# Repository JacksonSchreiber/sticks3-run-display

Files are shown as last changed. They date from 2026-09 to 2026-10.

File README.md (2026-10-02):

# StickS3 run display

A wrist display that shows two numbers while running: **heart rate** from a Bluetooth chest strap, and **pace** from the phone's GPS. Built on an [M5Stack StickS3](https://docs.m5stack.com/en/core/StickS3) in a cast silicone band, with a clip mount as an alternative to the band.

The point is to keep Strava recording on the phone, untouched, and still see live numbers without buying a running watch.

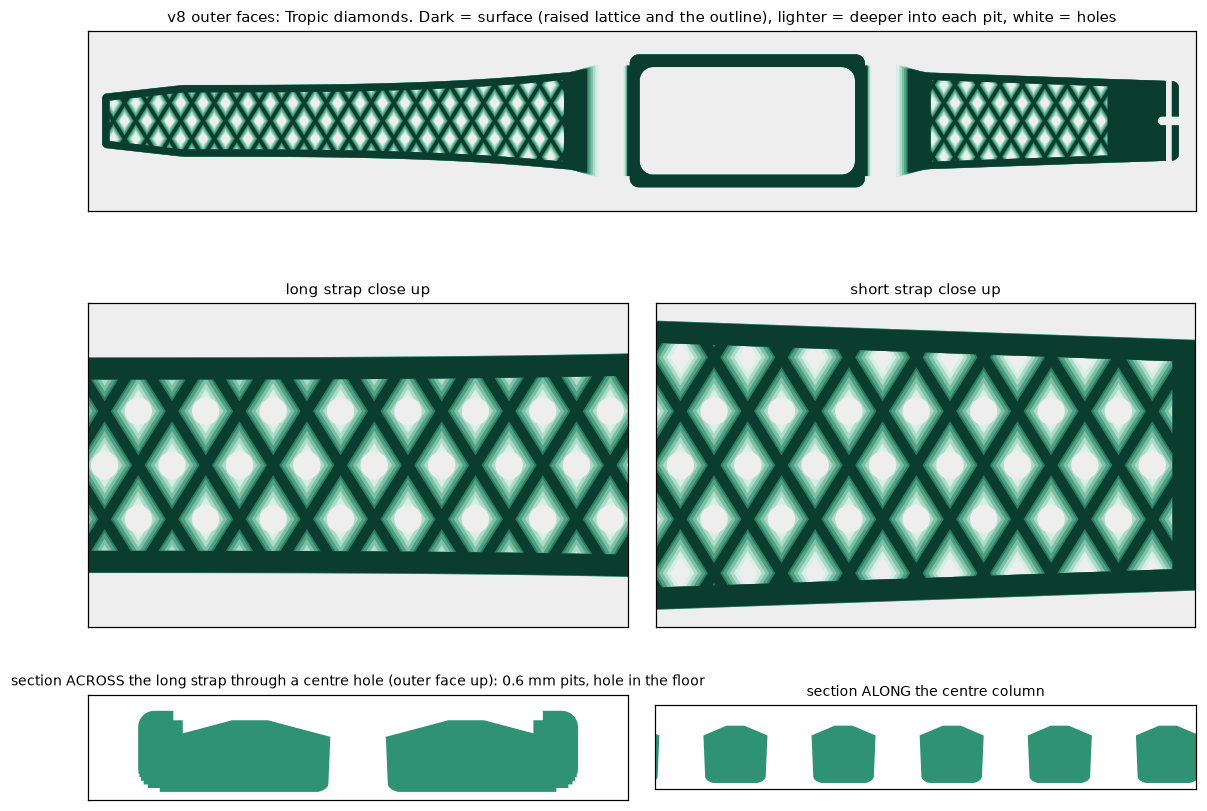
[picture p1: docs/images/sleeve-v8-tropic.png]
Band v8: outer faces tiled with Tropic diamond pits, the holes at their centres, with close ups and sections


*Band v8, the current design: a one-piece silicone band that flows out of a sealed jacket around the Stick, with Tropic-shaped straps: diamond pits tile the outer faces and the holes sit at their centres. The long strap tapers to a squared 12 mm tip; the short strap ends in a 4.5 mm thick tab with a cast hole for the spring bar of a real metal Tropic buckle and a slot for its tongue. Drawn from the mesh in `hardware/sleeve_v8/`.*

The earlier one-piece silicone band (a pocket in a cast band, no strap hardware) is still in `hardware/band/`:

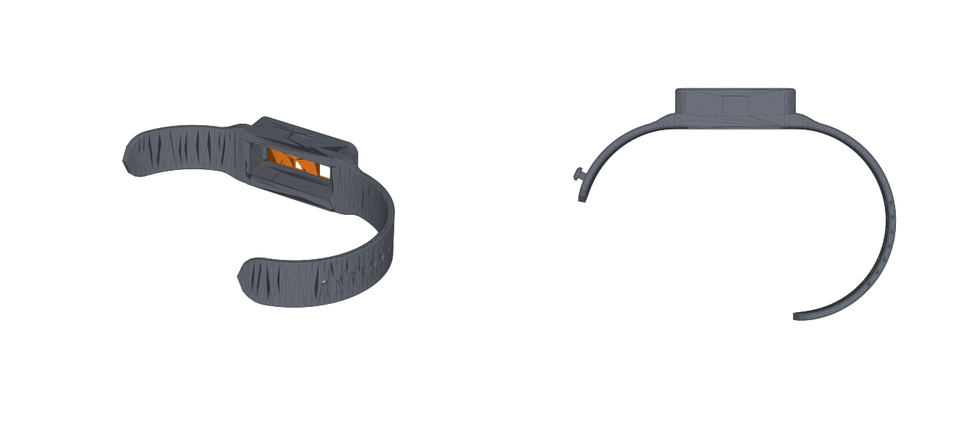
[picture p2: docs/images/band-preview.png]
The silicone band with the StickS3 in its pocket, and the band's side profile


## How it fits together

```
chest strap ──BLE──▶ phone ──BLE──▶ StickS3
                      │
              Strava (records the run, reads the strap itself)
              companion app (reads the strap, computes GPS pace,
                             sends both numbers ~1x/second)
```

The Stick never talks to the strap. It receives two numbers and displays them.

## Layout

| Path | What |
|---|---|
| `hardware/band/` | one-piece silicone band: 3-part mold (OpenSCAD source + STLs) |
| `hardware/clip/` | printed cradle that bolts to a steel spring clip (source + STLs) |
| `hardware/sleeve_v2/` | sealed silicone sleeve with cast-in lug staples for a standard 22 mm watch strap (source + STLs) |
| `hardware/sleeve_v3/` | sealed sleeve with the lugs under the ends (buried PETG frame with fins), 52 mm long (source + STLs) |
| `hardware/sleeve_v4/` | v3 with the frame flush in the back, 16 mm tall (source + STLs) |
| `hardware/sleeve_v5/` | one-piece silicone band + sealed jacket with a PETG peg buckle, Fitbit-style; cast twice (source + STLs) |
| `hardware/sleeve_v6/` | v5 band with a cast-in printed tang buckle, diamond-knurl straps, cast port slot; cast and run in (source + STLs) |
| `hardware/sleeve_v7/` | Tropic-shaped tapered straps for a real metal Tropic buckle (cast spring-bar hole and tongue slot), raised outline, knurl; cast twice, craters (source + STLs) |
| `hardware/sleeve_v8/` | current: v7 with Tropic perforation on both straps, smooth panels, breather holes and more vents (source + STLs) |
| `hardware/sleeve/` | earlier sleeve with a cast-in lug frame; superseded, kept for reference |
| `firmware/` | StickS3 firmware — not started |
| `app/` | Android companion app — not started |
| `docs/build-notes.md` | print settings, casting steps, assembly, tuning the fit |
| `docs/shopping-list.md` | everything to buy, with part numbers |

## Status

- **Band:** printed, cast and worn; fits well.
- **Sleeve:** v2 printed and cast, fits the Stick and the strap. v3 (lugs under the ends, 13 mm shorter) cast once: fit and strap work, but it sat 1 mm higher than the band and the first mold locked. v4 (frame flush with the back, 16 mm tall) is designed and verified. v5 drops the separate strap altogether: a one-piece band with the sealed jacket and a PETG peg buckle, cast twice and worn; the peg closure was awkward to use. v6 swapped in a printed tang buckle cast into the short strap: cast and run in, but the spring bar popped out of the printed lugs. v7 drops printed hardware altogether: Tropic-shaped straps that take a metal Tropic buckle on its own spring bar; cast twice, both with air craters. v8 adds Tropic perforation, breather holes and a brushed print-coat procedure, designed and verified, not yet cast.
- **Clip mount:** designed, not printed.
- **Firmware and app:** working. Real chest-strap heart rate reaches the Stick over BLE while Strava records the same strap; GPS pace is implemented but the outdoor walk test and the Stick battery run-down are still to do.

## Design decisions worth knowing

- **Dimensions** come from M5Stack's K150 drawing and official 3D model, not from measurements.
- **The Stick slips in and out of the band** — the silicone lip holds it, and the pocket covers USB-C, so charging means popping it out.
- **The clip keeps USB-C reachable,** so it charges in place.
- **All fasteners** come from one M2/M3 metric screw assortment.

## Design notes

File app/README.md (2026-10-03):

# Android companion app

Bridges the chest strap and the phone's GPS to the StickS3, while Strava records the run normally. It also records each run itself and can upload it to Strava with heart rate — for treadmill runs, where Strava's own recording missed it (see *Strava upload*).

Gradle project root is this folder; the single module is `app/`. Package / applicationId `dev.runstick.app`. Kotlin, plain Android Views, no Compose, no DI, no navigation library.

## What it does

While Strava records on the same phone, this app reads the strap over the standard Heart Rate service (0x180D), computes pace from GPS Doppler speed, and writes one 9-byte `DATA` packet per second to the RunStick, per `docs/ble-protocol.md`. A foreground service plus a partial wake lock keeps it going for 1-3 h with the screen off.

## Layout

| File | What |
|---|---|
| `app/src/main/java/dev/runstick/app/PacketEncoder.kt` | `RunData` -> 9 bytes LE, plus `StatusDecoder` for the 2-byte `STATUS` notification. Pure. |
| `HeartRateParser.kt` | 0x2A37 payload -> bpm (flags bit 0 picks u8 / u16 LE). Pure. |
| `PaceEstimator.kt` | time-aware EMA over `Location.getSpeed()` -> seconds per mile, or null. Pure. |
| `RunTracker.kt` | elapsed time + distance integrated from speed. Pure. |
| `HrZones.kt` | heart-rate zone 1-5 from % of max HR, with 2 bpm hysteresis. Pure. |
| `StrapClient.kt` | raw `BluetoothGatt` client for the strap. |
| `StickClient.kt` | Nordic `BleManager` client for the RunStick. |
| `RunService.kt` | foreground service: owns both clients + GPS, ticks at 1 Hz, holds the `UiState` flow. |
| `MainActivity.kt` | permissions, device pickers, start/stop, live readout, last workout + Strava setup, battery help. |
| `DevicePicker.kt` | the "which device?" dialog (connected devices + filtered scan). |
| `WorkoutLog.kt` | one recorded run (start time, 1 Hz HR + distance samples), its line-based file format and summaries. Pure. |
| `WorkoutStore.kt` | `filesDir/workouts/` (newest 50 kept; delete/prune report removals so Prefs entries go too) and the incremental `WorkoutRecorder`. java.io only. |
| `TcxWriter.kt` | `WorkoutLog` -> TCX v2 (no GPS positions), with the distance override. Pure. |
| `StravaApi.kt` | Strava URLs, form/multipart bodies, JSON parsing. Pure. |
| `UploadForm.kt` | upload dialog defaults, time/pace/miles parsing, the time-distance-pace calculator, stretch note. Pure. |
| `WorkoutUi.kt` | shared by both screens: the store factory, the summary line, the upload flow and dialog. |
| `WorkoutsActivity.kt` | workout history: upload / upload again, open on Strava, delete. |
| `StravaClient.kt` | token exchange/refresh, upload + poll over `HttpURLConnection`. |
| `StravaJobs.kt` | process-wide scope + state for connect/upload, so rotation doesn't cancel them. |
| `Prefs.kt` | strap MAC, stick MAC, simulate flag, Strava credentials and tokens, uploaded activity ids. |
| `app/src/test/…` | JUnit4 tests for the pure classes, including the protocol doc's golden vector and TCX golden output. |

## Rules that are easy to break

- **Never write CCCD `0x0000` to the strap, and never touch its CCCD on teardown.** Android gives each app its own GATT client over one shared link, but the strap's CCCD is one value on the device. Disabling it would silently stop Strava's heart-rate stream mid-run. Subscribing writes `0x0001` (idempotent); stopping is `disconnect()` + `close()` on our own client and nothing else. A failed CCCD write is not an error — arriving notifications are the only proof that matters.
- **Connect to the strap by saved MAC, not by scanning.** A strap that Strava already holds has stopped advertising, so a scan will never find it; `connectGatt()` on the address works either way. Scanning is only used for first-time picking, alongside `getConnectedDevices(GATT)`.
- **The service is started from the visible activity only.** That is what lets it use location without `ACCESS_BACKGROUND_LOCATION`, which is deliberately not requested. `START_NOT_STICKY` for the same reason.
- **Foreground service types are computed at runtime.** `connectedDevice` always; `location` only when not simulating and fine location is granted — claiming `location` without the permission throws on Android 14+.

## Heart-rate zones

Set **Max heart rate** on the main screen (120-230 bpm; unset by default) and the Stick shows the current zone as a coloured digit next to `BPM`: Z1 under 60% of max, Z2 60-70, Z3 70-80, Z4 80-90, Z5 90+. The zone moves up only once HR is 2 bpm past a boundary and down only once it is 2 bpm below, so it doesn't flicker at 1 Hz. It travels in DATA `flags` bits 5-7 (`docs/ble-protocol.md`) and only with a valid HR. The dialog shows the highest HR in saved runs as a hint, never filled in automatically (strap spikes). These are standard %-of-max zones; Strava's may differ unless set to match.

## Simulate mode

A persisted switch on the main screen. Ignores the strap and GPS and sends synthetic data (HR sweeping from 52% to 97% of max HR and back every two minutes so every zone colour shows, or of 190 when no max is set, in which case no zone is sent; pace 7:30-9:30, elapsed and distance ticking), so the Stick can be tested indoors. Location permission is not requested in this mode; Bluetooth still is, because it is still writing to a real Stick.

## Strava upload

Strava's own recording didn't capture heart rate on treadmill runs, so the app records every run itself and can upload it to Strava as a Run with heart rate and pace.

**Recording.** Every run (real or simulated) is written to `filesDir/workouts/workout_<startEpochMs>.csv`: one row per second with the same heart rate and distance the Stick is sent (HR blank when the strap has no fresh value). It is flushed every 5 s, so a crash loses a few seconds at most. Runs under 60 s are discarded; the newest 50 are kept. Recording needs no GPS fix — on a treadmill it just records HR with zero distance.

**Auto-stop.** If the strap has sent heart rate at least once in a run and then nothing arrives for 5 minutes (strap taken off, Stop forgotten), the run stops itself through the normal Stop path and a notification plus an on-screen note say so. Runs that never saw a heart rate (no strap) never auto-stop, and shorter dropouts are ignored.

**Trim.** An auto-stopped run is saved only up to its last heartbeat, so duration, distance and the uploaded TCX exclude the idle 5 minutes (the file is rewritten via a temp file + rename). A manual Stop saves the run untrimmed; the 60 s minimum applies after trimming.

**Upload.** *Last workout* on the main screen shows the newest run; **Upload to Strava** asks for a name, the time, the distance in miles or the pace, and whether it was a treadmill (`trainer=1`), builds a TCX file (time, distance and HR per second, no GPS positions) and posts it to Strava's upload API, then polls until the activity exists. The result links to the activity, and the workout is marked uploaded; uploading it again asks first and offers to open the old activity: while it still exists on Strava, Strava will most likely reject the new upload as a duplicate (its message is shown as-is), so delete it there first. Each attempt gets its own `external_id`; on success the new activity id replaces the old one. The app never deletes anything on Strava.

**All workouts.** Lists every kept workout, newest first (not the one being recorded). Tap one to upload it (or upload again), open it on Strava, or delete it from the phone; deleting leaves the Strava activity alone. Upload and Delete are disabled while an upload is running.

**Treadmill distance.** GPS gives no distance indoors, so type the treadmill's distance at upload time. If the recorded distance is under 100 m (none, or just GPS drift), the typed distance is spread evenly over the run, i.e. a constant pace. If there is a real recorded distance, the typed value rescales it, keeping the pace variations. Leaving the box at its prefilled value uploads the recorded distance unchanged.

**Typing what the treadmill shows.** Time is the anchor (mm:ss or h:mm:ss). Distance and pace are two views of one number: typing either fills in the other, and changing the time keeps whichever was typed last (on a GPS run nothing typed means the pace is kept, so the distance scales with the time). The upload uses the time and distance boxes. A typed time different from the recording *rescales* the whole timeline onto it, so Strava shows exactly the treadmill's time and the HR trace keeps its shape; nothing is trimmed, since the app can't know when the belt started. The dialog notes "Heart-rate trace is stretched to fit", in the warning colour beyond a 15% change. Squeezing to a shorter time drops samples that land on the same second, so the average HR can move slightly.

**One-time setup.**

1. On <https://www.strava.com/settings/api> create an API application (any name/website). Set **Authorization Callback Domain** to `localhost`.
2. In the app tap **Set up Strava**, paste the **Client ID** and **Client Secret**, tap **Connect**.
3. Strava (app or browser) asks for permission. Leave the **upload activities** permission ticked — without it the app cannot upload and tells you so.
4. You come back to RunStick showing *Strava: connected*. Tokens refresh themselves; if Strava ever refuses the refresh, the app asks you to connect again.

The redirect is `runstick://localhost/strava`, which is why the callback domain is `localhost`.

**Credentials live only on the phone.** Client ID, secret and tokens are kept in the app's private SharedPreferences (`allowBackup` is false) and are never logged. Nothing about your Strava app is in this repo; if you fork it, create your own API application.

## Versions

Set in `gradle/libs.versions.toml`, so one file changes them all.

| | |
|---|---|
| AGP | 9.4.1 (needs Gradle >= 9.6, JDK 17, build-tools 36) |
| Gradle wrapper | 9.7.1 |
| Kotlin | whatever AGP 9 bundles — see below |
| compileSdk / targetSdk / minSdk | 36 / 36 / 31 |
| Nordic BLE | `no.nordicsemi.android:ble:2.11.0` |

**AGP 9 compiles Kotlin itself.** The `org.jetbrains.kotlin.android` plugin is *rejected* by AGP 9 (`android.builtInKotlin` defaults to true), so it is not applied anywhere and no Kotlin version is declared. `kotlin.compilerOptions.jvmTarget` defaults to `android.compileOptions.targetCompatibility`, which is why JDK 17 is set only in the `compileOptions` block and there is no `kotlin { }` block. If that ever needs reverting: uncomment `android.builtInKotlin=false` in `gradle.properties`, the `kotlin` version + `kotlin-android` plugin lines in `gradle/libs.versions.toml`, and the plugin alias in `app/build.gradle.kts`.

androidx and coroutines versions are pinned conservatively — they are known to resolve and nothing here needs a newer API. Bump them in the catalog if you want.

## Building

There is no Gradle wrapper checked in yet. Generate it once on Windows (from an existing Gradle install or Android Studio), which creates `gradlew.bat` and `gradle/wrapper/gradle-wrapper.jar`; `gradle/wrapper/gradle-wrapper.properties` is already here and points at Gradle 9.7.1.

Gradle must run as a **Windows** process, never inside WSL — see `tools/env.sh`. It expects:

- `JAVA_HOME` = `C:\Program Files\Eclipse Adoptium\jdk-17*`
- `ANDROID_HOME` = `%LOCALAPPDATA%\Android\Sdk` — or create `app/local.properties` with `sdk.dir=C\:\\Users\\<you>\\AppData\\Local\\Android\\Sdk` (it is gitignored)
- `adb.exe` from the WinGet `Google.PlatformTools` package

From Windows, in this folder:

```
gradlew.bat test                 # JVM unit tests only, no device needed
gradlew.bat assembleDebug        # app/build/outputs/apk/debug/app-debug.apk
gradlew.bat installDebug         # build + install over adb
```

`tools/build-app.sh` and `tools/install-app.sh` are the WSL-side wrappers (not written yet — they belong outside this folder). They should source `tools/env.sh` and then:

```sh
# build-app.sh
cmd.exe /c "cd /d $REPO_WIN\\app && set JAVA_HOME=$JAVA_HOME_WIN&& gradlew.bat assembleDebug"

# install-app.sh
"$ADB" install -r "$REPO_WSL/app/app/build/outputs/apk/debug/app-debug.apk"
```

## First run on the phone

1. Grant permissions (Bluetooth, location, notifications).
2. **Pick RunStick** — scans for service `7a1c0001-…`; the Stick must be powered and advertising.
3. **Pick strap** — devices already connected (i.e. held by Strava) are listed first and labelled; otherwise it scans for 0x180D.
4. Open the **battery** card: tap *Ignore battery optimisation*, then on a Samsung set Settings → Apps → RunStick → Battery → **Unrestricted** and add the app to **Never auto sleeping apps**.
5. Start Strava, then Start here. Order does not matter, but step 3 is easiest with Strava already connected, since that proves both apps can read the strap at once.

## Still open

- **Milestone 1:** confirm Strava and this app read the strap at the same time on this phone. Everything above is written to make that possible, but it has not been tried.
- Pace will not match Strava's exactly — each app smooths GPS differently. This one uses a time-aware EMA with alpha 0.22 at 1 Hz (~8 s), rejects samples with speed accuracy worse than 1 m/s, and shows `--` below 0.5 m/s or after 10 s with no usable sample. Distance uses a tighter 4 s gap limit than pace's 10 s staleness window, so a dropout can't invent ground.

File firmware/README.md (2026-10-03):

# StickS3 firmware

Runs on the M5Stack StickS3 (ESP32-S3). Its whole job is to receive two numbers
over Bluetooth LE and display them large enough to read at a glance mid-stride.

The Stick is a dumb BLE peripheral: it never talks to the chest strap or the
GPS. The phone app writes one 9-byte packet about once a second and the Stick
draws it. The wire format is `docs/ble-protocol.md` — that file is the contract,
change it first.

## Files

| Path | What |
|---|---|
| `runstick/runstick.ino` | setup/loop, screen state machine, buttons, power management, serial log |
| `runstick/config.h` | UUIDs, timings, brightness steps, colours, portrait layout |
| `runstick/protocol.h` | `RunData` + `parsePacket()` + the format helpers — no Arduino/M5/NimBLE dependency |
| `runstick/ble_link.h` | NimBLE server, advertising, callbacks, thread-safe packet handoff, STATUS notify |
| `runstick/ui.h` | sprite drawing for the boot / main / extras / sleeping screens |

Header-only on purpose: the `.h` files are included from the `.ino` and compile
as one translation unit, so everything is `inline`/`static`.

## Building

```
tools/build-firmware.sh
```

That wrapper runs the Windows `arduino-cli.exe` through WSL interop (see
`tools/env.sh`) so the compile never uses WSL memory. What it does, in effect:

```
arduino-cli compile --fqbn m5stack:esp32:m5stack_sticks3 \
  --build-path 'C:\dev\.build\runstick' firmware/runstick
arduino-cli upload  --fqbn m5stack:esp32:m5stack_sticks3 -p COM7 firmware/runstick
```

Pinned versions this was written against:

| Thing | Version |
|---|---|
| core | `m5stack:esp32@3.3.9` (Arduino-ESP32 3.x) |
| `M5Unified` | 0.2.22 |
| `M5GFX` | 0.2.29 |
| `NimBLE-Arduino` | 2.5.1 |

The BLE code targets the **NimBLE 2.x** API, which is not the API in most
tutorials: advertising does not restart itself after a disconnect, the device
name is not added to the advertisement for you, and the callbacks carry a
`NimBLEConnInfo&`. See the comment block at the top of `ble_link.h`.

### Serial

115200 baud over native USB CDC. If the port enumerates but prints nothing, the
board menu option is not set to CDC — add it to the FQBN:

```
--fqbn m5stack:esp32:m5stack_sticks3:CDCOnBoot=cdc
```

### Self-test

`protocol.h` carries the golden vector from the protocol doc. Build with

```
--build-property "compiler.cpp.extra_flags=-DRUNSTICK_SELFTEST"
```

and the Stick parses it at boot and prints a PASS/FAIL line per check to Serial:
field decode, the second (zone 4) vector and the `hr_zone` bits, short/long/null/wrong-version rejection, and every display
format (`8:45`, `1:02:03`, `7.12 mi`). Leave the flag off for normal builds.

## Screen

Portrait, 135 wide x 240 tall — the Stick lies *across* the wrist.

```
 ┌─────────────────┐
 │ ● LINK      87% │  status strip: link dot + state, battery %
 ├─────────────────┤
 │                 │
 │      152        │  heart rate, white, as large as 135 px allows
 │       BPM       │  label red
 ├─────────────────┤
 │                 │
 │      8:45       │  pace, white
 │       /MI       │  label cyan
 └─────────────────┘
```

The link dot is green when a fresh packet arrived within 5 s, amber when the
data has gone stale, grey while waiting for a phone.

Digit size is **measured, not guessed**: `fitBigText()` in `ui.h` walks a short
list of fonts (the 75 px and 48 px 7-segment fonts first, then FreeSansBold as a
full-ASCII safety net), measures the actual string with `textWidth()`, and picks
whichever renders the tallest digits that still fit the box. So `99` gets more
height than `152`, and `12:34` more than `8:45` would need. At boot the
per-glyph width table for every candidate font is dumped to Serial, which is the
first place to look if a number ever comes out clipped or blank.

Everything is drawn into one 135x240 `M5Canvas` sprite and pushed in a single
blit, so nothing flickers. The screen is only repainted when something changed,
or once a second regardless.

### Stale rule

No valid DATA packet for 5 s → both numbers become a dark grey `--` and the
strip shows `STALE`. If the link drops, the last numbers stay on screen for the
remainder of those 5 s rather than blanking instantly. If a packet arrives with
a field's valid bit clear (or pace `0xFFFF`), just that field shows `--`.

### Extras screen

`BtnA` short press. Shows elapsed time, distance, the Stick's own battery
(`CHG` when charging) and the phone-side flags (`GPS ok` / `STRAP ok`). Returns
to the main screen after 5 s, or on another `BtnA` press.

## Buttons

`M5.BtnA` is the front button (GPIO11); `M5.BtnB` is the side KEY2 (GPIO12).
The other side button belongs to the PMIC and is not software-readable — hold it
for download mode, double-click it to power off.

| Button | Action | Effect |
|---|---|---|
| A | short press | toggle the extras screen (auto-returns after 5 s) |
| B | short press | cycle the backlight: 40 → 110 → 220 → 40 (saved in NVS, default 110) |
| B | hold ≥ 1 s | flip the screen 180° for the other wrist (saved in NVS) |

Both B actions are on raw press/release edges rather than M5Unified's
`wasClicked()`/`wasHold()`, so the 1 s threshold is exactly 1 s. The long press
fires the moment it is reached, and the release is then swallowed.

## Power

- CPU is dropped to 80 MHz once BLE is up (the floor with the radio on) and the
  loop idles at ~20 ms.
- Connection parameters are requested at 300–500 ms / latency 0 / 6 s timeout,
  since the phone only writes at 1 Hz.
- IMU, mic, speaker and the Grove 5 V output are disabled in `M5.config()`.
- **Idle power-off:** 10 minutes with no phone *and* not on USB → a 3 s
  "Sleeping" notice, then `M5.Power.powerOff()`. A button press, a phone
  connecting, or USB going in during those 3 s cancels it.

## Serial log

One line a second while connected, plus a line for every connect/disconnect
(with the NimBLE reason code):

```
[run] hr=152 pace=8:45  t=1:02:03 d=7.12 mi flags=0x1F HR PACE RUN GPS STRAP age=412ms batt=87% 4012mV -83mA pkt=123 bad=0
```

`mA` is signed (negative = discharging) and is there to tune the 2 h battery
target against. If it reads a constant `0`, this board has no current sense —
that is the hardware, not the logging.

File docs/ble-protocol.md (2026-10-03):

# BLE protocol: phone → RunStick

This file is the contract between `firmware/` and `app/`. Change it first, then both sides.

## Roles

- **Stick = BLE peripheral / GATT server.** It only displays what it is sent.
- **Phone app = BLE central / GATT client.** It reads the chest strap and GPS and writes one packet about once a second.

## Advertising

| Field | Value |
|---|---|
| Local name | `RunStick` (in the advertising data itself, not only the scan response) |
| Service UUID | `7a1c0001-5f3e-4b2a-9c6d-2f8e41d0b7a5` (advertised) |
| Connectable | yes; restarts advertising on every disconnect |

The app finds the Stick by service UUID, then remembers its MAC address.

## GATT

Service `7a1c0001-5f3e-4b2a-9c6d-2f8e41d0b7a5`

| Characteristic | UUID | Properties | Direction |
|---|---|---|---|
| `DATA` | `7a1c0002-5f3e-4b2a-9c6d-2f8e41d0b7a5` | write without response (also accepts write) | phone → Stick |
| `STATUS` | `7a1c0003-5f3e-4b2a-9c6d-2f8e41d0b7a5` | read, notify | Stick → phone |

No pairing or bonding. Default MTU is enough.

### DATA — 9 bytes, little-endian

| Offset | Type | Field | Notes |
|---|---|---|---|
| 0 | u8 | `version` | `1`. The Stick ignores packets with an unknown version or the wrong length. |
| 1 | u8 | `flags` | see below |
| 2 | u8 | `hr_bpm` | heart rate; `0` when not valid |
| 3 | u16 | `pace_s_per_mile` | seconds per mile; `0xFFFF` when not valid (stopped, no GPS) |
| 5 | u16 | `elapsed_s` | seconds since the run started (wraps after 18.2 h) |
| 7 | u16 | `distance_cmi` | distance in 0.01 mile units |

`flags` bits:

| Bit | Name | Meaning |
|---|---|---|
| 0 | `HR_VALID` | `hr_bpm` is a fresh reading from the strap |
| 1 | `PACE_VALID` | `pace_s_per_mile` is usable |
| 2 | `RUN_ACTIVE` | the run timer is running |
| 3 | `GPS_OK` | the phone has a usable GPS fix |
| 4 | `STRAP_OK` | the phone is connected to the chest strap |
| 5–7 | `hr_zone` | 3-bit heart-rate zone, `(flags >> 5) & 7`: `0` = none / unknown, `1`–`5` = zone. `6` and `7` are treated as `0` on receive. |

A field is shown only if its valid bit is set; otherwise the Stick shows `--`.

**`hr_zone`.** The phone computes the zone (percent of the runner's max heart rate, with hysteresis so it doesn't flicker on a boundary) and sends it only when `HR_VALID` is set; otherwise the bits are `0`. The Stick shows it as a coloured digit next to the `BPM` label, only while the heart rate itself is shown. Bits 5–7 used to be "reserved, send `0`, ignore on receive", and the length and `version` are unchanged: firmware from before this field never checked those bits (its `parsePacket` accepts any `flags` value and reads only bits 0–4), so a newer app works with an older Stick, which simply shows no zone. An older app sends `0`, which means "no zone".

**Golden test vectors** (both sides unit-test against them):

```
HR 152, pace 8:45 /mi (525 s), elapsed 1:02:03 (3723 s), distance 7.12 mi (712), all five flags set, zone 0

01 1F 98 0D 02 8B 0E C8 02
```

```
The same, with hr_zone 4: flags = 0x1F | (4 << 5) = 0x9F

01 9F 98 0D 02 8B 0E C8 02
```

### STATUS — 2 bytes

| Offset | Type | Field | Notes |
|---|---|---|---|
| 0 | u8 | `battery_pct` | 0–100 |
| 1 | u8 | `status_flags` | bit 0 = charging |

Notified when either byte changes, and at least every 60 s while connected.

## Timing

- The phone writes `DATA` at **1 Hz**, including when values are invalid, so the Stick can tell "connected but no data" from "link lost".
- **Stale rule:** if the Stick gets no valid `DATA` packet for **5 s**, it greys out the numbers to `--` and shows a no-link indicator. It keeps advertising / waiting and recovers on the next packet.
- Preferred connection parameters requested by the Stick: interval 300–500 ms, latency 0, supervision timeout 6 s. The phone may ignore these.

## Display formats (Stick)

| Value | Format | Example |
|---|---|---|
| heart rate | integer | `152` |
| heart-rate zone | one digit `1`–`5` right of the `BPM` label, coloured per zone; nothing for `0` | `4` |
| pace | `m:ss`, capped at `59:59` | `8:45` |
| elapsed | `h:mm:ss` (or `mm:ss` under an hour) | `1:02:03` |
| distance | two decimals + `mi` | `7.12 mi` |

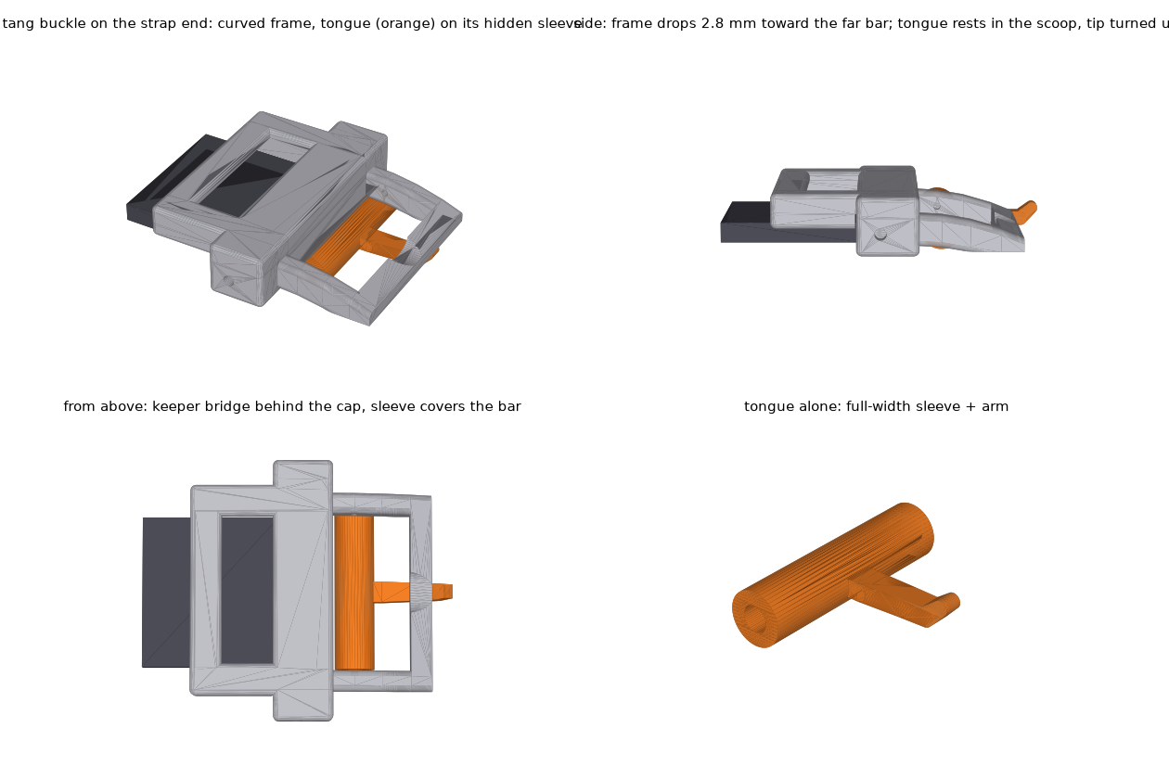
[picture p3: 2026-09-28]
docs/images/buckle-tang.png

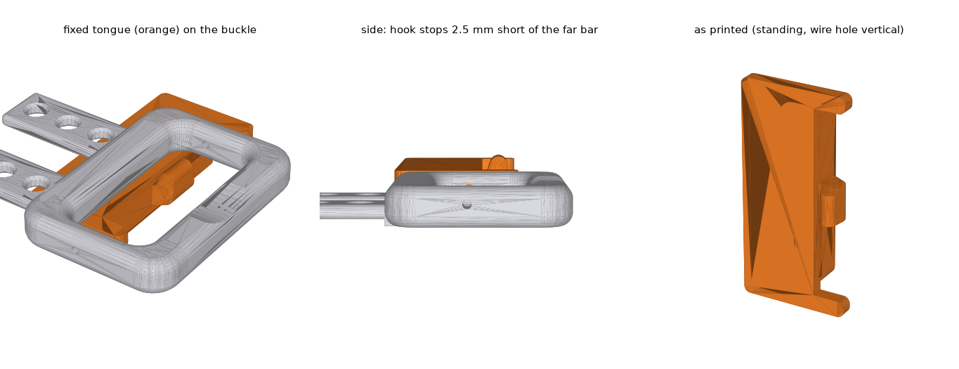
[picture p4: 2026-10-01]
docs/images/fixed-tongue.png

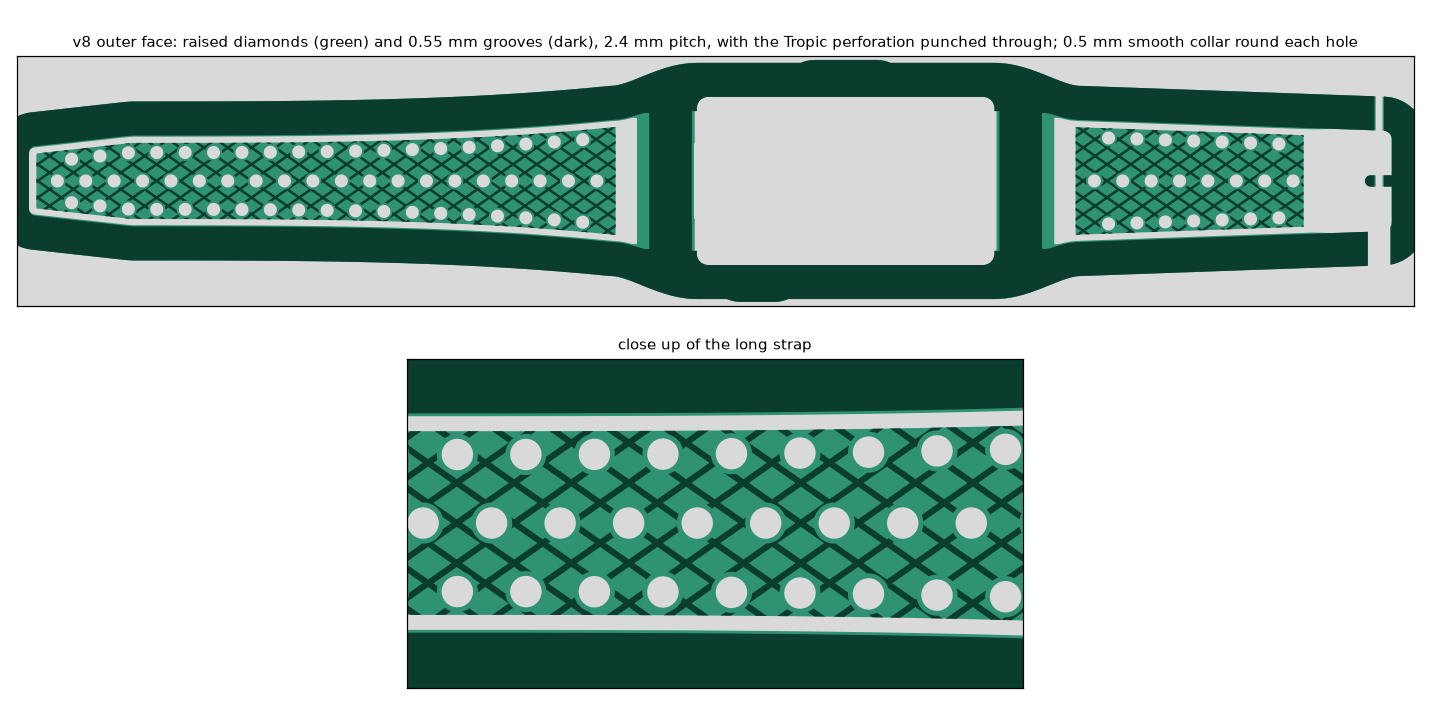
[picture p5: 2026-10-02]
docs/images/sleeve-v8-knurl.png

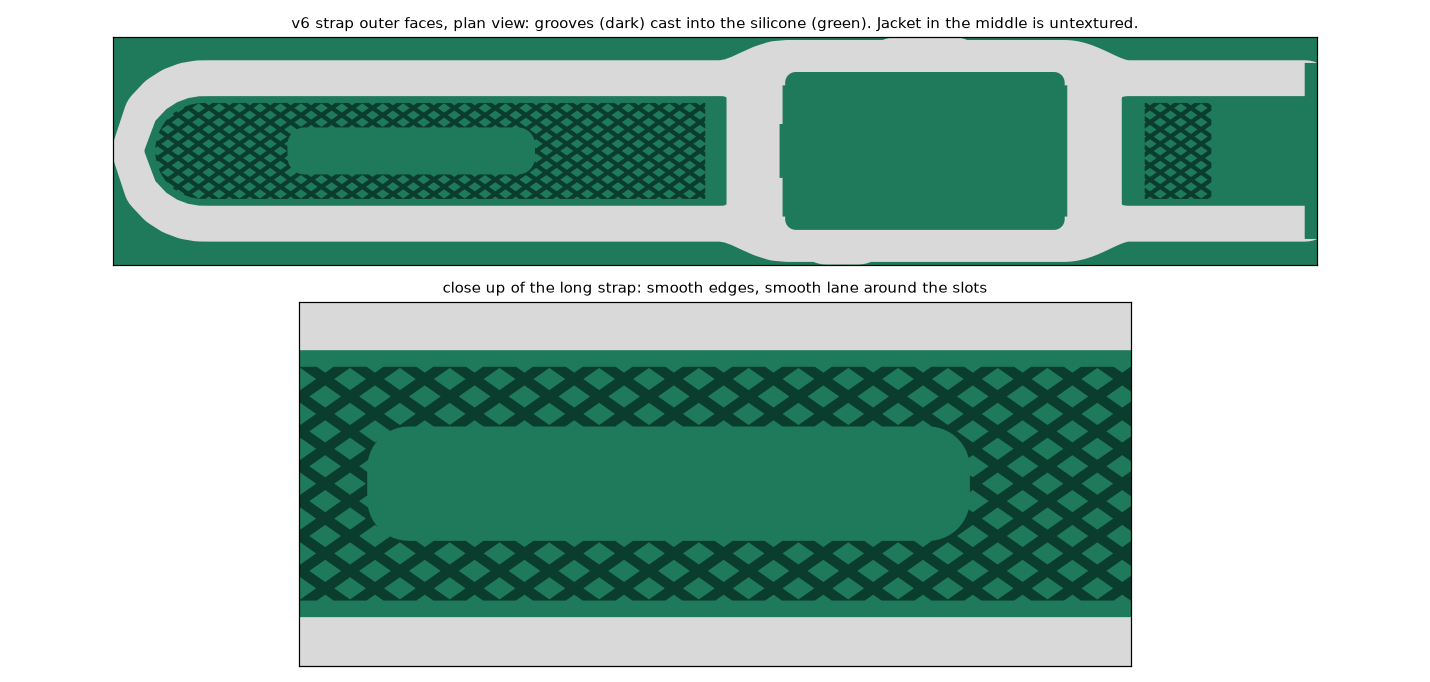
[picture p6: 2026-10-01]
docs/images/sleeve-v6-texture.png

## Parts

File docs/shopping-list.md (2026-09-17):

# Shopping list

Prices are what was listed when this was written; check before ordering.

## Electronics

- **M5Stack StickS3** (K150) — $21.50
- **Chest strap:** Coospo H9Z (USB rechargeable, ~50 h per charge) — $43.89 on sale, or Coospo H808S (CR2032 coin cell, ~300 h) — $35.09. Any strap using the standard Bluetooth heart rate service works.
- **USB-C data cable** — charge-only cables can't program the Stick

## 3D printing

The Adventurer 5M ships with a glue stick, diagonal pliers, hex keys and a 50 g PLA sample.

- **PLA filament, 1.75 mm, 1 kg** — mold and core
- **PETG filament, 1.75 mm, 1 kg** — clip mount
- **Digital calipers**
- **Isopropyl alcohol, 90%+** — cleaning the build plate
- **Sandpaper, 220-800 grit** — flattening the mold parting faces
- Optional: deburring tool, airtight bin + desiccant for filament

## Silicone casting

- **Smooth-On Smooth-Sil 945, 2 lb trial kit** (skin safe, Shore 45A, 1:1 by weight). Amazon alternative: SORTA-Clear 37, also skin safe, slightly softer, 4 h cure.
- **Mann Ease Release 200** — mold release spray
- **Silc Pig black pigment** (or any pigment made for platinum-cure silicone) — 1.5-2% by weight, never over 3%
- **Digital scale, 0.1 g**
- **Graduated mixing cups and wooden stir sticks**
- **Vinyl gloves** — latex stops platinum silicone from curing
- **60 ml catheter-tip syringes**, 2-3
- **3 mm leather hole punch** — strap holes
- **Hobby knife** — trimming the seam and vent nubs
- Safety glasses, mostly for the aerosol release spray

## Clip

- **theclip.com MCS-631SS** stainless spring clip — $4.25. Alternative: MCS-661, shorter but coated steel.

## Fasteners

One metric screw assortment covers every part: M2/M3, socket-cap or button head, with nuts and washers. Confirm the size chart lists **M2x6** and **M3x30**. Stainless holds up better than black alloy steel against sweat.

## Software (free)

- **Orca-Flashforge / Flash Studio** — slicer
- **OpenSCAD** — only to change a design
- **Arduino IDE 2** and **Android Studio** — later, for firmware and the app

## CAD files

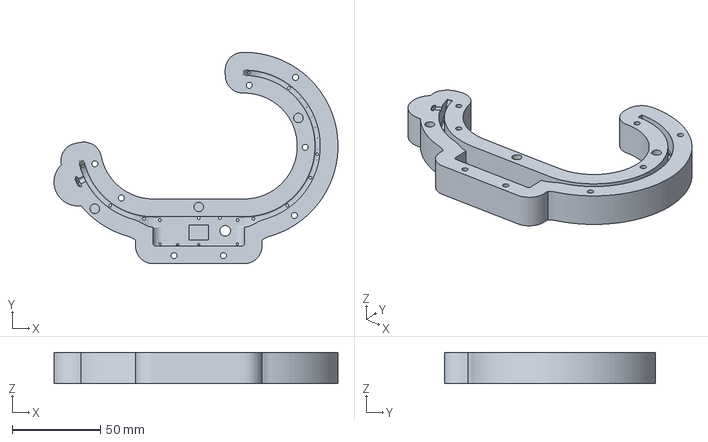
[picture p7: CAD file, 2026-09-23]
hardware/band/print/band_mold_top.3mf
160.8 x 119.6 x 17.8 mm

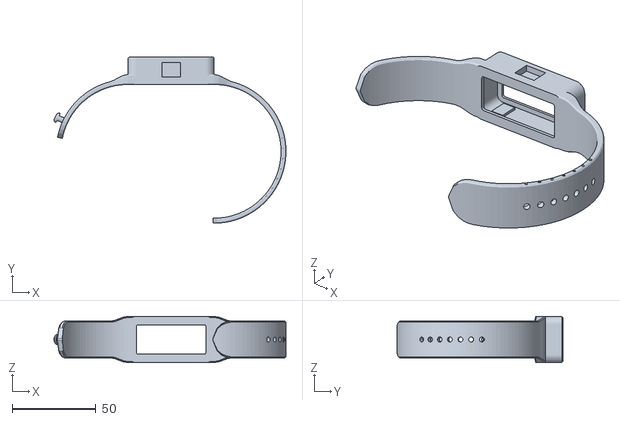
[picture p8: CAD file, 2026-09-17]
hardware/band/stl/band_preview_not_for_printing.stl
138.9 x 99.6 x 27.6

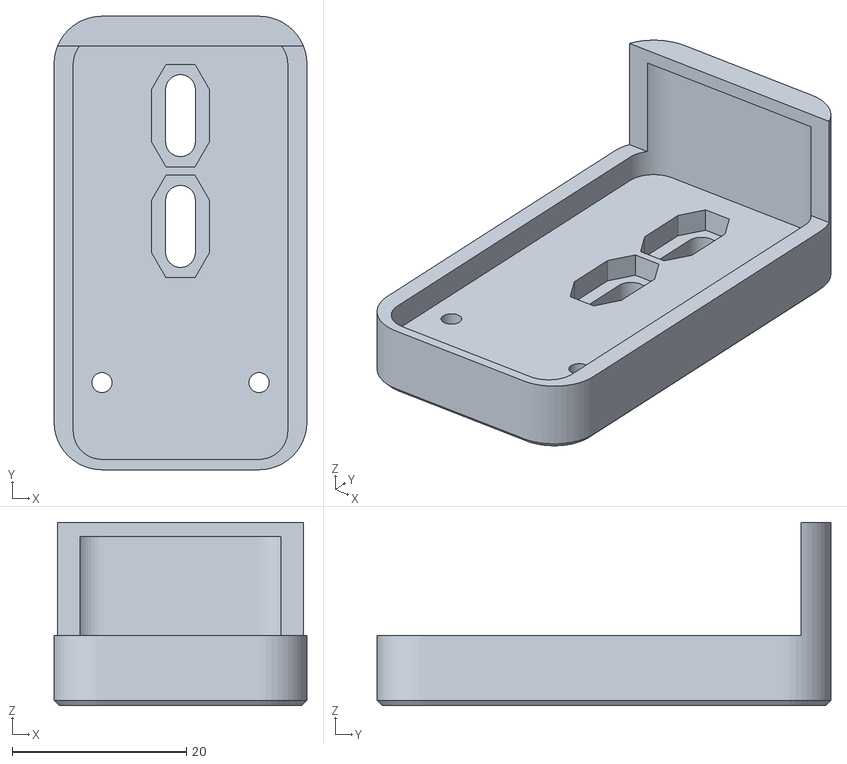
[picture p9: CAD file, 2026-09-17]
hardware/clip/stl/clip_mount_661.stl
29.0 x 52.0 x 21.0

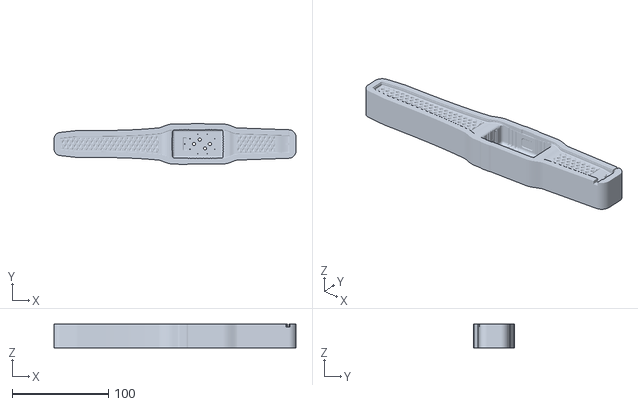
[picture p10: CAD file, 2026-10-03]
hardware/sleeve_v8/stl/band_cup.stl
252.0 x 42.6 x 24.9

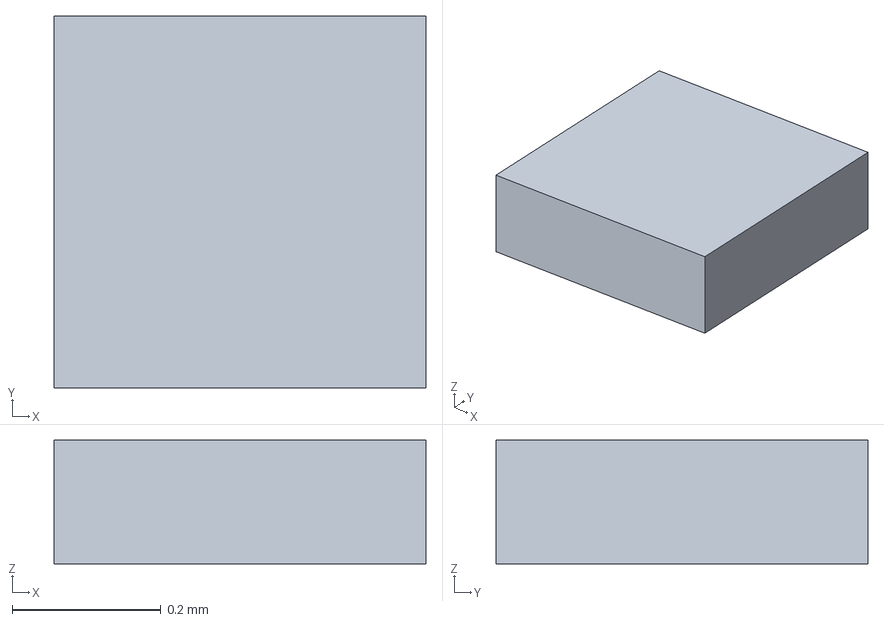
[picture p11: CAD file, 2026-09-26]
tools/heat_45C_6hrs.3mf
0.5 x 0.5 x 0.167 mm

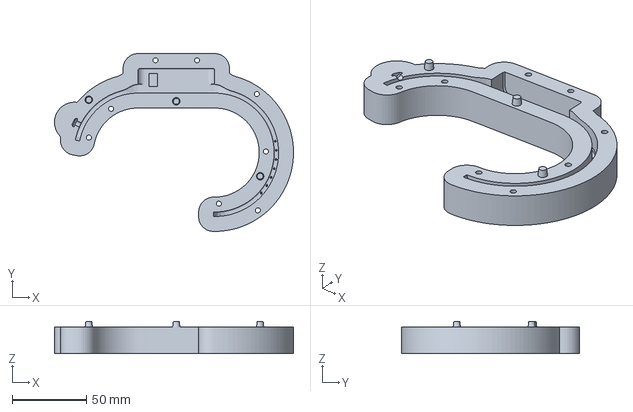
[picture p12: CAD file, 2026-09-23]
hardware/band/print/band_mold_bottom.3mf
160.8 x 119.6 x 21.8 mm

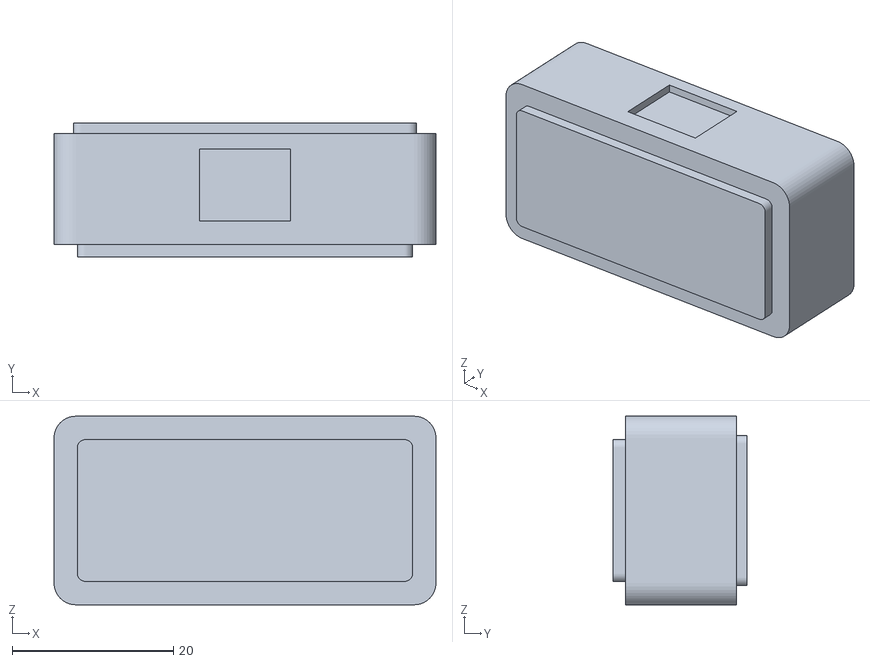
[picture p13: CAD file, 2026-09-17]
hardware/band/stl/band_core_tighter.stl
47.4 x 16.6 x 23.4

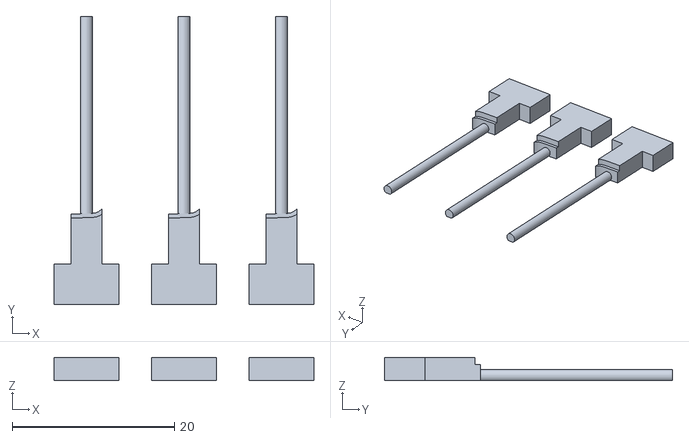
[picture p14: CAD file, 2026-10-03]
hardware/sleeve_v8/stl/band_pin_x3.stl
32.0 x 35.5 x 2.85

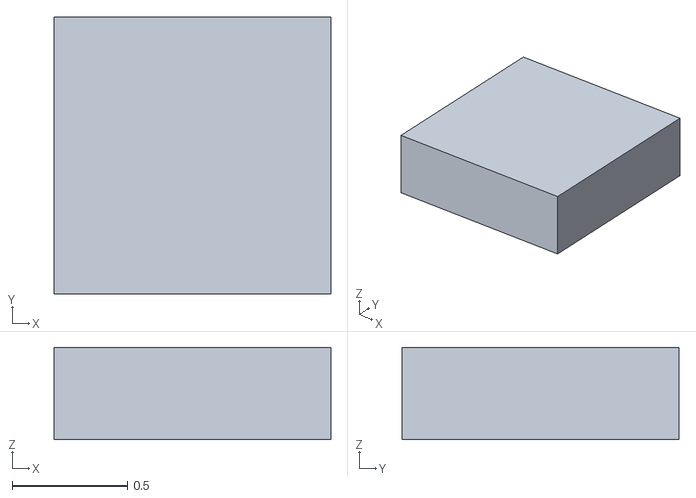
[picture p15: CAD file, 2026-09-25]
tools/dot_1mm.stl
1.20 x 1.20 x 0.4

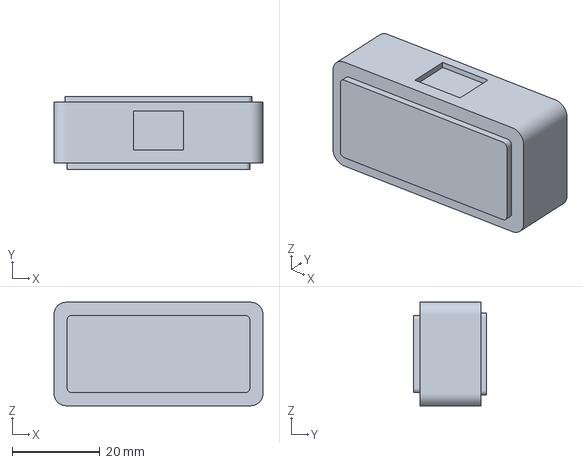
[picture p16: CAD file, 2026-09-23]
hardware/band/print/band_core_default.3mf
47.6 x 16.6 x 23.6 mm

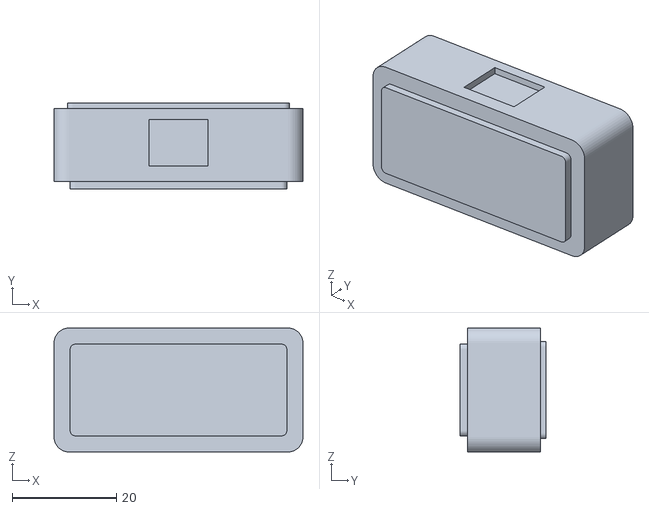
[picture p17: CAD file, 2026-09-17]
hardware/band/stl/band_core_looser.stl
47.8 x 16.6 x 23.8

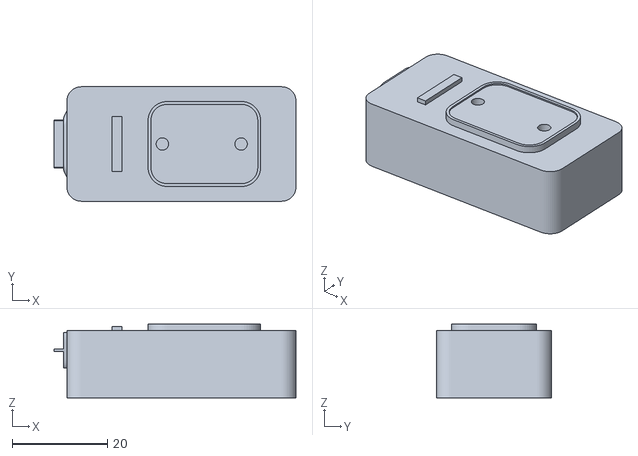
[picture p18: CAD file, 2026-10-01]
hardware/sleeve_v8/stl/band_core.stl
50.7 x 24.0 x 15.5

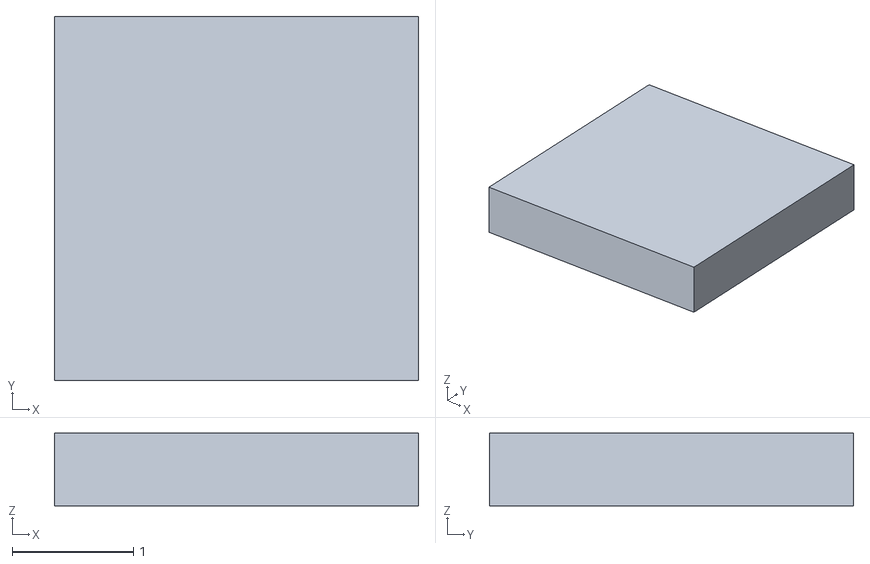
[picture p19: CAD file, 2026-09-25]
tools/dot_3mm.stl
3.00 x 3.00 x 0.6

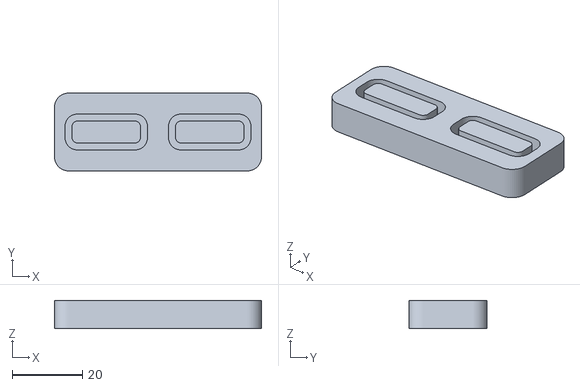
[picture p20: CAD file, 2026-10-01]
hardware/sleeve_v8/stl/keeper_mold.stl
59.0 x 22.2 x 8.00

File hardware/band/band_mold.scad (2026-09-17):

// One-piece silicone watch band with a slip-in pocket for the M5Stack StickS3
// Cast in Smooth-On Smooth-Sil 945 (Shore 45A, skin safe) in a 3D-printed mold.
//
// Parts (set `part`, or use the Customizer):
//   "mold_bottom"  PLA, print as exported (parting face up), no supports
//   "mold_top"     PLA, print as exported (parting face up), no supports; has the pour hole + vents
//   "core"         PLA, print as exported (standing on its side); forms the Stick pocket + windows
//   "band"         preview of the finished band (don't print); console shows silicone volume
//
// The band is molded pre-curved so it fits a 220 mm bed and wraps the wrist.
// The Stick lies across the wrist; screen and front button stay exposed and the
// side buttons have openings. Closure: silicone stud through a punched hole, then
// tuck the tail under the band (like an Apple Sport Band). No hardware.
//
// Casting:
//   1. Sand the parting faces flat. Spray the halves and core with Ease Release 200.
//   2. Lay the core in the bottom half (window pads against the cavity walls,
//      side-button post in its side opening), close the top half, bolt with 8x M3x30
//      + nuts (heads and nuts drop into the pockets on the outer faces). Snug.
//   3. Mix ~27 ml Smooth-Sil 945 (1A:1B by weight), inject slowly through the pour
//      hole with a 60 ml syringe until silicone shows at every vent. Tap to free bubbles.
//   4. Wait 6 h. Unbolt, lift the band + core out, stretch the front lip over the
//      core to pop it out. Trim vent nubs and the seam.
//   5. Punch the 7 strap holes with a 3 mm leather punch, centred between the
//      little notches on the strap edges.

/* [Part] */
part = "band"; // [mold_bottom, mold_top, core, band]

/* [Sizing] */
// Snug wrist circumference, mm
wrist = 165;
// Middle hole = wrist + this. Holes step hole_pitch either side.
fit_ease = 5;
hole_count = 7;
hole_pitch = 6;

/* [Band] */
strap_w = 22;
strap_t = 3.0;
// Stick is this much bigger than the pocket, per side (grip). Only the core changes:
// 0.1 looser, 0.2 default, 0.3 tighter.
squeeze = 0.2;
// Molded curvature of the straps (inner surface)
R_mold = 40;

/* [Hidden] */
$fn = 40;
eps = 0.01;

// ---- StickS3 (K150), from M5Stack's drawing + official 3D model ------------
STICK_W = 24; STICK_L = 48; STICK_T = 14.08; STICK_R = 3;
// Side buttons measured on M5Stack's model: [y0, y1] from the USB-C end; BTN_Z from the back
BTN_XMINUS = [6.0, 11.0];     // power / reset side
BTN_XPLUS  = [19.0, 29.0];    // KEY2 side
BTN_Z = [3.6, 11.2];

// ---- Pocket ----------------------------------------------------------------
wall = 2.0;
front_lip = 2.5;   // how far the front lip covers the Stick's face
front_t = 1.2;
back_lip = 3.0;
back_t = 1.5;
btn_margin = 0.5;

// The mold halves are sized from a fixed nominal pocket so changing `squeeze`
// only changes the core: reprint the small core to tune grip, not the halves.
NOM_SQUEEZE = 0.2;
CORE_W_NOM = STICK_W - 2 * NOM_SQUEEZE;
POCKET_L = STICK_L - 2 * NOM_SQUEEZE + 2 * wall;
POCKET_W = CORE_W_NOM + 2 * wall;
POCKET_T = back_t + STICK_T - NOM_SQUEEZE + front_t;
POCKET_R = STICK_R - NOM_SQUEEZE + wall;
PL = POCKET_L / 2;
CORE_L = STICK_L - 2 * squeeze;
CORE_W = STICK_W - 2 * squeeze;
CORE_T = STICK_T - squeeze;
CORE_R = STICK_R - squeeze;
CORE_N0 = back_t;
CORE_N1 = back_t + CORE_T;

// ---- Straps & closure ------------------------------------------------------
// Worn size at hole i  ~=  POCKET_L + L_stud + L_hole(i)
L_stud = 45;                 // pocket end -> stud centre (short strap)
short_len = L_stud + 10;
mid_size = wrist + fit_ease;
function L_hole(i) = (mid_size - POCKET_L - L_stud) + (i - (hole_count - 1) / 2) * hole_pitch;
function band_size(i) = POCKET_L + L_stud + L_hole(i);
long_len = L_hole(hole_count - 1) + 35;   // tail to tuck
root_len = 10;               // strap thickens / widens into the pocket
root_t = 6;
stud_shaft_d = 3.2;
stud_shaft_h = strap_t + 0.3;
stud_head_d = 6.0;
hole_d = 3.0;

// ---- Mold ------------------------------------------------------------------
mold_margin = 10;
mold_floor = 4;
HZ = POCKET_W / 2 + mold_floor;       // each half's thickness
bolt_d = 3.4;
bolt_pocket_d = 7.0;     // recess for the bolt head / nut on each outer face
bolt_pocket_h = 4.0;     // 2x4 mm recessed, so M3x30 spans the closed mold
vent_d = 1.6;
sprue_d = 6;
post_key = 1.0;                       // side-button posts sink this far into the core to locate it
post_clear = 0.15;

echo(str("Band size at each hole (mm): ", [for (i = [0 : hole_count - 1]) band_size(i)]));
echo(str("Short strap ", short_len, " mm, long strap ", long_len, " mm, total ", POCKET_L + short_len + long_len, " mm"));

// ---- Path: flat under the pocket, then arcs of R_mold ----------------------
// s < 0: short strap (USB-C end), s > 0: long strap (top end); n = outward from the skin side
function phi(s) = (abs(s) - PL) / R_mold * 180 / PI;
function frame(s) = abs(s) <= PL ? [s, 0, 0] :
    let(p = phi(s), g = sign(s))
    [g * (PL + R_mold * sin(p)), -R_mold + R_mold * cos(p), -g * p];
function pt(s, n) = let(f = frame(s)) [f[0] - n * sin(f[2]), f[1] + n * cos(f[2])];

module at(s, n = 0) {
    f = frame(s);
    translate([f[0] - n * sin(f[2]), f[1] + n * cos(f[2]), 0]) rotate([0, 0, f[2]]) children();
}

function smooth(x) = let(c = max(0, min(1, x))) c * c * (3 - 2 * c);
function w_at(s) =
    let(d = abs(s) - PL, L = s < 0 ? short_len : long_len, r = strap_w / 2,
        base = POCKET_W + (strap_w - POCKET_W) * smooth(d / root_len))
    d > L - r ? 2 * sqrt(max(0.25, r * r - pow(d - (L - r), 2))) : base;
function t_at(s) = let(d = abs(s) - PL) root_t + (strap_t - root_t) * smooth(d / root_len);

// thin cross-section (octagon, 0.6 mm edge chamfer) in the local n-w plane
module xsec(t, w, c = 0.6) {
    cc = min(c, w / 4, t / 4);
    rotate([0, 90, 0]) linear_extrude(eps, center = true)
        polygon([[-(w / 2 - cc), 0], [w / 2 - cc, 0], [w / 2, cc], [w / 2, t - cc],
                 [w / 2 - cc, t], [-(w / 2 - cc), t], [-w / 2, t - cc], [-w / 2, cc]]);
}

function stations(L, sg) = let(n = ceil(L / 2.5)) concat([sg * (PL - POCKET_R)], [for (i = [0 : n]) sg * (PL + L * i / n)]);

module strap(sg) {
    st = stations(sg < 0 ? short_len : long_len, sg);
    for (i = [0 : len(st) - 2]) hull() {
        at(st[i]) xsec(t_at(st[i]), w_at(st[i]));
        at(st[i + 1]) xsec(t_at(st[i + 1]), w_at(st[i + 1]));
    }
}

// rounded rectangle in the s-w plane, extruded along n from n0 to n1
module sw_block(hl, hw, r, n0, n1) {
    translate([0, n0, 0]) rotate([-90, 0, 0]) linear_extrude(n1 - n0)
        offset(r = r) square([2 * (hl - r), 2 * (hw - r)], center = true);
}

module pocket_body() {
    hull() {
        sw_block(PL, POCKET_W / 2, POCKET_R, 0, POCKET_T - 0.8);
        sw_block(PL - 0.8, POCKET_W / 2 - 0.8, POCKET_R - 0.8, 0, POCKET_T);
    }
}

module stud() {
    at(-(PL + L_stud), strap_t - 0.5) {
        rotate([-90, 0, 0]) cylinder(d = stud_shaft_d, h = stud_shaft_h + 0.5);
        translate([0, stud_shaft_h + 0.5, 0]) rotate([-90, 0, 0]) {
            cylinder(d = stud_head_d, h = 1.0);
            translate([0, 0, 1.0]) cylinder(d1 = stud_head_d, d2 = 4.0, h = 0.8);
        }
    }
}

// the band's outer shape with the pocket filled in
module envelope() {
    pocket_body();
    strap(-1);
    strap(1);
    stud();
}

WIN_L = STICK_L / 2 - NOM_SQUEEZE;
module front_window(n0, n1) { sw_block(WIN_L - front_lip, CORE_W_NOM / 2 - front_lip, 1.0, n0, n1); }
module back_window(n0, n1)  { sw_block(WIN_L - back_lip,  CORE_W_NOM / 2 - back_lip,  1.0, n0, n1); }

// side-button openings: [s0, s1, side]
BTN_OPENINGS = [
    [BTN_XMINUS[0] - STICK_L / 2 - btn_margin, BTN_XMINUS[1] - STICK_L / 2 + btn_margin, -1],
    [BTN_XPLUS[0]  - STICK_L / 2 - btn_margin, BTN_XPLUS[1]  - STICK_L / 2 + btn_margin,  1]];
module side_opening(o, z_in, z_out, grow = 0) {
    n0 = CORE_N0 + BTN_Z[0] - btn_margin - grow;
    n1 = CORE_N0 + BTN_Z[1] + btn_margin + grow;
    translate([o[0] - grow, n0, o[2] > 0 ? z_in : -z_out]) cube([o[1] - o[0] + 2 * grow, n1 - n0, z_out - z_in]);
}

// core = Stick-shaped block + pads that fill the front/back windows.
// The side-button posts from each mold half drop into shallow pockets on its
// sides, which locates it; everything releases with a straight pull.
module core_part() {
    difference() {
        union() {
            sw_block(CORE_L / 2, CORE_W / 2, CORE_R, CORE_N0, CORE_N1);
            front_window(CORE_N1 - eps, POCKET_T);
            back_window(0, CORE_N0 + eps);
        }
        for (o = BTN_OPENINGS) side_opening(o, CORE_W_NOM / 2 - post_key - post_clear, CORE_W / 2 + 1, post_clear);
    }
}
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

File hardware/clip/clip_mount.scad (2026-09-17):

// M5Stack StickS3 (K150) clip mount: a printed cradle bolted to a tempered
// spring-steel belt clip. Clips to a shirt, pocket, waistband or watch band.
//
// Clips (theclip.com, both US-made tempered spring steel):
//   "631"  MCS-631SS, 2.72" x 1" stainless: sweat-proof, overhangs the top end by ~14 mm
//   "661"  MCS-661, 2.15" x 1" powder-coated/nickel spring steel: same length as the Stick
//
// Assembly:
//   1. Drop 2 M3 nuts into the hex pockets inside the cradle.
//   2. Tilt the Stick's USB-C end up, slide its top end under the lip, lower it, and
//      screw it down from underneath with 2x M2x6 socket-cap or button-head screws
//      (they sit in counterbores, flush with the bottom). No longer than 6 mm: the
//      Stick's threaded bosses are only ~3 mm deep with electronics right behind them.
//   3. Bolt the clip on with 2x M3x4 or M3x5 socket-cap / button-head screws through
//      the clip's own holes. With M3x6, add a washer under each head; nothing may
//      stick out past the nut or it will press on the Stick.
// USB-C stays open, so it charges on the clip.
//
// Print: PETG, flat side down, no supports. 0.2 mm layers, 5 walls, 100% infill.

/* [Clip] */
clip_model = "631"; // [631, 661]

/* [Fit tuning] */
// Gap around the Stick, per side. 0.2 if it rattles, 0.4 if it won't go in.
clearance = 0.3;

/* [Hidden] */
$fn = 48;
eps = 0.01;

// ---- StickS3 (from M5Stack's K150 drawing + official STL) -----------------
STICK_W = 24;
STICK_L = 48;
STICK_T = 14.08;
STICK_R = 3;
SCREW_POS = [[3, 8.5], [21, 8.5]];    // M2 threaded holes, from the Stick's left edge / USB-C end
SIDE_BUTTON_Z = 3.6;                  // side buttons start this far above the Stick's back

// ---- Cradle ---------------------------------------------------------------
wall = 2.2;
floor_t = 5.0;          // holds M3 nuts, and M2x6 cap screws engage 2.4 mm
rail_h = 3.0;
usb_curb = 1.2;
lip_overhang = 1.2;
lip_t = 1.6;
bottom_chamfer = 0.6;

W = STICK_W + 2 * (wall + clearance);
X0 = wall + clearance;
Y0 = -clearance - usb_curb;
Y_WALL = STICK_L + clearance;
Y1 = Y_WALL + wall;
LIP_Z = floor_t + STICK_T + clearance;
TOP_Z = LIP_Z + lip_t;
R_OUT = STICK_R + clearance + wall;

// ---- Clip hardware ----------------------------------------------------------
// Hole positions along the cradle (y). Hole spacing is dimensioned on theclip.com's
// drawings (1.000" and 0.50"); where the pair sits along the clip is scaled off the
// drawing, so the slots let the clip slide +/-3 mm to wherever its holes really are.
CLIP_631 = [Y0 + 3 + 5.2, Y0 + 3 + 5.2 + 25.4];   // open end ~3 mm past the USB-C end, bend at the top
CLIP_661 = [Y1 - 11.4, Y1 - 11.4 - 12.7];         // bend end at the top end
CLIP_HOLES_Y = clip_model == "661" ? CLIP_661 : CLIP_631;
slot = 6;
m3_clear = 3.4;
m3_nut_af = 5.5;
nut_h = 2.4;
nut_pocket = nut_h + 0.2;

assert(rail_h < SIDE_BUTTON_Z - 0.5, "rails would cover the side buttons");
assert(floor_t - nut_pocket >= 1.2, "floor too thin under the nuts");
assert(6 - (floor_t - m2_head_pocket) <= 2.6, "M2x6 would bottom out in the Stick's boss");
for (y = CLIP_HOLES_Y) assert(y - slot / 2 - m3_nut_af / cos(30) / 2 > Y0 + 1.2 && y + slot / 2 < Y1 - 3,
                              "clip slot falls outside the cradle");

module rrect(x0, y0, x1, y1, r) {
    translate([x0 + r, y0 + r]) offset(r = r) square([x1 - x0 - 2 * r, y1 - y0 - 2 * r]);
}

module chamfered_slab(x0, y0, x1, y1, r, z0, z1, c) {
    hull() {
        translate([0, 0, z0]) linear_extrude(eps) rrect(x0 + c, y0 + c, x1 - c, y1 - c, max(r - c, 0.5));
        translate([0, 0, z0 + c]) linear_extrude(z1 - z0 - c) rrect(x0, y0, x1, y1, r);
    }
}

module stick_pocket_2d() {
    offset(r = clearance) rrect(X0, 0, X0 + STICK_W, STICK_L, STICK_R);
}

// counterbore for an M2 socket-cap or button head (head sits flush with the bottom)
m2_head_d = 4.4;
m2_head_pocket = 1.4;
module counterbored_m2() {
    translate([0, 0, -1]) cylinder(d = 2.3, h = floor_t + 2);
    translate([0, 0, -1]) cylinder(d = m2_head_d, h = 1 + m2_head_pocket);
}

module stadium(d, len, h) {
    hull() for (dy = [-len / 2, len / 2]) translate([0, dy, 0]) cylinder(d = d, h = h);
}

// the nut pocket opens into the Stick pocket so nuts drop in from above; a seated
// nut's top is 0.2 mm below the floor, under the Stick
module m3_nut_slot() {
    translate([0, 0, -1]) stadium(m3_clear, slot, floor_t + 2);
    translate([0, 0, floor_t - nut_pocket]) hull() for (dy = [-slot / 2, slot / 2])
        translate([0, dy, 0]) cylinder(d = m3_nut_af / cos(30) + 0.3, h = nut_pocket + 1, $fn = 6);
}

module clip_mount() {
    difference() {
        union() {
            chamfered_slab(0, Y0, W, Y1, R_OUT, 0, floor_t + rail_h, bottom_chamfer);
            intersection() {
                chamfered_slab(0, Y0, W, Y1, R_OUT, 0, TOP_Z, bottom_chamfer);
                translate([-1, Y_WALL - lip_overhang, -1]) cube([W + 2, Y1 - Y_WALL + lip_overhang + 1, TOP_Z + 2]);
            }
        }
        translate([0, 0, floor_t]) linear_extrude(LIP_Z - floor_t) stick_pocket_2d();
        for (p = SCREW_POS) translate([X0 + p[0], p[1], 0]) counterbored_m2();
        for (y = CLIP_HOLES_Y) translate([W / 2, y, 0]) m3_nut_slot();
    }
}

clip_mount();

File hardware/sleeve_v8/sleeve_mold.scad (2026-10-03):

// Sleeve v8: one-piece silicone band + sealed jacket for the M5Stack StickS3, shaped like a Tropic
// strap so it takes a real metal Tropic buckle (18 mm between its lugs) on that buckle's own thin
// spring bar (21 mm tip to tip, ~1.4 mm body). Nothing printed stays in the band: no cast-in plate,
// no printed buckle or tongue.
//
// Short strap (70 mm): flares off the jacket, tapers to 17.6 mm, and thickens to 4.5 mm at its end,
// where a hole for the spring bar is cast across it and a 2 mm slot through the middle lets the
// buckle's tongue sit on the bar and swing. Long strap: flares off the jacket to 21.5 mm, one slow
// eased taper to 16 mm, then a quicker taper over the last 18 mm to a squared-off 12 mm tip; nine
// Tropic-style perforation on BOTH straps: a centre column of 2 mm holes at 5 mm pitch plus two side
// columns staggered half a step, 3 mm in from the edges, the whole length; every hole sits in a shallow
// diamond on the wrist face; the tongue uses the centre column. Both straps keep the thin 2 mm hinge at
// the jacket. The outer faces carry a smooth recessed panel inside a clean 0.7 mm raised outline (the
// v7 knurl was an air trap and is off). v8 also adds breather holes through the cup floor at the
// button recess and round the window lips, and twice the lid vents, after two casts with craters.
//
// Parts (set `part`, or use the Customizer), all PLA:
//   "core"        0.16 mm, as exported (back face down), supports on build plate only (port blade).
//   "cup"         one long open-top mold, 0.2 mm layers. Print DIAGONALLY on the 220 mm bed, brim.
//   "lid"         required: forms the wrist face, the fillet ridge, the hole pins, vents. Diagonally.
//   "keeper_mold" two ring cavities for the strap keepers.
//   "band"        preview of the finished silicone part (don't print).
//   "pin"         three printed pins (two spares), 0.16 mm, as exported. One lies across the cup at the
//                 short strap's end and casts the spring-bar hole; its handle fills a notch in the wall.
//
// Coordinates: x along the band (short strap toward +x, long strap toward -x), y across,
// z from the wrist face (0) toward the front. The cup's rim is z = 0.
//
// Casting (open pour, window face down), Smooth-Sil 950, 100A : 10B by weight:
//   1. Release on everything. Core on the cup floor, pad down, port blade down its relief in the end wall, two
//      M3x8 up through the cup. Lay the pin across the short strap's end: handle into the wide
//      notch, rod into the rib's seat and the narrow notch in the far wall.
//   2. Mix 54.5 g A + 5.5 g B (pigment into A first; the lid's boss pushes about 6 g back out). Degas if you can. BRUSH a thin coat over the
//      whole cup floor, the button recess, the strap troughs and round the core's pad (this is what
//      stops the craters), then pour in a thin stream at ONE end so the front advances along the cup.
//   3. Tap the cup and leave it 10-15 min so bubbles rise and pop. Then the lid, lowered LEVEL and slowly: its
//      boss is deepest at the sleeve's centre, touches there first and pushes the air out to the vents. Press
//      until the plate sits flat on the cup. Excess bleeds from the vents; a bead weeps from the breather holes
//      under the cup, so stand it on parchment, and pour the leftover over the lid to cover the vents.
//   4. Cure 18 h at room temperature, or about 6 h at 45 C. Fill the keeper mold from the same mix.
//   5. Lid off, then pull the pin out sideways by its handle. M3 screws out, card down the jacket's long sides,
//      M4 screws into the jack holes until the core and band rise. Peel the straps out, lift the
//      top end of the core out of the window and slide it toward the top end (the port blade draws
//      out of its slot). Trim the vent nubs; wipe any film off the port slot's mouth.
//   6. Keepers over the short strap's end. Buckle: tongue into the 2 mm slot, spring bar through
//      the strap and the tongue's loop, tips into the buckle's lugs.

/* [Part] */
part = "band"; // [core, cup, lid, pin, keeper_mold, band]

/* [Fit] */
squeeze = 0.0;          // pocket = Stick size; the silicone on every face grips it
size_min = 175;         // wrist circumference on the hole nearest the jacket; each hole adds hole_pitch
hole_pitch = 5;         // centre column pitch along the strap (tongue holes)
side_y = 4.0;           // side columns this far off centre (fixed, like the Tropic), staggered half a pitch; they stop where the strap gets too narrow
side_min_edge = 2.5;    // ... i.e. where less than this is left between a side hole and the strap's edge
hole_d = 2.0;           // on the outer face (the Tropic tongue is 1.8 mm at its tip)
pyr_w = 3.0; pyr_d = 0.3;   // on the wrist face each hole sits in a shallow diamond pyramid, Tropic style: diagonal, depth (hole_pitch - pyr_w = 1.8 mm of full-thickness strap between tips)
pyr_r = 0.6;            // the diamond's corners are rounded this much, so the pyramid's inside creases are smooth curves, not sharp valleys
hole_d_root = 2.2;      // the pin is this wide where it leaves the pyramid and tapers to hole_d (a straight 2 mm pin snaps)

/* [Jacket] */
wall = 2.8; end_t = 2.2; lip_t = 1.4; back_t = 1.7; side_bump = 0.5; front_min = 1.4;
body_r = 2.0;           // plan corner radius
front_r = 2.5;          // round on the front perimeter
back_r = 0.8;           // round on the wrist-side edge (lid ridge)
pad_rim_w = 0.6; pad_rim_h = 0.3;   // pinch-off rim round the window pad's face: seals on the cup floor, flash parts at the window edge

/* [Straps] */
strap_t = 3.0;
edge_r = 0.6;           // outer-face edge radius (small, so the outline reads crisp)
hinge_t = 2.0;          // thickness at the jacket: a thin, wide hinge so the band bends right at the sleeve
hinge_len = 6; root_len = 12;   // hinge for this far, blended up to strap_t by root_len
root_t = hinge_t;
fillet_r = 2.0;         // fillet between the hinge top and the end wall
flare_len = 15;         // jacket width -> base_w over this length
base_w = 21.5;
short_len = 70;
short_end_w = 17.6;     // fits the 18 mm buckle
bk_end_t = 4.5;         // thickness at the spring bar
end_ramp = 12;          // strap_t -> bk_end_t over this length before the bar
short_corner_r = 1.5;
buckle_w = 18;          // the long strap is this wide or narrower wherever it sits in the buckle
buckle_reach = 14;      // ... which starts this far toward the jacket from the hole in use
mid_w = 16;             // long strap: end of the slow taper
tip_w = 12; tip_len = 18;   // long strap: quicker taper over the last tip_len to a squared-off tip
tip_corner_r = 1.0;
tail = 25;              // long strap beyond the last hole
strap_angle = 15;       // [0:1:25] the straps leave the sleeve angled this far toward the wrist, then level out lower (0 = flat straps, as v7)
bend_x0 = 0.6;          // the bend starts this far beyond the end wall (clear of the port border)
bend_len = 12.4;        // ... and the strap is level again this much further on, before the textured panel starts
bend_round = 3.0;       // a round at each end of the straight angled part
bend_steps = 5;         // facets per round
saddle_d = 2.25;        // extra silicone under the sleeve's ends so its back follows the wrist instead of bridging it: about 3/4 of
                        // the measured gap (3 mm). Flat under the middle; curves over the outer part only, reaching strap_angle at the
                        // end wall, so it can never lift the middle and the strap leaves on the same slope. 0 = flat back
bend_out = 4.0;         // with the saddle: the strap leaves at the saddle's end slope and rounds back to level over this length

/* [Buckle end] */
bar_pin_w = 1.5;        // diameter of the printed pin that casts the spring-bar hole (the bar is ~1.4 mm)
rod_flat = 0.6;         // the rod is round with one small flat this far from its axis, so it prints lying on the bed
pin_clr = 0.1;          // clearance of the pin and its handle in their notches
handle_w = 4.0;         // the pin's handle fills a notch in one cup wall, flush with the rim
handle_grip = 5.0;      // ... and sticks out this far to pull on
grip_shoulder = 2.0;    // the grip is this much wider than the notch on each side
tongue_slot_w = 2.0;    // slot through the strap end for the buckle's tongue
tongue_slot_past = 2.5; // how far the slot runs past the bar
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

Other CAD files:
hardware/clip/stl/clip_mount_631.stl
hardware/sleeve/print/sleeve_core_upper_lower.3mf
hardware/sleeve/stl/sleeve_preview_not_for_printing.stl
hardware/sleeve_v2/print/sleeve_staple_x2.3mf
hardware/sleeve/sleeve_mold.scad
hardware/band/stl/band_core_default.stl
hardware/band/stl/band_mold_bottom.stl
hardware/band/stl/band_mold_top.stl
hardware/sleeve/print/sleeve_frame.3mf
hardware/sleeve/stl/sleeve_core.stl
hardware/sleeve/stl/sleeve_frame.stl
hardware/sleeve/stl/sleeve_mold_bottom.stl
hardware/sleeve/stl/sleeve_mold_top.stl
hardware/sleeve_v2/print/sleeve_core_and_mold.3mf
hardware/sleeve_v2/sleeve_mold.scad
hardware/sleeve_v2/stl/sleeve_core.stl
hardware/sleeve_v2/stl/sleeve_cup.stl
hardware/sleeve_v2/stl/sleeve_cup_fused.stl
hardware/sleeve_v2/stl/sleeve_lid.stl
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

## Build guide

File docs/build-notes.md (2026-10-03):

# Build notes

Everything dimensional comes from M5Stack's StickS3 (K150) drawing and official 3D model. Band sized for a 165 mm wrist.

## Files

| File | What | Print |
|---|---|---|
| `hardware/band/stl/band_mold_bottom.stl` | band mold, bottom half | PLA, as exported (parting face up), no supports, 0.12 mm layers |
| `hardware/band/stl/band_mold_top.stl` | top half (pour hole + vents) | same |
| `hardware/band/stl/band_core_default.stl` | forms the Stick pocket | PLA, as exported (on its side), 0.12 mm layers |
| `hardware/band/stl/band_core_tighter.stl`, `band_core_looser.stl` | pocket 0.1 mm tighter / looser per side | same; the mold halves never change |
| `hardware/band/stl/band_preview_not_for_printing.stl` | what the finished band looks like | don't print |
| `hardware/clip/stl/clip_mount_631.stl` | cradle for theclip.com MCS-631SS (stainless, recommended) | PETG, flat side down, no supports, 5 walls, 100% infill |
| `hardware/clip/stl/clip_mount_661.stl` | cradle for MCS-661 (coated steel, same length as the Stick) | same |
| `hardware/band/band_mold.scad`, `hardware/clip/clip_mount.scad` | editable sources (OpenSCAD) | |

## Hardware

All of it comes from one metric screw assortment (M2/M3, socket-cap or button head, with nuts and washers):

- 2 x M2x6 — hold the Stick in the clip cradle
- 2 x M3x4 or M3x5 — bolt the steel clip on (with M3x6, add a washer under each head)
- 8 x M3x30 + 8 nuts — clamp the mold
- 2 x M3 nuts — clip cradle

## Changing the design

Open a `.scad` in OpenSCAD, edit the values at the top, render (F6), export STL. Or from a shell:

```
openscad -o core.stl -D 'part="core"' -D 'squeeze=0.25' hardware/band/band_mold.scad
openscad -o clip.stl -D 'clip_model="661"' hardware/clip/clip_mount.scad
```

`squeeze` only affects the core, so tuning the grip never means reprinting the two big mold halves.

## Rendering without a GUI

The `tools/` folder is not in the repo. Either install OpenSCAD normally, or fetch the AppImage and M5Stack's reference model:

```
curl -L -o openscad.AppImage https://files.openscad.org/snapshots/OpenSCAD-2026.09.16-x86_64.AppImage
chmod +x openscad.AppImage && ./openscad.AppImage --appimage-extract    # runs without FUSE
curl -L -O https://raw.githubusercontent.com/m5stack/M5_Hardware/master/Products/K150_StickS3/Structures/StickS3.stl
```

## Band: casting

1. Sand both parting faces flat. Spray the halves and the core with Ease Release 200.
2. Lay the core in the bottom half: window pads against the cavity walls, side-button post in its side pocket. Close the top half. Bolt with 8 x M3x30 + nuts, snug. Heads and nuts drop into the pockets on the outer faces.
3. Vinyl gloves, never latex. The band needs ~18 ml, but cups, sticks and the syringe swallow a lot, so **mix at least 2x that: 20 g Part A + 20 g Part B** (Smooth-Sil 945 is 1A:1B by weight, 25 min pot life). For black, stir pigment into Part A first at **3% of total weight (about 1.2 g for 40 g)**, the maximum Smooth-On allows. The 945 base cures a strong purple; 1.5% black left it visibly purple, so use the full 3% and a concentrated pigment such as Silc Pig.
4. Inject slowly through the pour hole with a 60 ml syringe until silicone shows at every vent. Tap the mold on the table to free bubbles.
5. Wait 6 h (Smooth-Sil 945; SORTA-Clear 37 is 4 h). Unbolt, lift the band and core out, stretch the front lip over the core to pop it out. Trim the vent nubs and the seam.
6. Punch the 7 strap holes with a 3 mm leather punch, centred between the notches on the strap edges.

Test first: cure a 10 g cup with your pigment in it. If it sets firm overnight, cast the band.

The band sits across the wrist. Hole 3 of 7 is about 164 mm, hole 4 about 170 mm, 6 mm per hole. USB-C is covered, so pop the Stick out to charge.

## Clip: assembly

1. Drop 2 M3 nuts into the hex pockets inside the cradle.
2. Tilt the Stick's USB-C end up a little, slide its top end under the lip against the end wall, lower it, then screw it down from underneath with 2 x M2x6 socket-cap or button-head screws. They sit in counterbores, flush with the bottom. Never longer: the Stick's threaded holes are only ~3 mm deep with electronics behind them.
3. Bolt the clip on with 2 x M3x4 or M3x5 screws through the clip's own holes. The slots allow +/-3 mm, since the clip drawings don't dimension where the holes sit along its length.

USB-C stays open, so it charges on the clip.

## Sleeve v2 (`hardware/sleeve_v2/`)

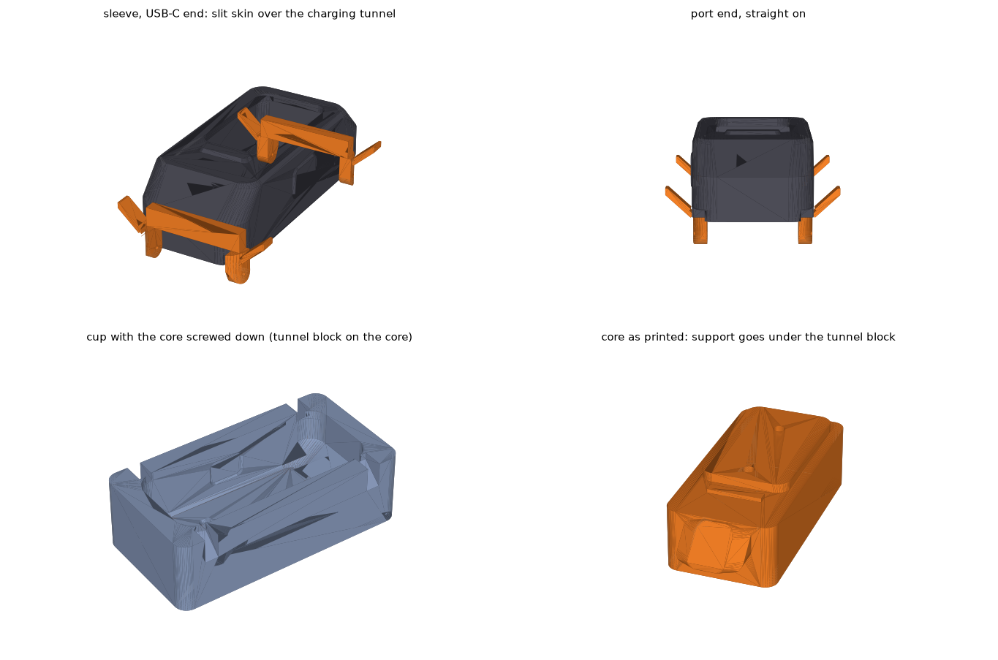
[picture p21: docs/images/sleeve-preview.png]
Sealed sleeve with the lug staples and the charging port; the cup with the core; the core as printed


A sealed silicone jacket around the Stick (2.6 mm walls, 2.5 mm back, 2.0 mm over the face) with two PETG **staples** cast into its thick end blocks: each is a 3 x 5 mm bar buried across the width, with two lug plates that sweep down under the nose to the spring bar. The plates' outer faces sit 0.3 mm inside the sleeve's sides, pressed against matching pads on the cup wall, so they cast as crisp recessed black rectangles either side of each nose (no thin film of silicone to wear through); the bar's ends are buried 1.3 mm. The strap tucks under the nose. The only opening is the screen window (19 x 31.5 mm); the buttons are covered, with a 0.5 mm pad over each side button and 2 mm of silicone over the front button. A 14 x 7.5 mm **charging tunnel** runs through the USB-C end block to the port, closed at the nose by a 2 mm skin (3.5 mm at the ends) that you slit after curing: the plug pushes through, the slit closes behind it. The tunnel floor clears the staple bar by 0.9 mm. 65.4 x 28.6 x 18.3 mm, lug gap 21.4 mm. Fit is tight (0.3 mm squeeze per side). Silicone does not bond to PETG, so the staples hold by being buried: pulling one out means tearing through 8.5 mm of silicone.

One mold piece, one core, two staples:

| File | What | Print |
|---|---|---|
| `stl/sleeve_staple.stl` | lug staple with break-off locating tabs, print **two** | **PETG**, as exported (upside down, bar on the bed), brim, no supports, 100% infill, elephant-foot compensation 0.15 mm |
| `stl/sleeve_core.stl` | the Stick's shape + the window pad + the tunnel block | PLA, as exported, 3 walls, **supports on, build plate only** (only the tunnel block gets one, a 6 mm pad beside the core that snaps off) |
| `stl/sleeve_cup.stl` | the mold: window face at the bottom, walls, noses, rim notches, two M3 holes in the floor; open top | PLA, as exported, no supports, 0.16 mm |
| `stl/sleeve_cup_fused.stl` | **alternative to cup + core:** the same cup with the core grown out of the floor through the window | PLA, as exported (**rim down**), supports on **build plate only**, threshold 50°, 0.16 mm |
| `stl/sleeve_lid.stl` | optional lid: a plate with lug slots and two vents that sits on the rim on 0.3 mm feet, for a flat back instead of a card-scraped one | PLA, as exported (flat, feet up), no supports |
| `stl/sleeve_preview_not_for_printing.stl` | the finished silicone part | don't print |

**Casting** (open pour, window face down): spray release on the cup, core and staples. Stand the core on the cup floor, pad down, tunnel block toward the deeper nose, and drive **two M3 x 8 screws** up through the holes in the cup's underside into the core (they self-tap; the heads sit in recesses so the cup still stands flat). Without them the core floats: printed PLA is about half the density of the silicone. Drop the staples into the rim notches, lugs up, and push them down so the plates seat between the pads on the cup wall (light push fit; if one binds, sand the plate's outer face, not the cup). The tabs rest on the notch floors and set the height. **Mix 15 g A + 15 g B** with 3-4% pigment. Fill with the syringe from the bottom up: tip down beside the core into the lip layer and the front-button pocket first, then fill to just above the rim. Tap the cup on the table, top up, scrape the surface flat with a card across the rim. Cure overnight. **With the lid:** overfill by 1-2 mm instead of scraping, tap, then within a few minutes of mixing lower the sprayed lid over the lugs and press it onto the rim; excess bleeds out at the edges, the slots and the two vents. Wipe the squeeze-out. After curing, snip the two vent nubs off the back. Card-scraping leaves faint ripples where the film relevels unevenly; the lid or a plain unscraped overfill (self-levels, trim the flash) both avoid that. It is the wrist side either way. Flex the cup and lift the sleeve out with the core inside. Take the two screws out, work one end of the core up through the window and slide it out. **Tabs:** each has a 0.6 mm neck just outside the silicone; grip the tab with pliers and twist, it parts at the neck. Shave any burr with a razor blade lying flat on the lug plate (the plate is flush with the sleeve's side, so the blade rides on PETG, not silicone). Don't sand near the silicone. **Cut the port slit:** lay the sleeve on its side, and with a fresh blade make one straight cut across the middle of the skin at the USB-C end, about 12 mm long, in a single stroke. Never saw at it. The slit ends land in the thick part of the skin; the tunnel behind is rounded, so there is no corner for a tear to start from.

**Fused cup (no loose core).** `sleeve_cup_fused.stl` is the cup and core in one piece, so the only things to place are the two staples. It prints rim down: the core then stands on a 2.5 mm slab of slicer support that sits on the bed under it (the space that becomes the sleeve's back), and the front face of the mold is bridged over the 2 mm lip gap (the longest bridge is 15 mm at the USB-C end). In the slicer turn supports on, "on build plate only", threshold angle 50° so the sloped noses are left alone, and normal (not tree) support so the slab comes out in one piece; if it also wants to support the bridged floor, add a support blocker there. After printing, pull the slab out from the open top. The front face of the sleeve comes out with a light bridge texture instead of the glossy bed finish, and the walls will be slightly rougher on the 46° nose slopes. Casting is the same, minus placing the core. **Demolding is harder:** the sleeve has to come off the core while it is still in the rigid cup, the same stretch as fitting the Stick but with less room to work. Let it cure the full 24 h, then lift one end by its two lugs so the end block peels its lip out from under the core (start with the USB-C end, the deep lip), then the other end, then the sides. A drop of soapy water at the ends helps. With the loose core you lift core and sleeve out together and peel the core out in your hand, which is why the two-piece version is still the default.

**Fitting the Stick:** USB-C end first, under the deep lip, then stretch the short lip over the top end. Spring bars (0.8 mm tips) through the lugs; open the holes with a 1.0 mm bit if a print closed them. To charge, push the cable straight into the slit at the USB-C end; the tunnel guides it onto the port. Set `port = false` in the .scad for a sleeve without the tunnel.

## Band v8 (`hardware/sleeve_v8/`)

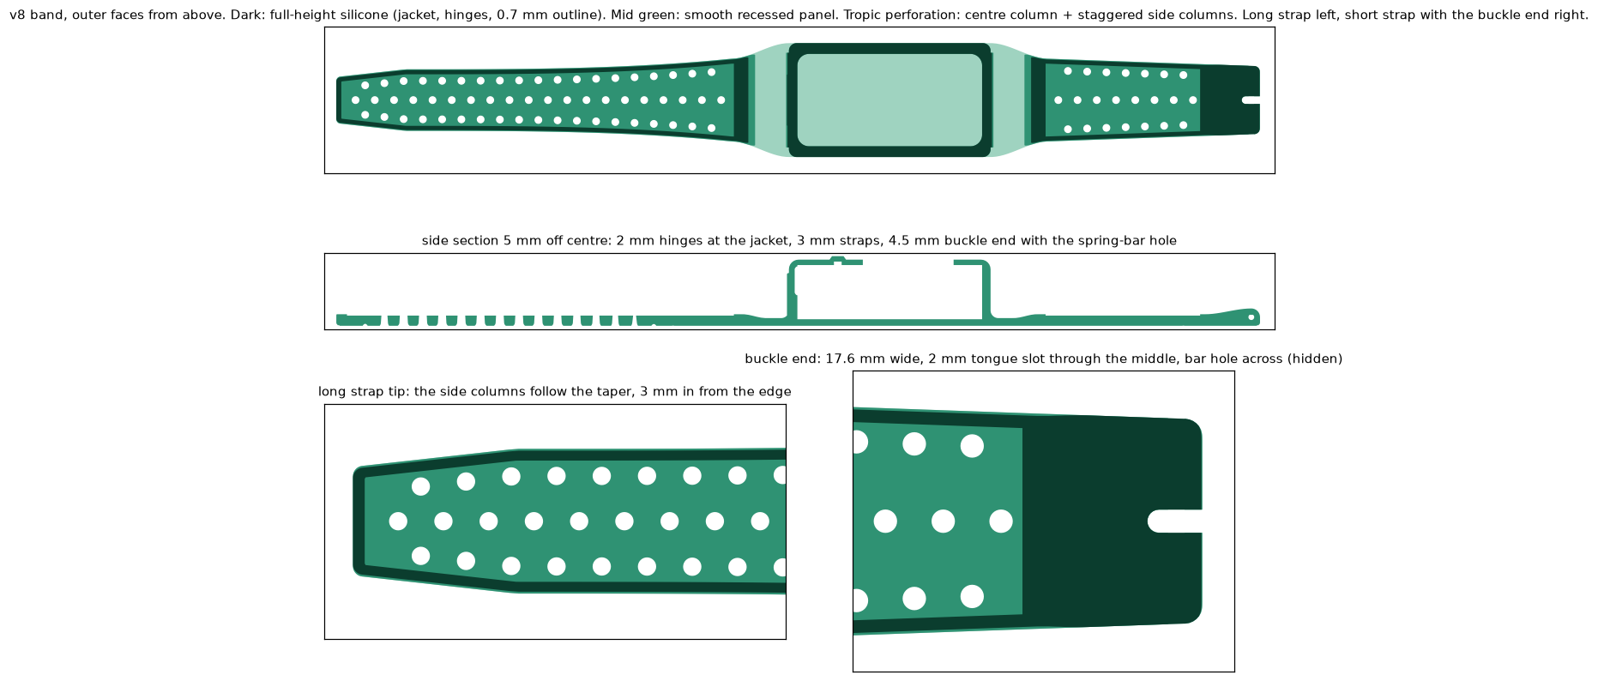
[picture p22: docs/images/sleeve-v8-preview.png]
Band v8: plan of the outer faces with the Tropic perforation, a side section, the long strap's tip and the buckle end


v7 cast twice in 950 and both casts had craters: a 1 cm paper-thin spot on a strap, a 1 cm bare patch over the front button, and pinholes across the wrist face. The big ones are air that was never displaced (the button recess is a dead-end pocket pointing at the cup floor, and the knurl was 280 small ones); the pinholes are mixing bubbles that rose and were stopped by the lid. v8 is v7 with:

- **Tropic perforation on both straps:** a centre column of 2 mm holes at 5 mm pitch plus two side columns 4 mm off centre, staggered half a pitch, from just past the flare to 5 mm from the tip (long) and to the thick end (short); the side columns stop where less than 2.5 mm would be left to the edge (the last 13 mm of the long strap). 76 holes. The tongue uses the centre column, so sizes run 140 to 235 in 5 mm steps. On the wrist face each hole has a 0.3 mm chamfer.
- **Tropic diamonds on the outer faces** (`tex_mode = "tropic"`): the whole panel is tiled with diamond pits, 5 mm along by 8 mm across, each a shallow inverted pyramid 0.6 mm deep with faces at about 27 degrees and a small flat floor, separated by a 0.7 mm raised lattice. The pits sit on the hole lattice, so every hole in the three columns is at the centre of its pit, and the outer columns of pits have no holes, exactly like the Tropic. Partial pits run out to the 0.7 mm raised outline. In the cup the pits are flat-topped bumps and the lattice is a network of channels that is connected everywhere (checked: one piece, never narrower than 0.6 mm), so air on the strap floors always has a way to the edge; brush anyway. The v7 knurl is still there as `tex_mode = "ridge"`, and a small-diamond version as `"dimple"`.

Outer faces: Tropic diamonds with the holes at their centres, close ups and sections
- **Raised lattice on the sleeve** (`front_tex`): 0.5 mm wide, 0.4 mm tall ridges in the same diamond geometry as the straps (2.11 mm line spacing, 35 degrees) over the lips round the window, over the rounded edge, and down the side and end walls as vertical ribs. Flat 0.6 mm round the window pad and the button bump; clear of the four plan corners. **Every rib has to slide straight out of the cup**, toward its open top, so each rib's groove runs unbroken to the top: the side-wall ribs run down to the rebate floor, 0.9 mm above the wrist edge (following the saddle), where their grooves open into the rebate, which stands 0.5 mm clear of the walls; the end-wall ribs run down into the strap root; the lattice lines that would pass a side-button pad are left out on that wall and over its edge round (a rib ending above a pad would be dragged over plain wall); at the USB end the ribs run straight into the strip, whose channel leads out. Checked with a whole-sleeve demold test (160,000 points on the band, lifted 0.1 to 4 mm toward the top, tested against the cup): only the side-button pads touch, which are sloped and have demolded in every cast. In the cup the grooves also give air a path along the walls. Nothing gets thinner: the lips stay 1.4 mm and the ridges stand on top; width grows 0.4 per side at the ribs; the seal is unchanged. `front_mode = "ribs"` gives straight grille-style ribs instead; `front_tex = false` the plain sleeve.

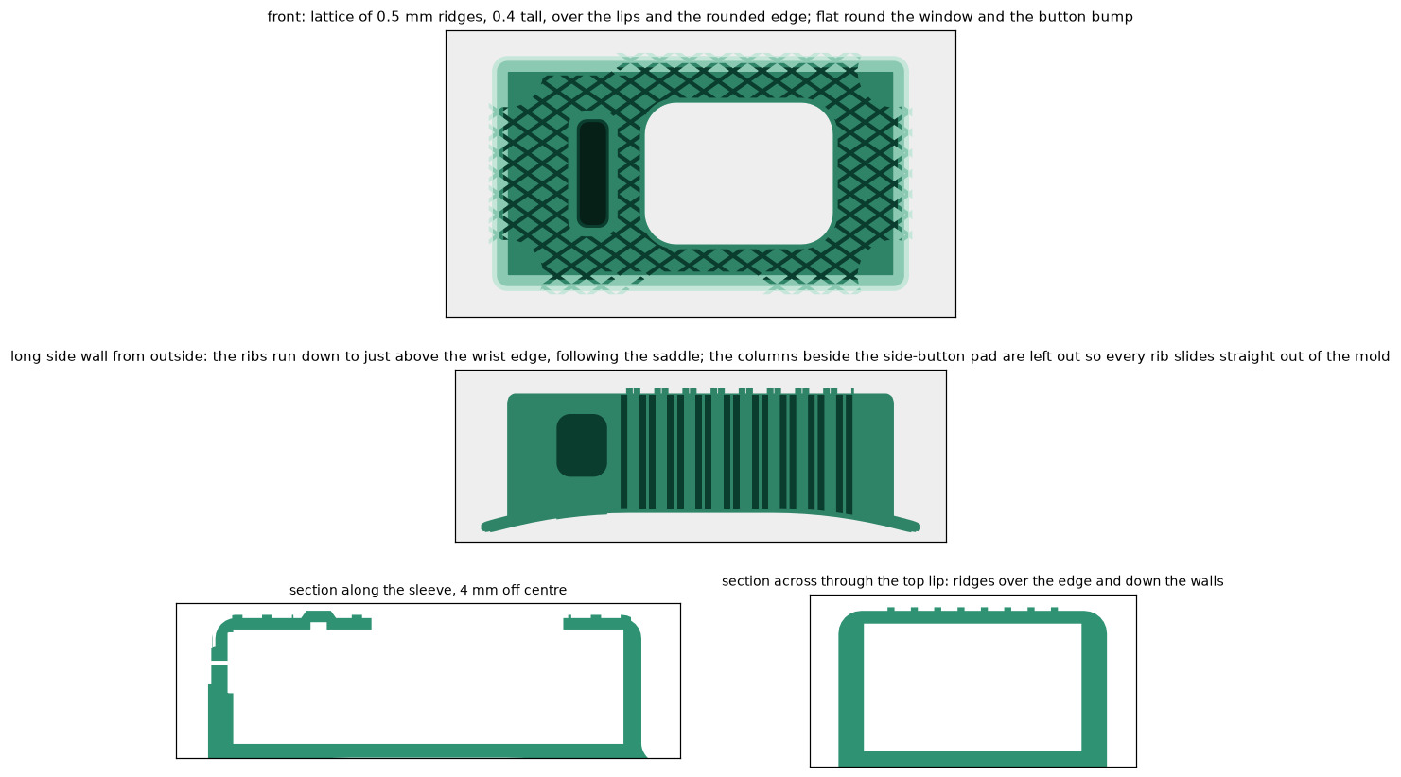
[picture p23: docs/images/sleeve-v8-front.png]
Sleeve front with the lattice, and two sections


- **USB end: a ribbed strip that flares into the strap.** The core's blade reaches out to the border's face, so the cup needs a channel from the blade up to the top for the core to drop in, and the band carries it as a raised strip down to the strap. The strip stays as wide as the border: the band leaves the cup straight toward its open top, so the border has to slide out down this channel (a narrower, keyhole-shaped strip was tried and traps the border). What changed: the strip carries four whole ribs from the end wall's rib lines, running its full length so their grooves in the cup open into the strap root's cavity, and its foot flares into the strap with 2 mm fillets. The end wall's ribs run straight into the strip and border, with no margin: their grooves then lead into the channel and out (ribs that stopped short of it would be trapped). Unchanged: 2.0 mm of silicone round the slot, the slot casts open, the core drops in and lifts out as before. A version without the strip was considered and rejected: the slot's edge would drop to the 1.5 mm skin, and the border would have to squeeze out of a closed groove at demolding.

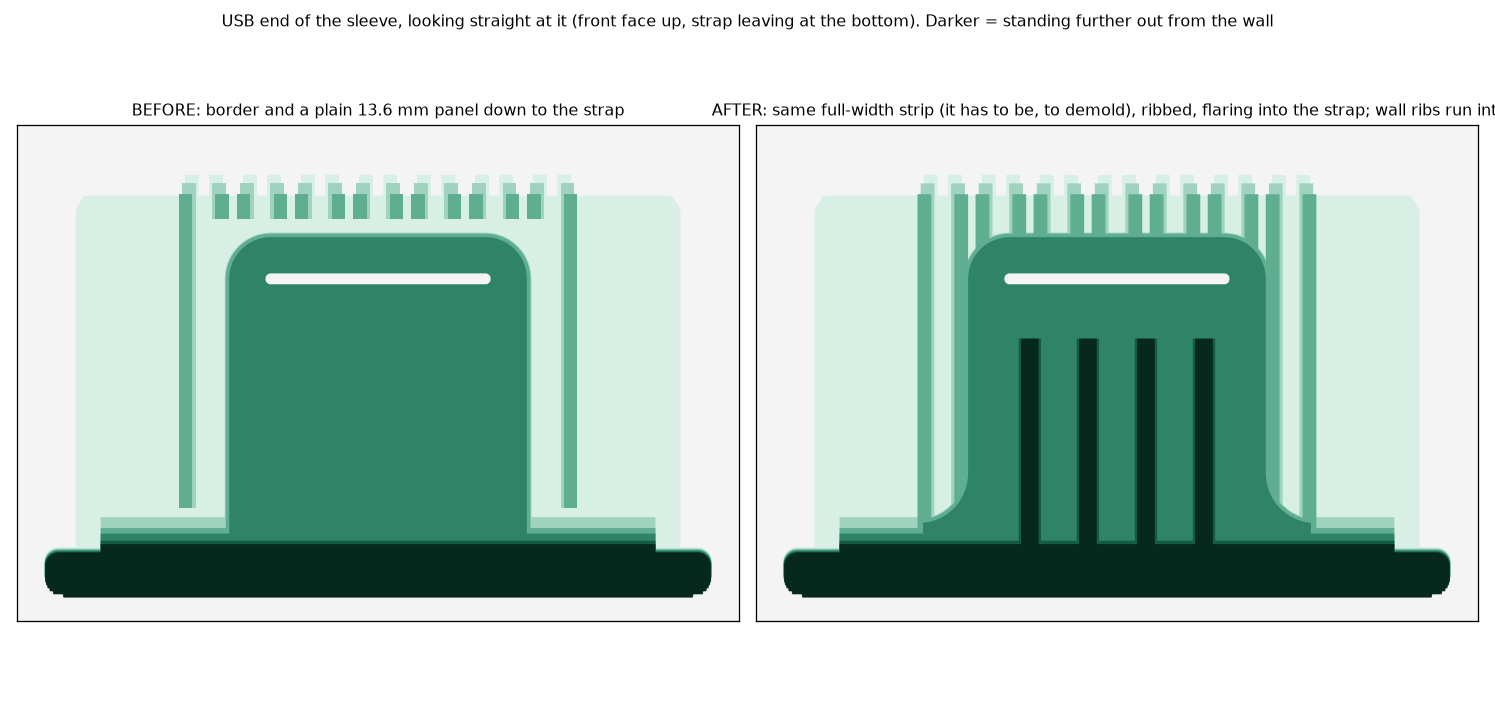
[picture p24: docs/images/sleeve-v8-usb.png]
The USB end wall before and after: plain panel versus the ribbed strip with a flared foot


- **Breather holes** through the cup floor: 0.8 mm at the front-button recess (the deepest point of the mold, where the bare patch was) and 0.6 mm at ten points **1.2 mm outside the window pad's edge**. Under the core the silicone flows in from the gaps round its sides and pushes the air inward until it piles up against the pad's sealed rim, so that ring is where the exits have to be. After the lid goes on, pour the leftover mix over the lid so every vent is covered: it feeds back whatever weeps out of the breathers, and the wrist face stays solid. A bead of silicone weeps out of each under the cup; stand it on parchment and trim the beads.
- **Twice the lid vents:** ten over the jacket, one every 10 mm along each strap between the hole columns, plus the thick end and the tip.
- **Saddle under the sleeve, straps leaving at 15 degrees** (`saddle_d = 2.25`, `strap_angle = 15`). A flat 52 mm sleeve on a curved wrist bridges it, leaving a gap of about 3 mm under each end. The back is now flat under the middle (|x| < 9.4 mm, where it rests on the wrist on the same 1.7 mm as before) and curves down over the outer 16.8 mm to 2.25 mm under each end, three quarters of the gap, so it fills the air there without ever lifting the middle: the sleeve sits no higher on the wrist, the part is only thicker at its ends (3.3 mm of back under the Stick's ends). The curve is chosen to reach 15 degrees at the end wall, so each strap leaves on that slope with no kink and rounds back to level over 4 mm, 2.8 mm below the sleeve's centre. The straps are sheared, not thickened: the 2 mm hinge is unchanged. A second measurement, the gap halfway between the centre and an end, would let the curve follow the wrist more closely. **The mold suits an open pour:** the cup's top is one flat plane at the straps' level (the cup is 24.9 mm tall), recessed over the sleeve, and the lid has a boss that fills the recess and forms the curved back. The boss is deepest at the centre, so the lid goes on level: the centre touches first and pushes air outward. It displaces about 3.6 cm3 (4.4 g) through the vents; the flash along the sleeve's long sides is up to 3.7 mm tall at the middle. `saddle_d = 0` gives the earlier version with a straight 15 degree run from the flat back, and both at 0 the flat straps; the USB-end change below applies in every mode, so neither reproduces the older files exactly any more.

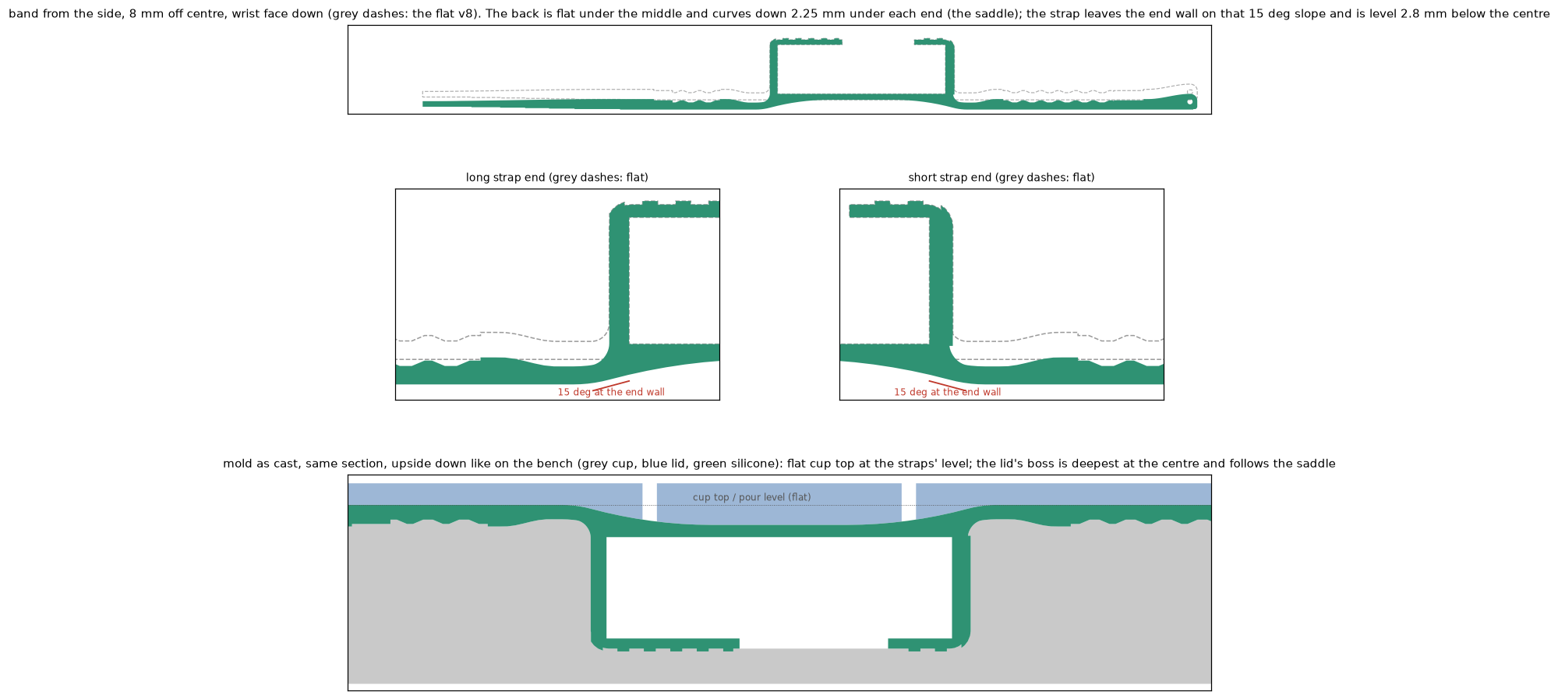
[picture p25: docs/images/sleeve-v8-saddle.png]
The band from the side with the saddle and the 15 degree exits against the flat version, close ups of both ends, and the mold section with the lid's boss following the saddle


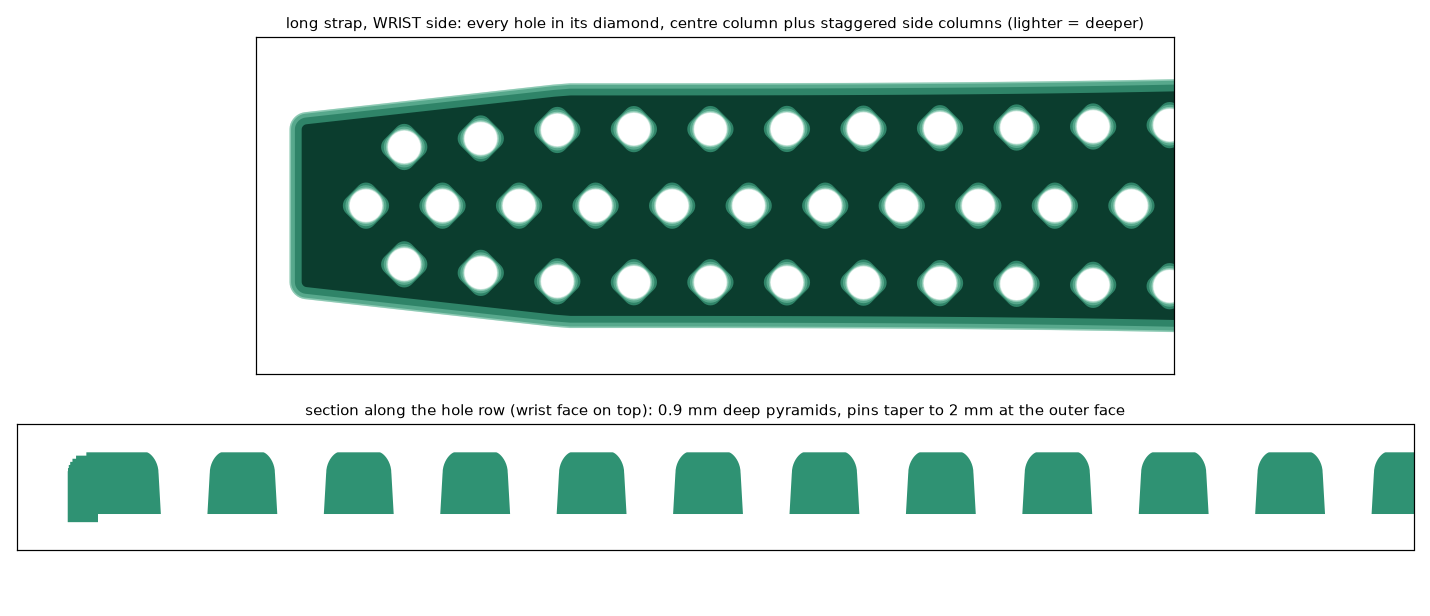
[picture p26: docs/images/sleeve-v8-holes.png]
Wrist side of the long strap with the perforation, and a section along the centre column


The holes do not vent the strap floors: the cup is 19 mm thick under the straps, so the pin sockets cannot reach outside. What stops strap craters is the print coat in the procedure below.

| File | What | Print |
|---|---|---|
| `stl/band_core.stl` | as v7 | PLA, 0.16 mm, supports on build plate only (under the port blade) |
| `stl/band_cup.stl` | v7 cup with the Tropic diamond bumps, the sleeve-front lattice grooves, 76 pin sockets and 11 breather holes; flat top at the straps' level with the recess over the sleeve for the lid's boss (24.9 mm tall) | PLA, 0.2 mm, diagonal, brim; clear any breather hole that printed shut with a needle |
| `stl/band_lid.stl` | wrist face: boss over the sleeve that forms the saddle (2.8 mm deep at the centre), fillet ridge and boss reaching 0.4 mm past the outline (the cup's rebate 0.5, clear of the wall ribs), 76 chamfered hole pins, the two bosses over the pin, 37 vents | PLA, 0.2 mm, diagonal; set a minimum layer time of 8 s so the pins cool |
| `stl/band_pin_x3.stl` | as v7, the handle's top corner trimmed to the wider rebate | PLA, 0.16 mm |
| `stl/keeper_mold.stl` | as v7 | PLA |
| `stl/band_preview_not_for_printing.stl` | the finished part | don't print |

**Casting, revised (Smooth-Sil 950, 100A : 10B):** release on everything. Core on the floor, pad down, blade down its relief, two M3 x 8. Pin across the short strap's end, shoulder against the wall. **Mix 54.5 g A + 5.5 g B** (60 g: about twice the band plus what the lid's boss pushes back out through the vents), pigment into A first; vacuum degas if you have a chamber. **Brush a thin coat of the mix over every surface the silicone will touch on the floor side** with a cheap flat brush: the whole cup floor, the button recess, both strap troughs and the panel steps, the thick end round the pin, and up to the core's pad edge. This is the step that stops the craters. Then pour the rest in a thin stream from height **at one end only**, so the front advances along the cup and pushes the air ahead of it, until it stands just above the cup's top all over (the recess over the sleeve fills too). Tap the cup on the bench for a minute. **Leave it 10 to 15 minutes** so bubbles rise and pop at the open surface. Then the lid, lowered level and slowly: the boss is deepest at the sleeve's centre, so it touches there first and pushes the air out to the vents; press until the plate sits flat on the cup. Cure 18 h, or 6 h at 45 C. Demold as v7: lid, pin, screws, jacks; stretch the USB wall off the blade before lifting the core. Trim the vent nubs and the breather beads.

## Band v7 (`hardware/sleeve_v7/`)

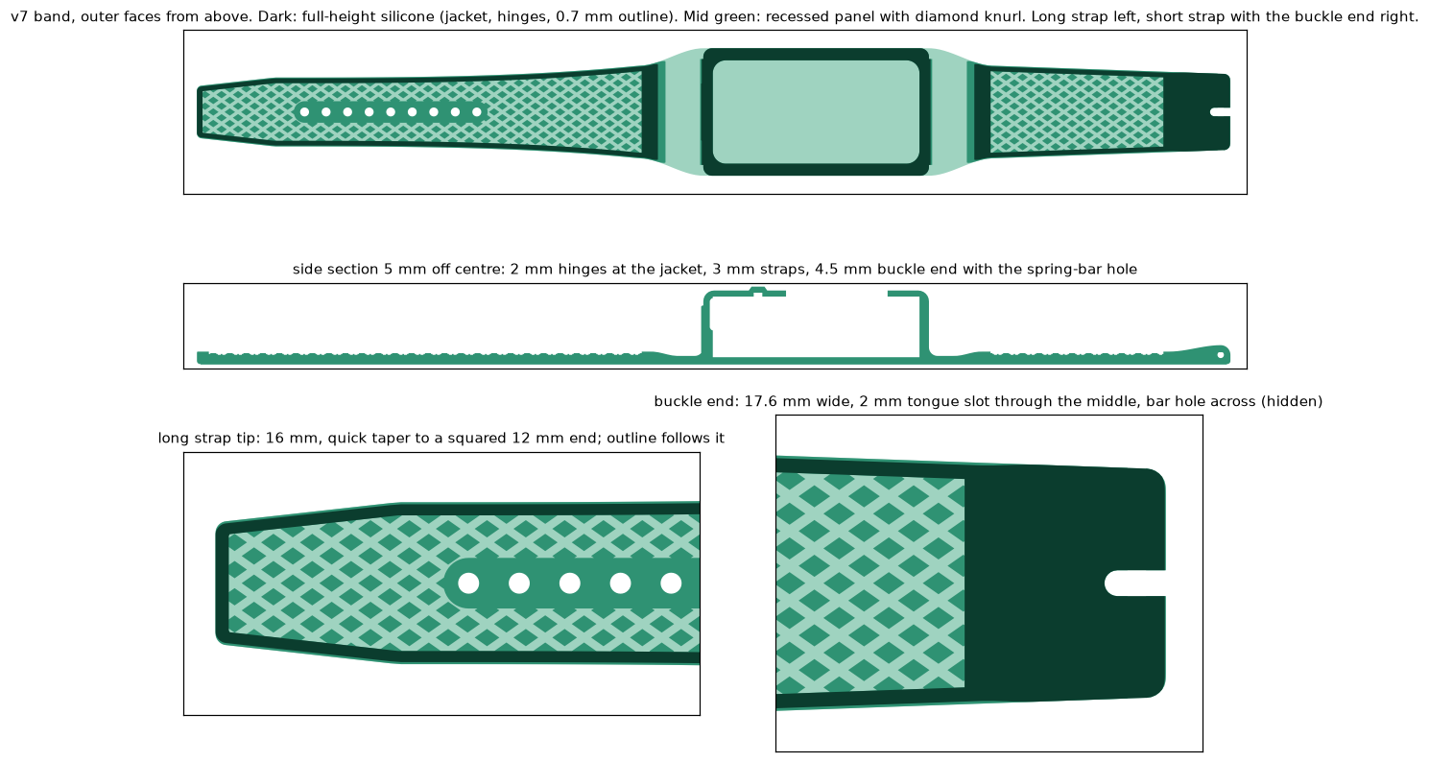
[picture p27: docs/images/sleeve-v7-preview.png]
Band v7: plan of the outer faces with the outline and knurl, a side section, the squared tip of the long strap and the buckle end of the short strap


The v6 jacket with **Tropic-shaped straps and a real metal Tropic buckle**. Nothing printed stays in the band: no cast-in plate, no printed buckle or tongue (v6's printed lugs let the spring bar pop out). The buckle is 18 mm between its lugs and pivots on its own thin spring bar (21 mm tip to tip, about 1.4 mm body).

| | Short strap (70 mm) | Long strap (117.6 mm) |
|---|---|---|
| Width | 29.6 at the jacket, 21.5 after a 15 mm flare, straight taper to 17.6 at the end | 29.6, 21.5 after the flare, one eased taper to 16.0 that ends 18 mm before the tip, then 16 to 12 over the last 18 mm |
| Thickness | 2.0 hinge at the jacket, 3.0 strap, 4.5 at the buckle end (ramps over 12 mm) | 2.0 hinge, 3.0 strap |
| End | quarter-round over the bar, 1.5 mm plan corners | squared off, 1 mm plan corners |

- **Slow taper:** the long strap has to be 18 mm or narrower wherever it sits in the buckle, which starts 14 mm toward the jacket from the hole in use. A straight taper from 21.5 to 16 would still be 19.3 mm there, so the taper is one eased curve (exponent 3.09, computed from that constraint): 18.0 mm at 38.6 mm from the jacket, 16.0 to 16.9 at the holes.
- **Holes:** nine, round, 5 mm pitch, sizes 175 to 215 mm (the tongue sits at the short strap's end). 2.0 mm on the outer face for the 1.8 mm tongue tip. On the wrist face each hole sits at the bottom of a **shallow diamond pyramid**, Tropic style: 3.2 mm across its diagonals (one diagonal along the strap), 0.9 mm deep (the straight part of the hole is the remaining 1.75 mm), only at the nine holes, with 1.8 mm of full-thickness strap between neighbouring tips. The pyramid is smooth all over: its corners are rounded (no sharp valleys between faces), its rim rolls over from the wrist face, and its faces curve into the hole. The lid's pins stand on those pyramids and taper from 2.2 to 2.0 mm, which is also what keeps them from snapping on demolding. 25 mm of tail past the last hole.

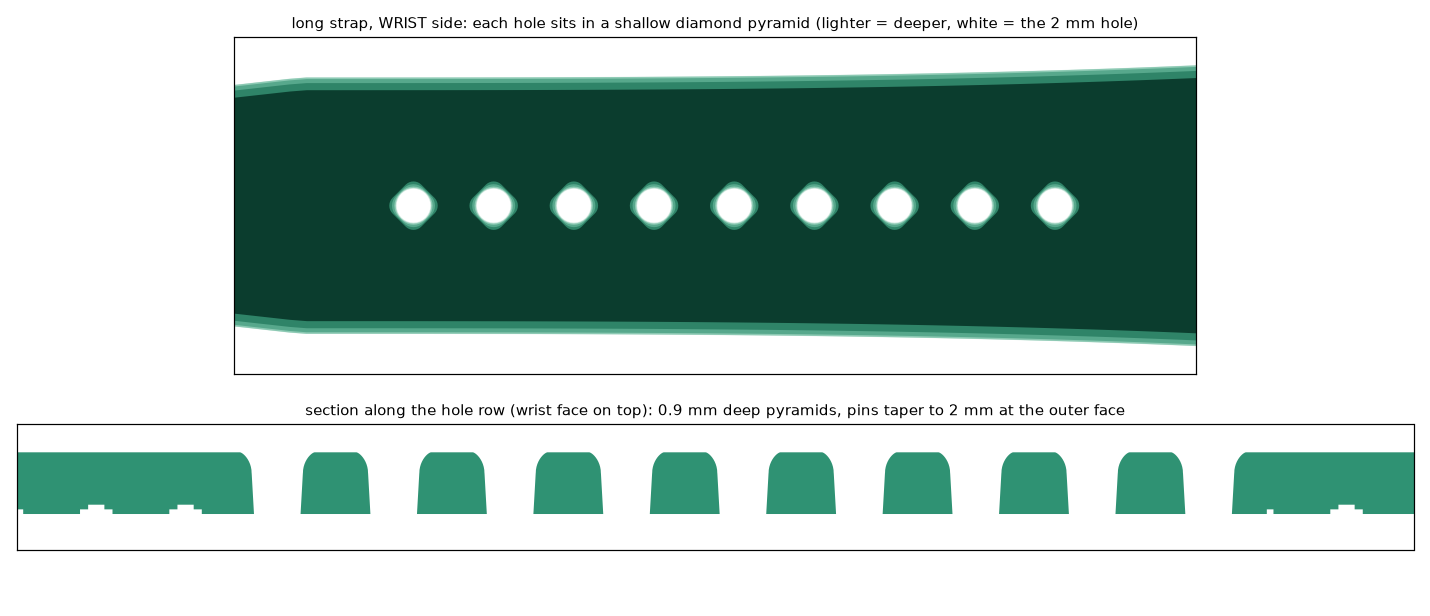
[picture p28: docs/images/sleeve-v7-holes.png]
Wrist side of the long strap with the diamond pyramids, and a section along the hole row


- **Buckle end:** the bar axis is 2.25 mm from the end and 2.25 mm above the wrist face, so 1.5 mm of silicone surrounds the hole on every side. The hole is cast by a **printed pin that drops in from the rim** (a 1.5 mm round rod with one small flat so it prints lying down; the hole has no corners for a tear to start from): its handle fills a 4 mm notch in one cup wall, flush with the rim, and ends in a wider grip outside the cup whose shoulder stops against the cup's outer wall, so the pin is fully in when the shoulder touches; the rod lies in a round-bottomed seat in the rib and in a matching notch in the far wall. A **2.0 mm slot through the full thickness**, from the end to 2.5 mm past the bar, lets the buckle's tongue sit on the bar and swing. Its former is split at the pin: a rib on the cup below it and a boss on the lid above it, so nothing has to be threaded through a hole. A second small boss on the lid fills the far wall's notch above the rod.

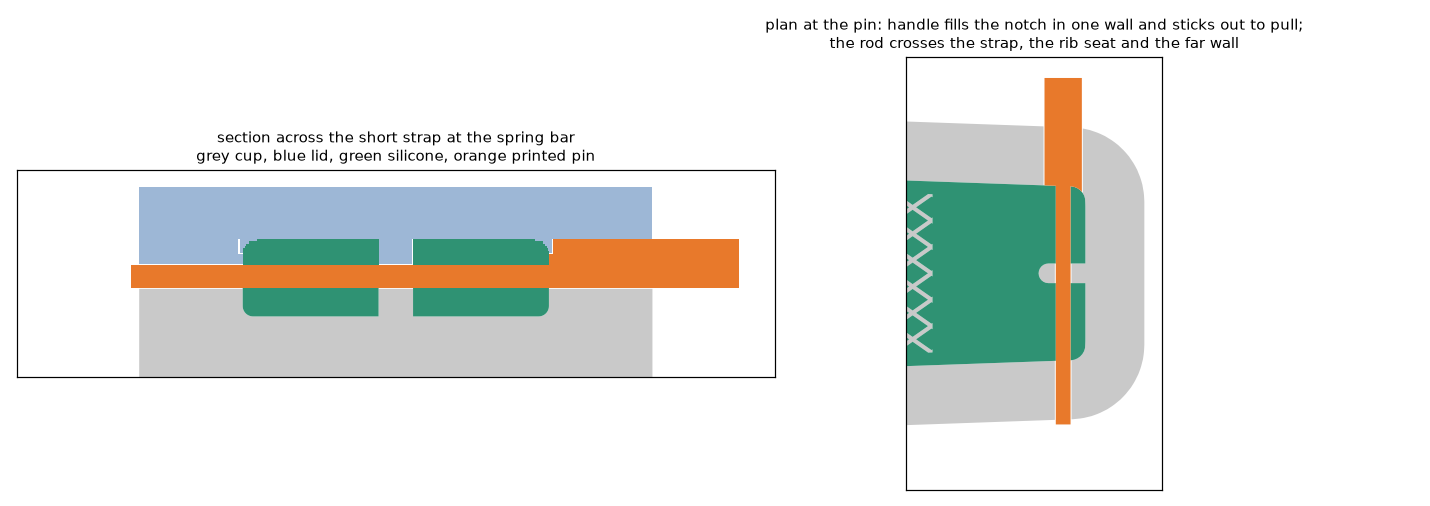
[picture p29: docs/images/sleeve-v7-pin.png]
Section across the short strap at the spring bar, and a plan at the pin's height
 The extra thickness is on the outer face; the wrist face stays flat.
- **Outline and texture:** a panel inset 1.3 mm from the strap edge is recessed 0.35 mm, leaving a clean 0.7 mm raised outline (the outer-face edge radius is 0.6). The v6 diamond knurl is cut into the panel and runs to its edge, with a smooth lane round the holes. The panel starts past the hinge and stops where the buckle end thickens. Thinnest silicone under a groove: 2.25 mm.
- **Port border:** the slot in front of the USB-C port sits in a raised border, 0.5 mm proud of the end wall with rounded edges, 1.8 mm beyond the slot all round, so the silicone the plug pushes through is 2.0 mm thick instead of 1.5. The core's blade now ends flush with the border's face and touches the cup there. Because the core drops in from the rim, the same 0.5 mm relief has to run from the border to the rim, so the border continues toward the strap as a raised strip of the same width. There is no tab to cut off any more; at most a film over the slot's mouth to wipe away.

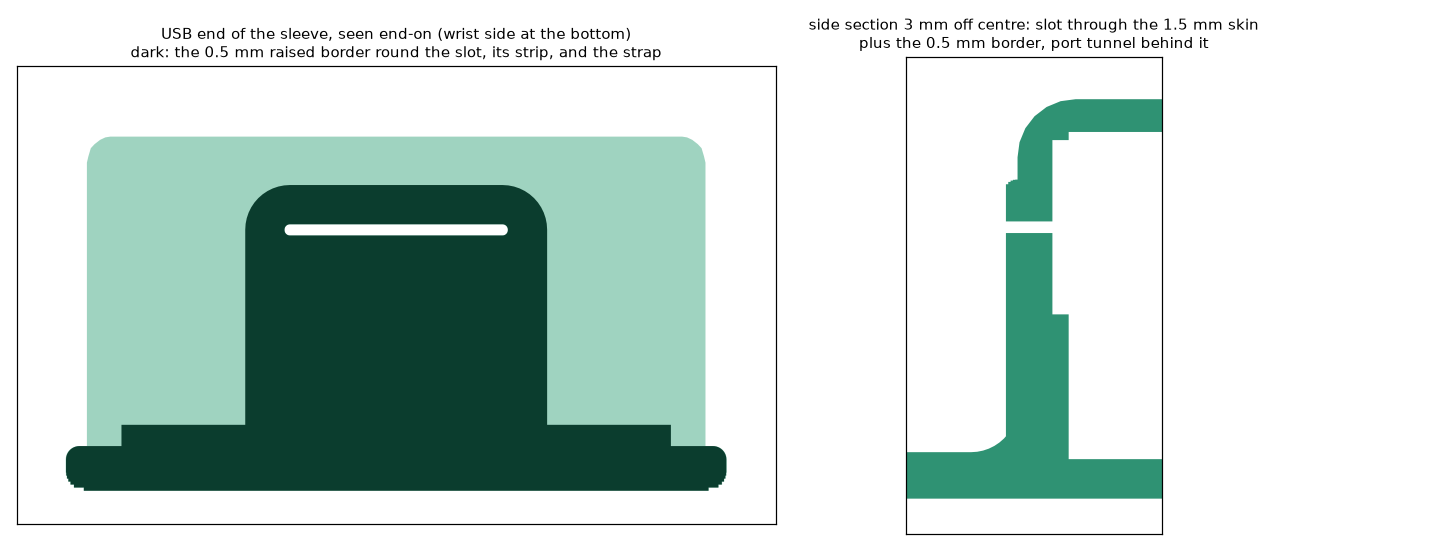
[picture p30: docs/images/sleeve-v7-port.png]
The USB end seen end-on, and a side section through the slot


- **Window edge:** the core's window pad now touches the cup floor only on a 0.6 mm rim round its edge (the middle is relieved 0.3 mm). The screws press a line, which seals far better than a printed face, and any film that still gets under is thinnest at the window's edge and parts there.
- **Keepers:** two cast silicone rings, 19.5 x 6.2 mm inside, slipped over the short strap's end before the buckle goes on.

| File | What | Print |
|---|---|---|
| `stl/band_core.stl` | Stick shape, window pad with pinch-off rim, port tunnel and blade | PLA, as exported, 0.16 mm, 3 walls, supports on build plate only (under the port blade) |
| `stl/band_cup.stl` | one 252 x 43 mm open-top mold: panel plateaus and knurl ridges on the trough floors, lower tongue-slot rib with the pin's seat, two pin notches, hole-pin sockets | PLA, 0.2 mm, **diagonal** on the bed (fits a 191 mm square), brim, no supports |
| `stl/band_pin_x3.stl` | three pins (two spares): handle + 1.5 mm round rod, 35 mm long | PLA, 0.16 mm, as exported (rod on the bed), no supports. Check one drops into its notches before pouring |
| `stl/band_lid.stl` | wrist face: fillet ridge, nine hole pins on diamond pyramids, the two bosses that close over the pin, seventeen vents | PLA, diagonal, no supports |
| `stl/keeper_mold.stl` | two ring cavities | PLA, as exported |
| `stl/band_preview_not_for_printing.stl` | the finished part (18.7 cm3) | don't print |

**Casting (Smooth-Sil 950, 100A : 10B by weight):** release on everything. Core on the floor, pad down, port blade down its relief in the end wall, two M3 x 8 up through the cup. Lay the pin across the short strap's end: handle into the wide notch, rod into the rib's seat and the far wall's notch. **Mix 44 g A + 4.4 g B**, pigment into A first (the band is about 23 g; the rest is the keepers, the cup and the stick). Degas if you can. Syringe the lip layer, the front-button pocket and the thick end round the pin, then pour along the whole length to just above the rim, tap. Lid on, one end first; excess bleeds from the vents. Fill the keeper mold from the same mix. Cure 18 h, or about 6 h at 45 C (not hotter: the molds are PLA). **Demolding:** lid off, then pull the pin out sideways by its handle. M3 screws out, card down the jacket's long sides, M4 screws into the jack holes until the core and band rise. Peel the straps out, lift the top end of the core out of the window and slide it toward the top end. Trim the vent nubs and wipe any film off the port slot's mouth. **Buckle:** keepers on first; tongue into the slot, spring bar through the strap and the tongue's loop, tips into the buckle's lugs.

## Band v6 (`hardware/sleeve_v6/`)

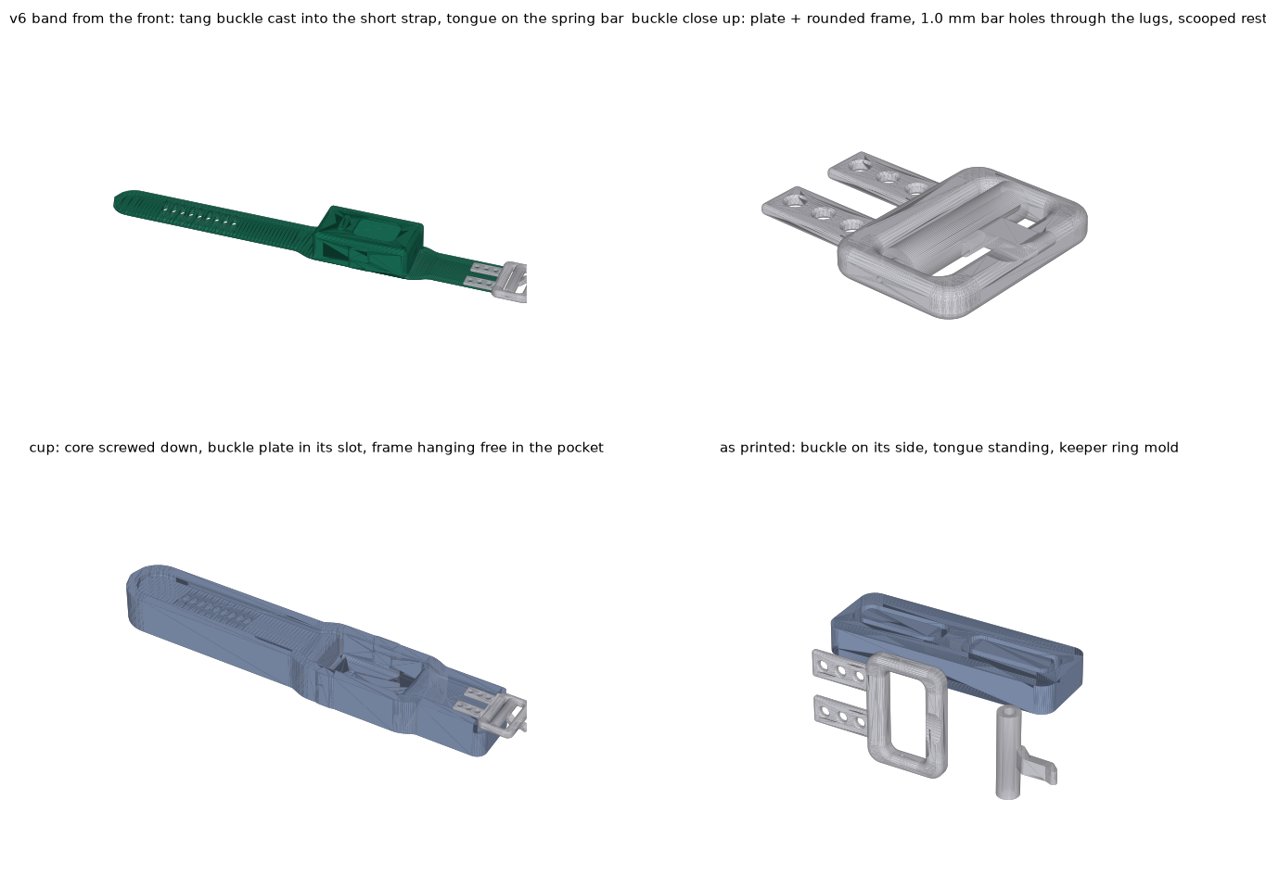
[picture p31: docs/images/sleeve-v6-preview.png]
Band v6: the one-piece band with the tang buckle cast into the short strap; the buckle close up; the cup; the parts as printed


v5's band with a **classic tang buckle** in place of the peg, and 0.2 mm more silicone over the face and the back (lip 1.4, back 1.7 mm; 17.2 mm tall). Everything else is v5: same jacket, hinge, window, one open pour. The **port slot is cast, not cut**: a 0.5 x 10 mm blade with rounded ends on the core runs from inside the port tunnel through the 1.5 mm skin and 1 mm into a channel in the cup's end wall, so the band comes out with a 10 x 0.5 mm slot in front of the USB-C port that has no crack tips to spread from (a cut slit kept growing). The channel is open from the rim so the core drops in; it fills with a thin silicone tab above the slot, which is cut off flush. The nine holes sit 10 mm further toward the tail (sizes 160-200 instead of 150-190; v5 barely fitted a 165 wrist) and are **slots**, 3.4 x 5.8 mm with rounded ends, for the wider tongue.

**Buckle:** one PETG piece cast into the end of the short strap. A 5 x 4.5 mm plate closes the strap end, anchored by two 16 mm rounded tongues with three chamfered holes each, buried mid-thickness in the strap. From the plate grows a **rounded frame**: 3.2 x 4.5 mm rails and a 4.5 mm far bar, plan corners R3.5 outside and R2 inside, every edge rounded R1.5, so the section is nearly a wire and nothing is square. The lugs carry the **Tropic strap's 22 mm spring bar** (24.5 tip to tip, 2.5 body, 0.8 tips) in **1.0 mm holes straight through**, 22.6 mm apart, so the tips sit 0.95 mm deep and a pin pushes the bar out from outside. The far bar has a scooped, tapered rest for the tongue. No keeper on the buckle, no lips, no pins, nothing sticks out. The **tongue** is a second print: a full-width sleeve (3.0 mm bore for the 2.5 mm bar, 1.3 mm wall, 22.2 long) that hides the bar and centres the arm, and a **4.5 x 2.2 mm arm** (3.5 at the tip) that rests in a broad shallow dish on the far bar with 0.3 mm clearance and turns up 1.2 mm at the tip; wide so it cannot snap. Bar centre 2.6 mm above the wrist face, so the sleeve sits flush with the wrist. The **keeper is a cast silicone ring** (22.2 x 5.6 inside, 2 mm section, 5 mm wide) from its own two-cavity mold: it stretches over the buckle onto the short strap and the tail tucks through it, like any watch.

**Texture:** the straps' outer faces carry a diamond knurl: two families of grooves at 35 degrees to the strap, 2.2 mm apart, 0.4 mm deep and 0.8 mm wide at the surface, tapered in two steps. They are ridges on the cup's trough floor (two layers at 0.2 mm). The pattern stops 2 mm from the strap edges and the round tip, leaves a smooth lane 1.5 mm around the slot row so no groove ends at a slot, starts past the thin hinge, and stays off the buried anchors (only 0.6 mm of silicone covers them). Set `texture = false` for plain straps.

**Wear:** long strap under the far bar, tongue out through a slot, tail over the sleeve and the plate, along the short strap and through the keeper. Sizes 160-200 mm in 5 mm steps.

**Mold:** the plate sits in a slot flush with the strap end with a 1.5 mm wall in front of it between the rail-root fillets; the frame hangs in an open pocket touching nothing, so demolding never loads it. The lid's 0.2 mm step presses the plate onto its seat; the ridge that rounds the wrist edge stops short of the plate. Thirteen vents (six over the jacket, seven along the straps) instead of five.

| File | What | Print |
|---|---|---|
| `stl/band_buckle.stl` | plate + anchors + tang frame, one piece | **PETG**, as exported (on its side: bar holes vertical, one rail on the bed, the other bridges 11 mm), 0.16 mm, **250-255 C, fan 10-20%, outer walls 30 mm/s**, Arachne walls with min wall width 50%, 100% solid, brim, supports on **build plate only** (they land under the two anchors and nowhere else) |
| `stl/band_tongue.stl` | sleeve + arm | PETG, as exported (sleeve standing, so the bore is round), same settings, supports on build plate only (under the arm) |
| `stl/keeper_mold.stl` | two ring cavities, 5 mm deep | PLA, as exported, no supports |
| `stl/fixed_tongue_temp.stl` | stand-in for the pivoting tongue when the spring bar is lost: a block that drops into the frame against the plate, a saddle on the plate and rail tops, and a short hooked tongue that stops 2.5 mm short of the far bar. Locked by one ~0.9 mm wire (a straightened paperclip) through lug, block and lug, ends bent over | PETG, as exported (standing, wire hole vertical), supports on build plate only, brim |
| `stl/band_core.stl` | Stick shape + window pad + port tunnel + port blade | PLA, as exported, 0.16 mm, 3 walls, **supports on, build plate only** (under the 0.5 mm blade that sticks out of the USB-C end) |
| `stl/band_cup.stl` | one 230 x 43 mm open-top mold | PLA, **placed diagonally** on the bed, brim, no supports |
| `stl/band_lid.stl` | wrist face: fillet ridge, clamp step over the plate, nine slot pins, thirteen vents | PLA, diagonally, no supports |
| `stl/band_preview_not_for_printing.stl` | the finished part | don't print |

**Casting:** release on the PLA only. Core on the floor, pad down, two M3 x 8 up through the cup. Buckle into its seat at the short end: plate dropped into its slot, anchors pointing back along the trough, frame hanging free in the pocket. **Mix 44 g A + 4.4 g B of Smooth-Sil 950** (100:10 by weight, 45 min pot life, 18 h cure; 950 tears 30% harder than the 945 used up to v5, which was 1:1, 22 g + 22 g) with pigment. Syringe the lip layer, the front-button pocket and the strap end around the anchors, then pour along the whole length to just above the rim, tap. Lid on, one end first, press onto the rim; excess bleeds from the vents. Fill the keeper mold from the same mix with the syringe and scrape it flush. Cure 24 h or 6 h at 45 C. **Demolding:** cut the flash round the lid, lever it off. M3 screws out, card down the jacket's long sides, M4 screws into the jack holes until the core and band rise. Peel the straps out, lift the top end of the core out of the window and slide it toward the top end so the port blade draws out of its slot. Trim the vent nubs, punch any hole skins, and cut the thin silicone tab off the USB-C end flush with the wall. Pull the keeper rings out of their mold with a pick. **Assembly:** keeper over the buckle onto the short strap first. Sleeve onto the spring bar, compress the bar, tips into the two lug holes; the arm points at the far bar.

## Band v5 (`hardware/sleeve_v5/`)

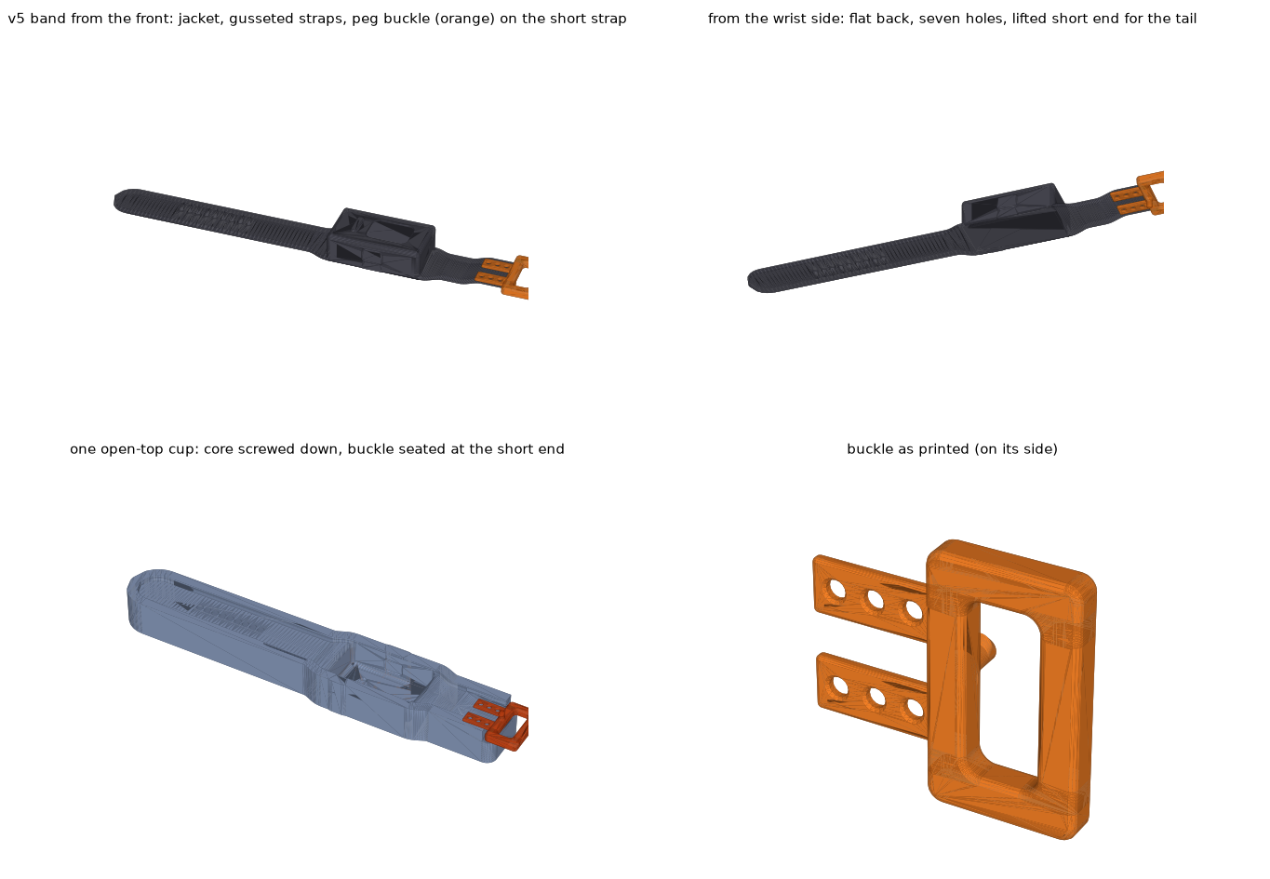
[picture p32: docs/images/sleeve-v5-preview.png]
Band v5: the one-piece silicone band with the sealed jacket and peg buckle, from the front and from the wrist side; the single open-top cup; the buckle as printed


The Fitbit-style answer: **band and jacket are one silicone part**, cast in one open pour. The jacket is v4's sealed pocket (1.5 mm back, 1.2 mm lip, pocket at the Stick's nominal size, port slit, button pads) with pebble styling (R2 plan corners, R2.5 round on the front perimeter, 0.8 round on the wrist edge). The **window matches the screen** plus 1.5 mm, so only the display shows and the lips over the Stick's ends are 7 mm (top) and 17 mm (USB-C end): the first cast had a 2 mm top lip and the Stick popped out when the band was tightened. The straps grow straight out of the end walls as a **hinge**: full 29 mm wide but only 2.0 mm thick for the first 6 mm, blending up to 2.8 by 12 mm, with an R2 fillet up the end wall and the root starting inside the jacket so there is no crevice at the sides. The jacket is nearly as long as the flat of the wrist, so the band has to bend right at the sleeve; a thin wide hinge does that at a few percent strain instead of levering the end wall. The long strap's tip is a full semicircle. No frame, no lugs, no loops: the band pulls on the jacket the way v1's did, through ten times the rubber. 16.1 mm tall, 17.0 at the button.

**Closure:** a one-piece PETG peg buckle cast into the end of the short strap. A 5 mm plate closes the strap end (its outer face shows); two 16 mm tongues, fully rounded with three chamfered holes each, anchor it mid-thickness in the strap; two 5 x 4.5 mm rails, R2 fillets at their roots and R2 outside corners, edges rounded 1 mm, carry a 5 mm crossbar that closes the frame. The **peg hangs from the underside of the plate**, centred: the long strap runs under the plate, and the short strap's tension clamps it there, so the wrist's curvature cannot lift it off (a peg at the far end of the rigid frame did lift off). 3.0 mm neck, 2.5 mm past the strap's wrist face, with a one-sided 0.9 mm bump just below the strap that the 3.4 mm hole snaps over. The lid has a pocket for it. In the mold the plate sits in a slot with a wall behind it only between the rails; the rails, crossbar and peg sit in an open pocket touching nothing, so no flash can grip them and demolding puts no load on the frame (the first, lighter frame snapped at its rail roots because flash had locked the rails in slots). To fasten: the long strap goes **under** the whole buckle from its far end (nothing goes through the frame's opening), on under the short strap, then you press the plate down onto it so the peg snaps into one of nine cast holes (5 mm pitch, sizes 150-190 mm), and the tail tucks under the short strap, whose last 12 mm are lifted 3 mm to let it through.

| File | What | Print |
|---|---|---|
| `stl/band_buckle.stl` | one-piece peg buckle | **PETG**, as exported (on its side, so the peg is strong in bending), 100% infill, 0.16 mm, **250-255 C, fan 10-20%, outer walls 30 mm/s**, supports on for the two tongue edges (threshold 60 deg keeps them off the peg) |
| `stl/band_frame_salvage.stl` | a slip-on frame for the first cast, whose buckle snapped: slides over the remnant plate, pinned with a spring bar after drilling 1.7 mm through its holes | PETG, as exported, no supports |
| `stl/band_core.stl` | Stick shape + window pad + port pocket | PLA, as exported, no supports, 3 walls |
| `stl/band_cup.stl` | one 210 x 42 mm open-top mold: jacket pocket, strap troughs, buckle seat, M3 clamp and M4 jack holes, hole-pin recesses | PLA, **placed diagonally** on the bed, brim, no supports, 0.16 mm |
| `stl/band_lid.stl` | forms the wrist face: fillet ridge, the boss that lifts the short strap's end, nine pins for the holes, vents | PLA, diagonally, no supports |
| `stl/band_preview_not_for_printing.stl` | the finished part | don't print |

**Tang buckle option (`buckle_adapter.scad` → `stl/buckle_tang_22mm.stl`):** a printed watch-style buckle that caps the cast-in plate after the frame's rails and crossbar are cut off flush. Sized for the 22 mm band (22.6 mm inner width), pivot = the Tropic strap's 22 mm spring bar (24.5 tip to tip, 2.5 body) seated in the rails 23.1 mm apart, tongue printed (`stl/buckle_tongue.stl`, flat, no supports), fixed keeper bridge behind the cap. Slide over the plate, CA glue, optional 1.6 mm pins through the side holes. Worn like a watch: long strap under the far bar, up through the opening, tongue out through a hole, tail over the pivot bar and under the keeper. Set `tongue_len` to the Tropic tongue's loop-centre-to-tip length and the plate dimensions to the band's before printing. PETG on its side, supports on.

**Casting:** release on everything. Core on the floor, pad down, two M3 x 8 up through the cup. Buckle into its seat at the short end: peg up, tongues pointing back along the trough, plate dropped into its slot; dry, no release on it. **Mix 22 g A + 22 g B** with pigment (cast volume 17.6 cm3, about 21 g). Syringe the lip layer and the front-button pocket, then pour along the whole length to just above the rim, tap. Lid on, one end first, press onto the rim; excess bleeds from the vents. Cure 24 h or 6 h at 45 C. **Demolding:** cut the flash round the lid, lever it off (the boss and pins pull out of the strap). M3 screws out, card down the jacket's long sides, M4 screws into the jack holes until the core and band rise. Peel the straps out, slide the core out through the window, punch any skin left in the holes, cut the port slit.

## Sleeve v4 (`hardware/sleeve_v4/`)

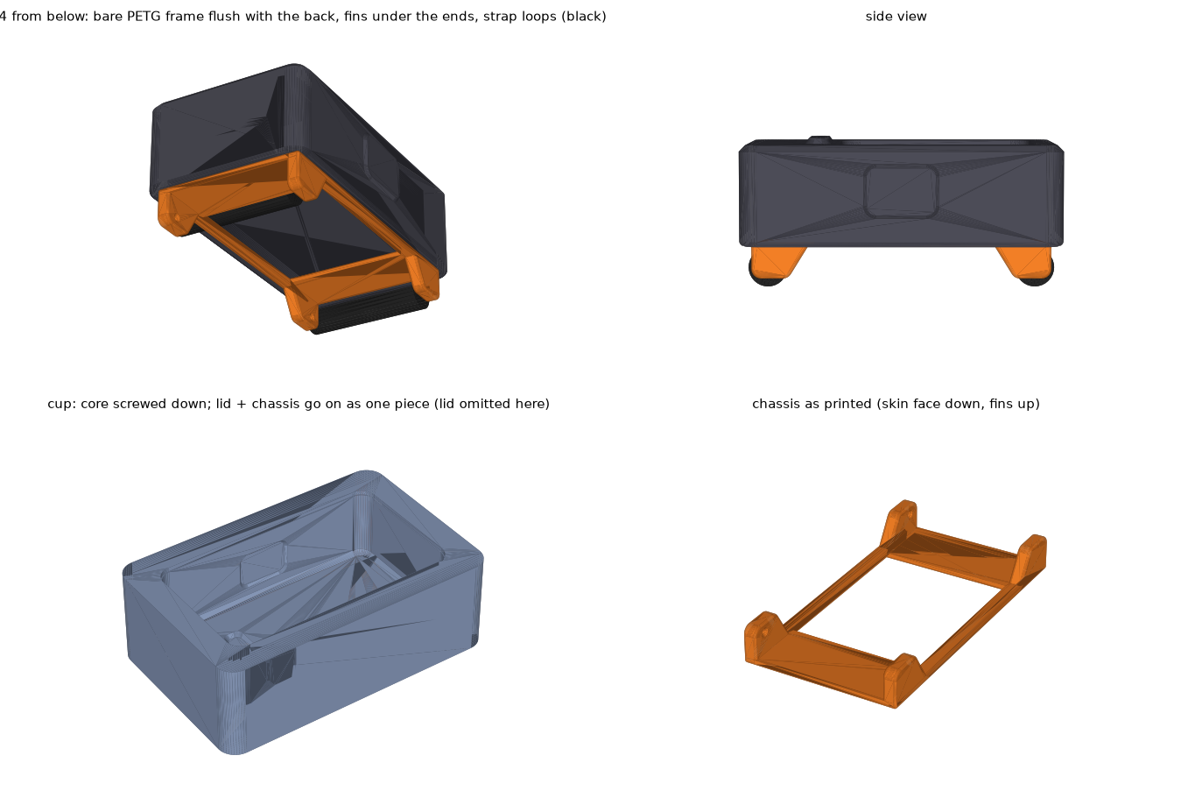
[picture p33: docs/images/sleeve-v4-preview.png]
Sleeve v4: bare PETG frame flush with the back, fins under the ends; side view; the cup with the core; the chassis as printed


v3 with the PETG frame moved **outside** the silicone: the two end brackets and two side rails sit flush in the back surface with their faces bare, like a watch caseback, and the fins grow straight off the brackets. The back is 1.5 mm (1.0 frame + 0.5 silicone skin under the Stick, so the pocket stays sealed and no PETG touches the Stick or passes through silicone), the lip over the face is 0.8. **52.4 x 29.6 x 16.8 mm, 17.7 at the front button**, against 17.2 / 18.1 for v3 and roughly 17 for the band. Frame edges on the silicone side are rounded (0.4 mm); the exposed faces have clean square perimeters so the silicone meets a vertical wall, not a feather edge.

No rim posts or tabs: the **lid locates the frame**. Four slots in the lid are 0.1 mm narrower than the fins; the lid is pushed onto the fins dry until the frame's back is flat against it, and lid + frame go onto the poured cup as one piece. Wherever the lid touched PETG the face comes out bare, so there is no film to wear through. The lid also carries the fillet ridge that rounds the back edge (cup rim straight, with a rebate), and the cup floor has two M4 jack holes for demolding.

| File | What | Print |
|---|---|---|
| `stl/sleeve_chassis.stl` | frame (2 brackets, 2 rails) + 4 fins | **PETG**, as exported (skin-side face on the bed, fins up), brim, no supports, 100% infill. Check the 1.0 mm bar holes with a spring bar tip |
| `stl/sleeve_core.stl` | Stick shape + 0.8 mm window pad + port pocket | PLA, as exported, no supports, 3 walls |
| `stl/sleeve_cup.stl` | open-top mold, straight rim with rebate, M3 clamp holes, M4 jack holes | PLA, as exported, no supports, 0.16 mm |
| `stl/sleeve_lid.stl` | lid with fillet ridge, press-fit fin slots and two vents | PLA, as exported (flat, ridge up), no supports. If a slot is too tight, sand the fin, not the slot |
| `stl/sleeve_preview_not_for_printing.stl` | the finished silicone | don't print |

**Casting:** release on everything. Core on the floor, pad down, two M3 x 8 up through the cup. Push the lid onto the chassis fins until the frame's back is flat on the lid's underside. **Mix 12 g A + 12 g B** with pigment (cast volume is 7.7 cm3). Syringe the lip layer and the front-button pocket first, pour to about 1 mm above the rim, tap. Lower lid + frame together, one end first so air escapes from under the brackets, press onto the rim; excess bleeds from the vents and slots. Cure 24 h or 6 h at 45 C. **Demolding:** cut the flash round the lid's edge with a blade and lever a corner; the lid lifts off and the frame stays in the sleeve. M3 screws out, card down the long sides, then two M4 screws into the jack holes turned alternately until the core and sleeve rise out. Peel the short-lip end off the core, slide the core out through the window, cut the port slit (12 mm, horizontal, centred on the USB-C end wall where it dents under a fingernail).

## Sleeve v3 (`hardware/sleeve_v3/`)

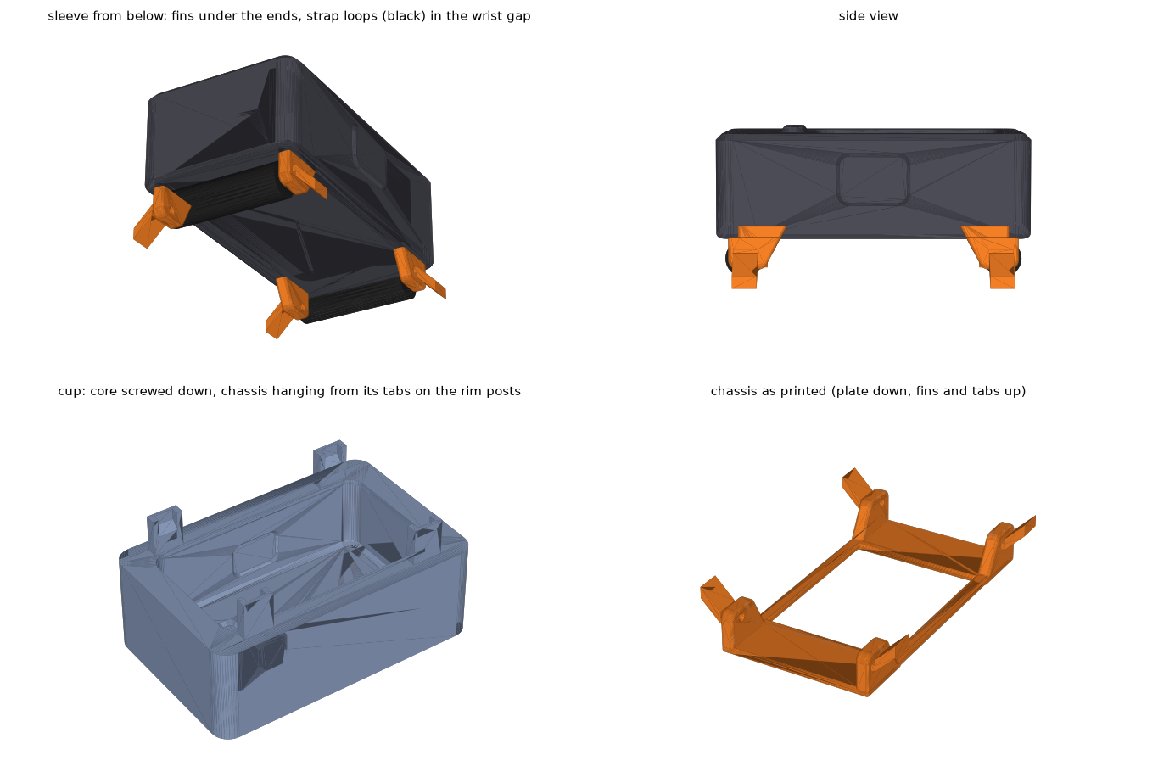
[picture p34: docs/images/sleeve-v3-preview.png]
Sleeve v3: fins under the ends carry the spring bars; the cup with core and chassis; the chassis as printed


Same sealed jacket as v2, but the strap lugs are **under the ends instead of past them**, so the sleeve is 51.8 x 29.0 x 17.2 mm (+0.9 button bump) against v2's 65.4 x 28.6 x 18.3 and the band's roughly 16 over the wrist, with a 0.8 mm round on the back edge. The round is formed by a fillet ridge on the **lid**, never by an undercut in the cup: the first cast used a rim lip and the sleeve had to be cut out of the mold. The cup's rim is straight, with a 0.9 mm rebate the ridge sits in. A PETG **chassis frame** with every edge rounded (0.4 mm radius, so nothing sharp bears on the silicone) is buried in the 2.4 mm back layer: two 1.2 mm end brackets under the ends of the Stick, joined by two 1.0 x 2.2 mm rails along the sides under the pocket's edge. The rails carry the strap tension (about 20 kgf) but bend easily, so the middle of the back is plain silicone and the sleeve still flexes to get the Stick in and out (a full plate, tried first, made that hard). 0.4 mm of silicone sits between the brackets and the Stick, 0.8 mm between them and the wrist. The lip over the face is 1.0 mm: it retains and seals, and it is what sets the height. Four **fins** grow down from the brackets inside the sleeve's footprint, 2.2 mm thick with 1.6 mm of silicone outside them, and protrude 5.1 mm below the back. The 22 mm spring bar spans each pair (21.4 mm gap, 1.0 mm blind holes), so the strap end wraps a bar 3.5 mm under the sleeve's end, in the gap a straight sleeve leaves over a curved wrist. Strap tension goes into the plate, not the silicone. Nothing is closer than 0.5 mm to a surface and the only PETG you see is the fins.

The chassis hangs in the mold from four **tabs that rest on posts on the cup rim**, entirely above the pour, so nothing gets cut near silicone: the tabs sit on 45-degree seats and slide outward until their tips meet a stop wall, which centres the chassis and sets its height. Twist them off at their 0.6 mm necks afterwards.

| File | What | Print |
|---|---|---|
| `stl/sleeve_chassis.stl` | frame (2 brackets, 2 rails) + 4 fins + 4 tabs | **PETG**, as exported (plate on the bed), brim, no supports, 100% infill, 245-250 C, fan 20-30%. Check the 1.0 mm bar holes with a spring bar tip; open with a 1 mm bit if needed |
| `stl/sleeve_core.stl` | Stick shape + window pad + port pocket | PLA, as exported (back face down), no supports, 3 walls; the port pocket is only 0.7 mm proud so it prints without support |
| `stl/sleeve_cup.stl` | open-top mold, straight rim with a rebate for the lid ridge, four rim posts, two M3 clamp holes and two M4 jack holes in the floor | PLA, as exported (open top up), no supports, 0.16 mm |
| `stl/sleeve_lid.stl` | lid with the fillet ridge that rounds the back edge, and openings for the fins, tabs and posts. Use it; without it the back edge is square | PLA, as exported, no supports |
| `stl/sleeve_preview_not_for_printing.stl` | the finished silicone | don't print |

**Casting** (open pour, window face down, same as v2): release on everything. Core on the floor, pad down, two M3 x 8 screws up through the cup's underside. **Mix 17 g A + 17 g B** with pigment. Syringe the lip layer and the front-button pocket first, then pour until the core's back is under about a millimetre of silicone. Lower the chassis in, fins up, one end first so the air runs out from under the plate, until the tabs land on the posts; press gently until the tab tips touch the stop walls. Top up to just above the rim, tap, then press the sprayed lid on (its ridge forms the rounded back edge; excess comes out of the openings). Cure 24 h, or about 6 h with the cup on the printer bed at 45 C: the preheat menu times out after ~10 min, so send `tools/bedhold_45c_ff.gcode` as a print job instead (it only holds the bed, no motion; stop the job to end it early). **Demolding:** cut the flash round the lid's edge with a blade and lever a corner; it lifts straight off the fins. M3 screws out. Slide a card down both long sides to the floor to break the vacuum. Then two **M4 screws into the jack holes** in the floor (the two plain holes between the M3 recesses), turned alternately a couple of turns at a time: they tap the PLA and push the core's pad, and the core lifts the sleeve out. Never pry against the silicone edge or pull on the tabs. Peel the short-lip end off the core, slide the core out through the window. Small tears from a bad demold can be glued with Sil-Poxy (not superglue, not fresh 945); glued tears in a lip will reopen eventually, tears in the back or walls hold. Twist the tabs off and shave the stubs with a blade flat on the fin. Cut the port slit: 12 mm, horizontal, centred on the USB-C end wall, where it dents under a fingernail; the wall is 1.5 mm there and 2.2 mm at the slit ends.

**Strap:** spring bars into the fin holes from between the fins. The strap end sits under the sleeve's end and leaves downward.

`hardware/sleeve/` is the earlier design: a thinner sleeve with a PETG lug frame cast into its back. Kept with its STLs for reference.

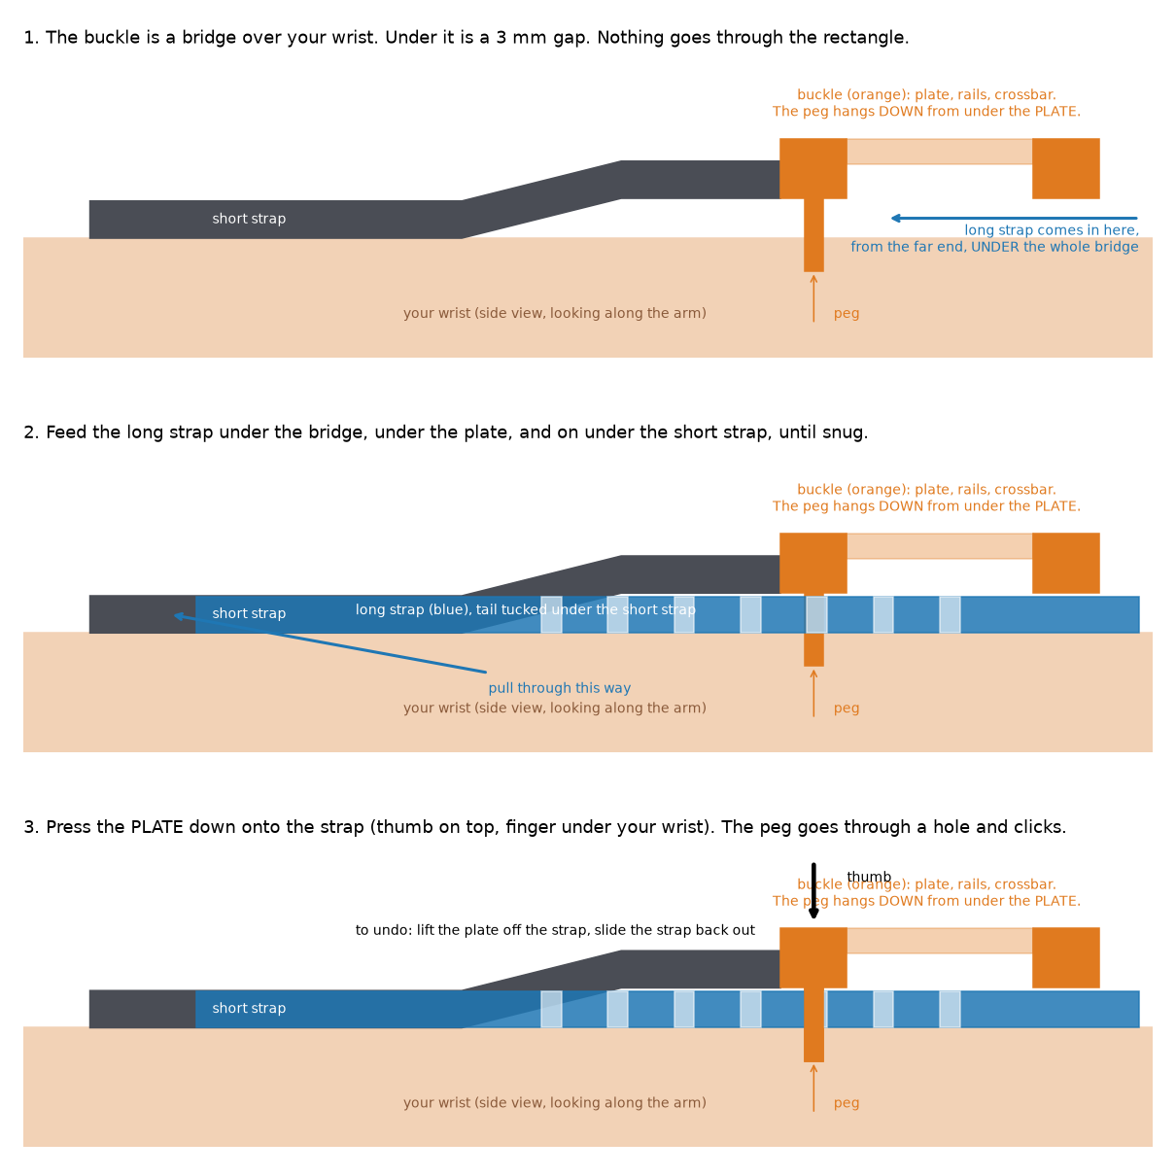
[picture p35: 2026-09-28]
docs/images/buckle-howto-v2.png

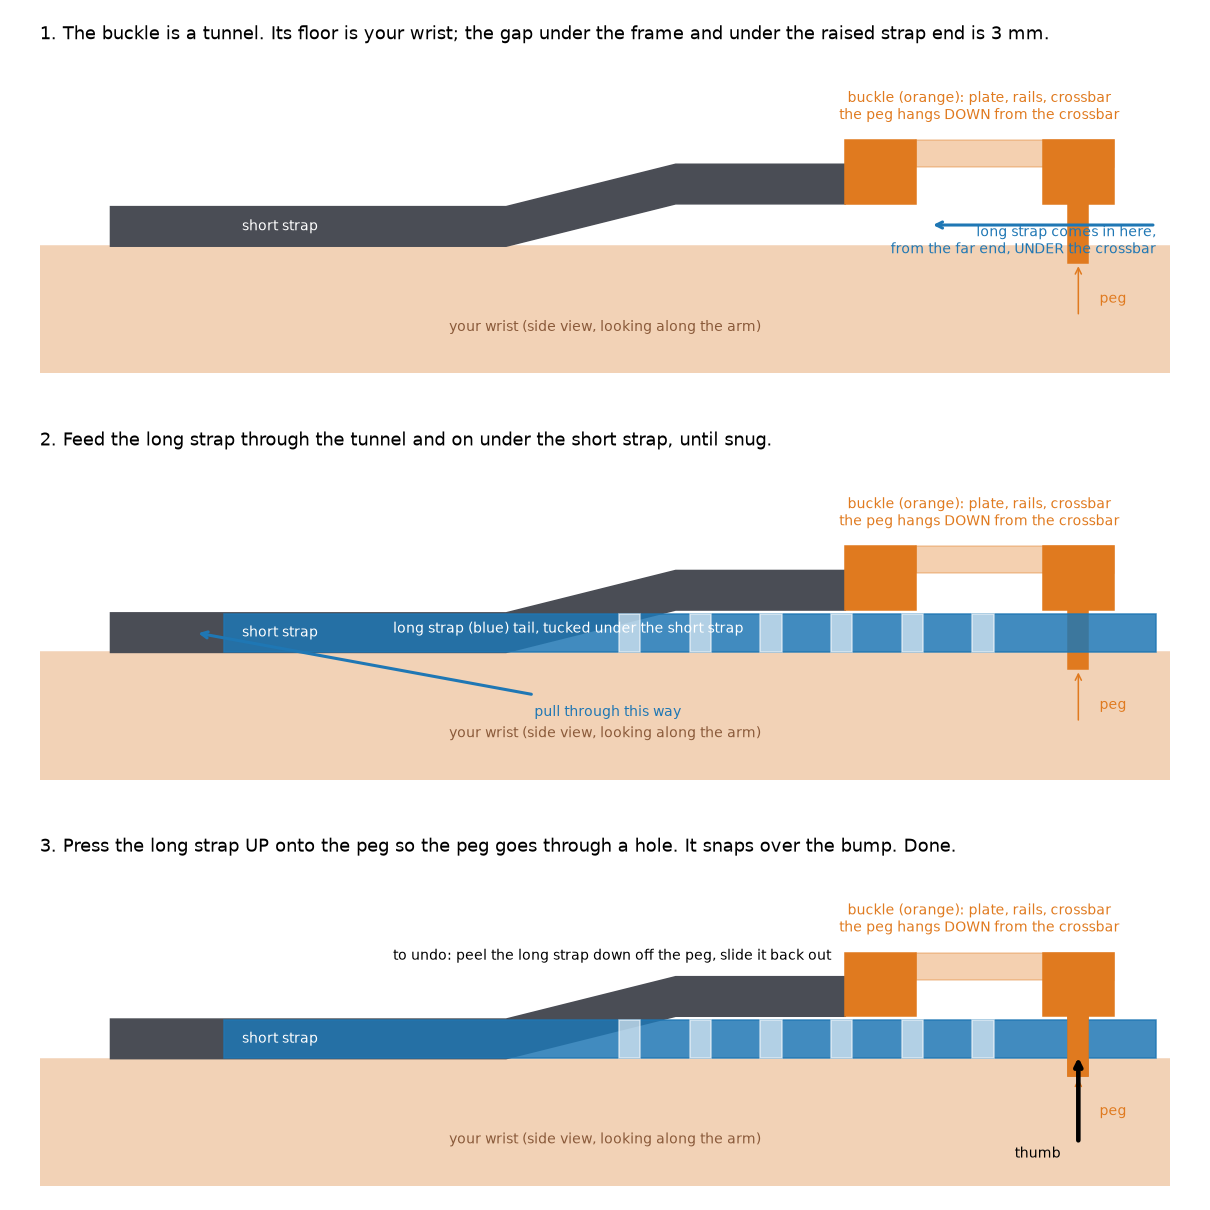
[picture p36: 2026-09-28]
docs/images/buckle-howto.png

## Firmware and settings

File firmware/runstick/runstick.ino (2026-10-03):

//
// RunStick -- M5Stack StickS3 BLE run display.
//
//   phone app --BLE--> this Stick --> two big numbers on the wrist
//
// The Stick is a dumb peripheral: it never talks to the chest strap or the GPS,
// it just shows what the phone writes to it (docs/ble-protocol.md).
//
// Build: tools/build-firmware.sh  (see firmware/README.md)
//

#include <M5Unified.h>
#include <Preferences.h>

#include "config.h"
#include "protocol.h"
#include "ble_link.h"
#include "ui.h"

// ------------------------------------------------------------------- state

static Preferences g_prefs;

static uint8_t g_brightIdx = kBrightnessDefault;
static bool    g_flipped   = false;

static uint8_t  g_screen         = SCREEN_BOOT;
static bool     g_everConnected  = false;
static uint32_t g_extrasUntilMs  = 0;

static uint32_t g_btnBDownMs     = 0;
static bool     g_btnBLongFired  = false;

static uint32_t g_lastLinkMs     = 0;   // last time we had a phone (or boot)
static uint32_t g_lastDrawMs     = 0;
static bool     g_forceRedraw    = true;
static UiState  g_lastUi         = {};

static uint32_t g_lastLogMs      = 0;
static uint32_t g_seenConnects   = 0;
static uint32_t g_seenDisconnect = 0;

static int16_t  g_statusPct      = -1;  // -1 forces the first STATUS write
static bool     g_statusChg      = false;
static uint32_t g_statusSentMs   = 0;

// ------------------------------------------------------------- small helpers

static bool stickCharging() {
  // isCharging() is a tri-state (unknown / discharging / charging), so compare
  // against the enum rather than treating it as a bool.
  return M5.Power.isCharging() == m5::Power_Class::is_charging;
}

static int16_t stickBatteryPct() {
  const int32_t level = (int32_t)M5.Power.getBatteryLevel();
  if (level < 0)   return -1;              // unknown
  if (level > 100) return 100;
  return (int16_t)level;
}

static void applyRotation()   { M5.Display.setRotation(g_flipped ? 2 : 0); }
static void applyBrightness() { M5.Display.setBrightness(kBrightnessLevels[g_brightIdx]); }

// --------------------------------------------------------------- UI plumbing

static void buildUiState(UiState& st, uint32_t now, const BleSnapshot& snap) {
  // The 5 s rule is purely about packet age, not about the link: a phone that
  // is connected but silent goes stale, and a phone that just dropped keeps its
  // last numbers on screen for the remainder of the 5 s.
  const bool stale = !snap.haveData || (uint32_t)(now - snap.lastPacketMs) > kStaleMs;

  st.screen     = g_screen;
  st.connected  = snap.connected;
  st.stale      = stale;
  st.hrShown    = !stale && snap.data.hrValid();
  st.hrZone     = st.hrShown ? snap.data.hrZone() : 0;
  st.paceShown  = !stale && snap.data.paceValid();
  st.gpsOk      = snap.data.gpsOk();
  st.strapOk    = snap.data.strapOk();
  st.charging   = stickCharging();
  st.hr         = snap.data.hr_bpm;
  st.pace       = snap.data.pace_s_per_mile;
  st.elapsed    = snap.data.elapsed_s;
  st.distance   = snap.data.distance_cmi;
  st.batteryPct = stickBatteryPct();
}

static void render(uint32_t now, const BleSnapshot& snap) {
  UiState st;
  buildUiState(st, now, snap);

  const bool due = (uint32_t)(now - g_lastDrawMs) >= kRedrawIntervalMs;
  if (!g_forceRedraw && !due && st.sameAs(g_lastUi)) return;

  g_forceRedraw = false;
  g_lastUi      = st;
  g_lastDrawMs  = now;
  uiRender(st);
}

// ------------------------------------------------------------------ buttons

static void handleButtons(uint32_t now) {
  // BtnA (front, GPIO11): flick to the extras screen and back.
  if (M5.BtnA.wasPressed()) {
    // Refresh the deadline on every press, not just on the way in, so a stale
    // g_extrasUntilMs can never make the screen flash and vanish in one pass.
    g_extrasUntilMs = now + kExtrasTimeoutMs;
    g_screen = (g_screen == SCREEN_EXTRAS)
                 ? (g_everConnected ? SCREEN_MAIN : SCREEN_BOOT)
                 : SCREEN_EXTRAS;
    g_forceRedraw = true;
  }

  // BtnB (side KEY2, GPIO12): short press cycles the backlight, >= 1 s flips
  // the screen 180 for the other wrist.
  //
  // Done on raw press/release edges rather than wasClicked()/wasHold() so the
  // long-press threshold is exactly kLongPressMs and nothing depends on
  // M5Unified's internal click-count timing.
  if (M5.BtnB.wasPressed()) {
    g_btnBDownMs    = now;
    g_btnBLongFired = false;
  }
  if (M5.BtnB.isPressed() && !g_btnBLongFired &&
      (uint32_t)(now - g_btnBDownMs) >= kLongPressMs) {
    g_btnBLongFired = true;
    g_flipped = !g_flipped;
    g_prefs.putBool(RUNSTICK_NVS_FLIP, g_flipped);
    applyRotation();
    g_forceRedraw = true;
    Serial.printf("[ui] rotation=%d (saved)\n", g_flipped ? 2 : 0);
  }
  if (M5.BtnB.wasReleased() && !g_btnBLongFired) {
    g_brightIdx = (uint8_t)((g_brightIdx + 1) % 3);
    g_prefs.putUChar(RUNSTICK_NVS_BRIGHT, g_brightIdx);
    applyBrightness();
    Serial.printf("[ui] brightness=%u (saved)\n", (unsigned)kBrightnessLevels[g_brightIdx]);
  }
  // The sleep-notice loop in checkIdlePowerOff() runs its own M5.update() and
  // can swallow the release edge, so clear the latch on button state rather
  // than relying on wasReleased() ever being seen here.
  if (!M5.BtnB.isPressed()) g_btnBLongFired = false;
}

// ------------------------------------------------------------------ STATUS

static void updateStatusCharacteristic(uint32_t now, bool connected) {
  const int16_t pct = stickBatteryPct();
  const bool    chg = stickCharging();

  const bool changed   = (pct != g_statusPct) || (chg != g_statusChg);
  const bool heartbeat = connected && (uint32_t)(now - g_statusSentMs) >= kStatusHeartbeatMs;
  if (!changed && !heartbeat) return;

  g_statusPct    = pct;
  g_statusChg    = chg;
  g_statusSentMs = now;
  // Always refresh the value (so a plain read is current); only notify when
  // someone is actually listening.
  bleSetStatus((uint8_t)(pct < 0 ? 0 : pct), chg, connected);
}

// ------------------------------------------------------------------ logging

static void logLinkEvents() {
  const uint32_t connects = bleConnectEvents();
  if (connects != g_seenConnects) {
    g_seenConnects = connects;
    Serial.printf("[ble] connected (#%u)\n", (unsigned)connects);
  }
  const uint32_t disconnects = bleDisconnectEvents();
  if (disconnects != g_seenDisconnect) {
    g_seenDisconnect = disconnects;
    const int reason = bleLastDisconnectReason();
    Serial.printf("[ble] disconnected (#%u) reason=%d 0x%02X\n",
                  (unsigned)disconnects, reason, (unsigned)(reason & 0xFF));
  }
}

// One line a second while connected. The mA figure is the whole point of this
// log: it is what the 2 h battery target gets tuned against.
static void logRun(uint32_t now, const BleSnapshot& snap) {
  if (!snap.connected) return;
  if ((uint32_t)(now - g_lastLogMs) < kSerialLogMs) return;
  g_lastLogMs = now;

  const bool     stale = !snap.haveData || (uint32_t)(now - snap.lastPacketMs) > kStaleMs;
  const uint32_t age   = snap.haveData ? (uint32_t)(now - snap.lastPacketMs) : 0;

  char hr[8], pace[8], elapsed[16], dist[16];
  formatHeartRate(snap.data.hr_bpm, hr, sizeof(hr));
  formatPace(snap.data.pace_s_per_mile, pace, sizeof(pace));
  formatElapsed(snap.data.elapsed_s, elapsed, sizeof(elapsed));
  formatDistance(snap.data.distance_cmi, dist, sizeof(dist));

  char zone[16] = "";
  if (snap.data.hrZone() != 0) snprintf(zone, sizeof(zone), " Z%u", (unsigned)snap.data.hrZone());

  char flags[40];
  snprintf(flags, sizeof(flags), "%s%s%s%s%s%s",
           snap.data.hrValid()   ? " HR"    : "",
           snap.data.paceValid() ? " PACE"  : "",
           snap.data.runActive() ? " RUN"   : "",
           snap.data.gpsOk()     ? " GPS"   : "",
           snap.data.strapOk()   ? " STRAP" : "",
           zone);

  Serial.printf("[run] hr=%-3s pace=%-5s t=%-8s d=%-8s flags=0x%02X%s age=%ums%s "
                "batt=%d%% %dmV %dmA%s pkt=%u bad=%u\n",
                snap.data.hrValid()   ? hr   : "--",
                snap.data.paceValid() ? pace : "--",
                elapsed, dist,
                (unsigned)snap.data.flags, flags,
                (unsigned)age, stale ? " STALE" : "",
                (int)stickBatteryPct(),
                (int)M5.Power.getBatteryVoltage(),
                (int)M5.Power.getBatteryCurrent(),
                stickCharging() ? " CHG" : "",
                (unsigned)snap.packets, (unsigned)snap.rejects);
}

// --------------------------------------------------------------- idle sleep

static void checkIdlePowerOff(uint32_t now, const BleSnapshot& snap) {
  if (snap.connected) return;
  if (stickCharging()) return;                                  // on USB: stay up
  if ((uint32_t)(now - g_lastLinkMs) < kIdlePowerOffMs) return;

  Serial.println("[power] 10 min with no phone -> powering off");

  UiState st;
  buildUiState(st, now, snap);
  st.screen = SCREEN_SLEEPING;
  uiRender(st);

  const uint32_t start = millis();
  bool cancelled = false;
  while ((uint32_t)(millis() - start) < kSleepNoticeMs) {
    M5.update();
    if (M5.BtnA.wasPressed() || M5.BtnB.wasPressed()) { cancelled = true; break; }
    if (bleSnapshot().connected)                      { cancelled = true; break; }
    delay(25);
  }

  // A phone turning up, or USB going in, during the 3 s notice is the realistic
  // case -- re-check rather than powering off through it.
  if (cancelled || bleSnapshot().connected || stickCharging()) {
    Serial.println("[power] power-off cancelled");
    g_lastLinkMs  = millis();
    g_forceRedraw = true;
    return;
  }

  M5.Power.powerOff();

  // Only reached if the rail could not actually be cut (USB attached). Re-arm
  // so we don't sit spinning on the notice screen.
  g_lastLinkMs  = millis();
  g_forceRedraw = true;
}

// --------------------------------------------------------------------- boot

void setup() {
  auto cfg = M5.config();
  cfg.serial_baudrate = 115200;
  cfg.clear_display   = true;
  cfg.internal_imu    = false;   // nothing here reads motion
  cfg.internal_spk    = false;   // no sound: leave the amp unpowered
  cfg.internal_mic    = false;
  cfg.output_power    = false;   // don't push 5 V out of the Grove port
  M5.begin(cfg);

  g_prefs.begin(RUNSTICK_NVS_NAMESPACE, false);
  g_brightIdx = g_prefs.getUChar(RUNSTICK_NVS_BRIGHT, kBrightnessDefault);
  if (g_brightIdx > 2) g_brightIdx = kBrightnessDefault;
  g_flipped = g_prefs.getBool(RUNSTICK_NVS_FLIP, false);

  applyRotation();
  applyBrightness();
  uiBegin();

  // Light the boot screen before anything slow, so the Stick looks alive.
  {
    UiState st;
    BleSnapshot empty = {};
    buildUiState(st, millis(), empty);
    st.screen = SCREEN_BOOT;
    uiRender(st);
    g_lastUi = st;
  }

  // Native USB CDC only enumerates once the host opens the port; give it a
  // moment so the boot diagnostics below are not lost. Bounded, so running on
  // battery costs at most ~1.2 s.
  const uint32_t serialWaitStart = millis();
  while (!Serial && (uint32_t)(millis() - serialWaitStart) < 1200) { delay(10); }

  Serial.println();
  Serial.println("[boot] RunStick  built " __DATE__ " " __TIME__);
  Serial.printf("[boot] sprite=%s rotation=%d brightness=%u\n",
                g_canvasReady ? "135x240 ok" : "FAILED (drawing direct to LCD)",
                g_flipped ? 2 : 0, (unsigned)kBrightnessLevels[g_brightIdx]);
  uiLogFontTable();

#ifdef RUNSTICK_SELFTEST
  {
    char report[1600];
    const int fails = runstickSelfTest(report, sizeof(report));
    Serial.println("[selftest] protocol.h golden vector");
    Serial.print(report);
    Serial.printf("[selftest] %s\n", fails == 0 ? "PASS" : "FAIL");
  }
#endif

  bleBegin();
  Serial.printf("[ble] advertising=%s, name is %s\n",
                bleAdvertisingStarted() ? "yes" : "NO -- NOTHING TO CONNECT TO",
                bleNameInScanResponse() ? "in the scan response (adv payload was full)"
                                        : "in the advertising data");

  // 80 MHz is the floor with the radio on. Set it after the stack is up so
  // NimBLE initialises at full speed.
  setCpuFrequencyMhz(80);
  Serial.printf("[boot] cpu=%uMHz heap=%u\n",
                (unsigned)getCpuFrequencyMhz(), (unsigned)ESP.getFreeHeap());

  g_lastLinkMs  = millis();
  g_lastDrawMs  = millis();
  g_forceRedraw = true;
}

// --------------------------------------------------------------------- loop

void loop() {
  M5.update();
  const uint32_t now = millis();

  handleButtons(now);

  const BleSnapshot snap = bleSnapshot();
  if (snap.connected) {
    g_lastLinkMs = now;
    if (!g_everConnected) {
      g_everConnected = true;
      if (g_screen == SCREEN_BOOT) g_screen = SCREEN_MAIN;
    }
  }

  logLinkEvents();
  bleEnsureAdvertising();
  updateStatusCharacteristic(now, snap.connected);
  logRun(now, snap);

  if (g_screen == SCREEN_EXTRAS && (int32_t)(now - g_extrasUntilMs) >= 0) {
    g_screen      = g_everConnected ? SCREEN_MAIN : SCREEN_BOOT;
    g_forceRedraw = true;
  }

  checkIdlePowerOff(now, snap);
  render(now, snap);

  delay(kLoopDelayMs);
}

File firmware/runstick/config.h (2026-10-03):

#pragma once
//
// Everything tunable in one place: BLE identity, timings, brightness steps,
// colours and the portrait screen layout.
//

#include <stdint.h>

// ------------------------------------------------------------------ BLE ids
// Must match docs/ble-protocol.md exactly; the phone app finds us by the
// service UUID and remembers the MAC.

#define RUNSTICK_DEVICE_NAME  "RunStick"
#define RUNSTICK_SVC_UUID     "7a1c0001-5f3e-4b2a-9c6d-2f8e41d0b7a5"
#define RUNSTICK_DATA_UUID    "7a1c0002-5f3e-4b2a-9c6d-2f8e41d0b7a5"
#define RUNSTICK_STATUS_UUID  "7a1c0003-5f3e-4b2a-9c6d-2f8e41d0b7a5"

// Preferred connection parameters (docs: 300-500 ms, latency 0, 6 s timeout).
//
// NimBLE 2.x moved *timeouts* (scan/advertise/connect duration) to milliseconds,
// but NimBLEServer::updateConnParams() forwards straight to ble_gap_upd_params,
// which is still BLE-native: interval in 1.25 ms steps, supervision timeout in
// 10 ms steps. If a link comes up with an absurd interval, this is the one
// place to flip -- the numbers in the comments are the real-world values.
static const uint16_t kConnIntervalMinUnits = 240;  //  300 ms / 1.25 ms
static const uint16_t kConnIntervalMaxUnits = 400;  //  500 ms / 1.25 ms
static const uint16_t kConnLatency          = 0;
static const uint16_t kConnTimeoutUnits     = 600;  // 6000 ms / 10 ms

// Radio power. The phone is on the same wrist-to-pocket distance all run; the
// default (+9 dBm) is more than we need and costs battery.
static const int8_t kBleTxPowerDbm = 3;

// ----------------------------------------------------------------- timings

static const uint32_t kStaleMs           = 5000;             // docs: 5 s -> "--"
static const uint32_t kStatusHeartbeatMs = 60000;            // docs: notify >= 1/60 s
static const uint32_t kExtrasTimeoutMs   = 5000;             // extras screen auto-return
static const uint32_t kIdlePowerOffMs    = 10UL * 60UL * 1000UL;
static const uint32_t kSleepNoticeMs     = 3000;
static const uint32_t kSerialLogMs       = 1000;
static const uint32_t kRedrawIntervalMs  = 1000;             // forced repaint floor
static const uint32_t kLoopDelayMs       = 20;
static const uint32_t kLongPressMs       = 1000;             // BtnB hold -> flip 180

// -------------------------------------------------------------- brightness
// Real PWM on this board. Index 1 (middle) is the default.

static const uint8_t kBrightnessLevels[3] = { 40, 110, 220 };
static const uint8_t kBrightnessDefault   = 1;

// --------------------------------------------------------------------- NVS

#define RUNSTICK_NVS_NAMESPACE "runstick"
#define RUNSTICK_NVS_BRIGHT    "bright"
#define RUNSTICK_NVS_FLIP      "flip"

// ------------------------------------------------------------------ colours

static constexpr uint16_t rgb565(uint8_t r, uint8_t g, uint8_t b) {
  return (uint16_t)(((uint16_t)(r & 0xF8) << 8) | ((uint16_t)(g & 0xFC) << 3) | (uint16_t)(b >> 3));
}

static const uint16_t kColBg        = rgb565(  0,   0,   0);
static const uint16_t kColNumber    = rgb565(255, 255, 255);
static const uint16_t kColStaleNum  = rgb565( 70,  70,  70);  // the "--" grey
static const uint16_t kColHrLabel   = rgb565(255,  48,  48);
static const uint16_t kColPaceLabel = rgb565(  0, 216, 255);
static const uint16_t kColStripText = rgb565(160, 160, 160);
static const uint16_t kColRule      = rgb565( 40,  40,  40);
static const uint16_t kColLinkOk    = rgb565(  0, 224,  96);
static const uint16_t kColLinkStale = rgb565(255, 176,   0);
static const uint16_t kColLinkWait  = rgb565( 96,  96,  96);
static const uint16_t kColFlagOk    = rgb565(  0, 224,  96);
static const uint16_t kColFlagBad   = rgb565(110, 110, 110);

// Heart-rate zone digit, index = zone (0 unused). Saturated and far apart in hue so
// they stay distinct on the small panel in daylight. Z4 is the same family as the
// red BPM label; the digit is told apart by being a much bigger, bolder glyph.
static const uint16_t kColZone[6] = {
  rgb565(  0,   0,   0),   // 0: no zone, never drawn
  rgb565(  0, 230,  90),   // 1 green
  rgb565(255, 225,   0),   // 2 yellow
  rgb565(255, 140,   0),   // 3 orange
  rgb565(255,  30,  30),   // 4 red
  rgb565(230,   0, 170),   // 5 reddish purple
};

// ------------------------------------------------------------------ layout
// Portrait: the Stick lies across the wrist, so the panel is 135 wide x 240
// tall (rotation 0, or 2 when flipped for the other wrist).

static const int kScreenW = 135;
static const int kScreenH = 240;

static const int kStripH  = 20;                        // link / battery strip
static const int kHalfH   = (kScreenH - kStripH) / 2;  // 110 px per number block
static const int kHrTop   = kStripH;
static const int kPaceTop = kStripH + kHalfH;
static const int kLabelH  = 22;                        // "BPM" / "/MI" band
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

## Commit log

2026-09-17 Add StickS3 band mold and clip mount
    Parametric OpenSCAD sources plus exported STLs for a wrist-worn display
    built on an M5Stack StickS3 (K150):
    - One-piece silicone band cast in a 3-part PLA mold (two halves + a core
    that forms the Stick pocket). Sized for a 165 mm wrist; 7 punched holes
    give 152-188 mm. Screen, front button and both side buttons stay clear.
    - Clip mount in PETG that bolts to a theclip.com MCS-631SS (or MCS-661)
    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
    [band_core_default.stl, band_core_looser.stl, band_core_tighter.stl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]
2026-09-17 Reorganize repo for firmware and app
    Hardware moves under hardware/band and hardware/clip, each with its
    OpenSCAD source and exported STLs. Notes split into docs/build-notes.md
    (printing, casting, assembly) and docs/shopping-list.md.
    Adds a top-level README describing how the strap, phone and Stick talk to
    each other, plus firmware/ and app/ placeholders spelling out what each
    one has to do and the constraints it runs under.
    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
    [band_core_default.stl, band_core_looser.stl, band_core_tighter.stl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]
2026-09-21 Add slicer projects for the band mold
    Flash Studio .3mf projects for the two mold halves and the default core,
    sliced for the Adventurer 5M in PLA at 0.16 mm. They carry the plate
    layout and process settings so the parts can be re-sliced and printed
    without re-deriving them.
    Claude-Session: https://claude.ai/code/session_01Kw5D8XLGiU8qs5FfNxa5bB
    [band_core_default.3mf, band_mold_bottom.3mf, band_mold_top.3mf]
2026-09-21 Add RunStick firmware, Android app and build tooling
    docs/ble-protocol.md defines the link: the Stick is a BLE peripheral with
    one write characteristic carrying a 9-byte packet (HR, pace, elapsed,
    distance, validity flags) at 1 Hz, and a status characteristic reporting
    its battery back. Both sides test against the same golden vector.
    firmware/runstick: portrait UI with the largest digits that fit, a 5 s
    stale rule, extras screen on the front button, brightness and 180-degree
    flip on the side button, idle power-off. NimBLE 2.x.
    app: foreground service that reads the chest strap over raw BluetoothGatt
    (it must never disable the strap's CCCD, because Strava shares the link),
    derives pace from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
    [PacketEncoderTest.kt]
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2026-09-23 Add the Tropic-strap sleeve: silicone pocket with a cast-in lug frame
    Same pocket and thickness as the band, but a thin PETG frame lives in the
    back wall and carries four lug horns for a 22 mm strap on spring bars
    (21.5 mm gap, bar 4 mm out / 3 mm up, 1.0 mm holes). The mold splits at
    the frame's top face so the frame drops in flat, the core sits in the
    frame's opening, and the top half lifts straight off. A new core with side
    ribs forms the button openings. Fit-checked: no overlaps between frame,
    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
    [band_core_default.3mf, band_mold_bottom.3mf, sleeve_core.stl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]
2026-09-23 Sleeve: thicker lug horns with a flare outside the wall
    The first PETG frame snapped at the horns when it was pried off the plate.
    Horns are now 3 mm thick through the end wall (was 2.5), start further in
    so the root spans the whole wall, and flare to 4 mm outside the sleeve
    where nothing constrains them. Lug gap 21.4 mm. Mold slots follow.
    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
    [band_mold_top.3mf, sleeve_frame.stl, sleeve_mold.scad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]
2026-09-23 Sleeve: bring the lug bars in to 2 mm from the end wall
    Horns now stand 4.2 mm proud instead of 6.5 (60 mm tip to tip). The strap
    end rests against the soft end wall like a normal watch strap on a case.
    Shorter horns also have less lever arm.
    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
    [sleeve_frame.stl, sleeve_mold.scad, sleeve_mold_bottom.stl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]
2026-09-23 Sleeve: turn the lug horns down toward the wrist
    The flat horns stood off the wrist at the ends. The bar now sits 1.5 mm
    below the sleeve's back face and the horn tapers down to it, so the strap
    leaves from under the sleeve's edge. Bottom tray deepened for the slots.
    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
    [sleeve_frame.stl, sleeve_mold.scad, sleeve_mold_bottom.stl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]
2026-09-23 Sleeve: gradual wrist curve from the back-window edge outward
    The frame's back is flat under the Stick and, from 21 mm out, follows an
    18 mm radius arc down toward the wrist. The ring ends, the horns and the
    sleeve's own back follow it, so the strap leaves from the wrist instead
    of from a straight lug standing off it. Mold tray follows the curve.
    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
    [sleeve_frame.stl, sleeve_mold.scad, sleeve_mold_bottom.stl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]
2026-09-23 Sleeve: tighten the wrist curve to a 12 mm radius
    The 18 mm curve still left about 2 mm under the horn tips on the wrist.
    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
    [sleeve_frame.3mf, sleeve_frame.stl, sleeve_mold.scad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]
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2026-09-23 Sleeve: regenerate the 9 mm curve; tray-depth checks follow the real horn shape
    The previous commit changed the radius but the STLs had failed to render:
    the tray-depth assertion assumed the arc continued under the horn tip,
    where the horn is actually its rounded end above the arc. The checks now
    look at the sleeve end and the horn's real lowest point.
    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
    [sleeve_frame.stl, sleeve_mold.scad, sleeve_mold_bottom.stl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]
2026-09-23 Sleeve: no heel under the horn tips past the bar
    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
    [sleeve_frame.stl, sleeve_mold.scad, sleeve_mold_bottom.stl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]
2026-09-23 Sleeve: wrist curve starts under the Stick (16 mm out, 15 mm radius)
    The earlier curves began at the back-window edge, so the bend was confined
    to the last 5 mm of sleeve and the horns barely moved. The curve now starts
    16 mm from centre: the flat Stick rests on the middle, a silicone wedge
    fills under its ends, and the sleeve, frame ring and horns all wrap the
    wrist. The core's back pad follows the curve; bottom tray deepened; bolt
    head pockets added so M3x30 still reaches.
    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
    [sleeve_core.stl, sleeve_core_upper_lower.3mf, sleeve_frame.3mf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]
2026-09-24 Sleeve frame: flat top, thick curved underside, prints with no supports
    Prying supports off the thin curved ring cracked a frame in half. The
    frame's top is now flat across its whole length (the Stick's back plane)
    and the underside carries the wrist curve, so the ring thickens toward the
    ends and the horns sit at or below the top. Printed upside down it needs no
    supports, and the horn roots attach to 5 mm of PETG instead of 1.5.
    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
    [sleeve_frame.3mf, sleeve_frame.stl, sleeve_mold.scad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]
2026-09-24 Sleeve tray: horn slot clearance only outside the sleeve outline
    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
    [sleeve_mold.scad, sleeve_mold_bottom.stl]
2026-09-24 Sleeve tray: exact horn seat inside the outline, clearance outside
    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
    [sleeve_mold.scad, sleeve_mold_bottom.stl]
2026-09-24 Sleeve tray: horn slot clearance from 1.5 mm inside the end; mesh is a clean volume again
    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
    [sleeve_mold.scad, sleeve_mold_bottom.stl]
2026-09-24 Sleeve mold: 0.35 mm horn slot clearance (printed horns come out fat)
    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
    [sleeve_core_upper_lower.3mf, sleeve_frame.3mf, sleeve_mold.scad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]
2026-09-24 Sleeve: flat-topped horns so the frame drops into open slots
    The horn tips sloped down below the parting plane, which left PLA above
    them in the tray: the slots were closed tunnels and a printed frame could
    not be seated. Horn tops are now flush with the frame's top out to the tip
    (the top mold half seals them), the slots are open-topped, and a lift test
    confirms the frame goes in and out of the tray straight. Flare edges start
    square so nothing hooks on the way out. Slot clearance 0.35 mm.
    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
    [sleeve_frame.stl, sleeve_mold.scad, sleeve_mold_bottom.stl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]
2026-09-24 Sleeve frame: locking foot step under the outer edge
    Silicone doesn't bond to PETG, and nothing wrapped under the frame, so it
    could have worked out of the sleeve's bottom with the Stick removed. A
    0.6 x 0.6 mm step around the underside edge lets the skin form a foot under
    the frame. Verified all round except under the horn roots, where the horns
    themselves anchor it.
    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
    [sleeve_frame.stl, sleeve_mold.scad, sleeve_preview_not_for_printing.stl]
2026-09-24 Sleeve v3: sealed silicone jacket with cast-in PETG lug staples
    Replaces the frame-based sleeve. The silicone is 2.5 mm or more everywhere,
    covers the whole Stick except the screen (buttons are pressed through pads),
    and each end block buries a 3 x 5 mm PETG bar whose lug plates sweep down
    under the nose to the spring bar. Nothing under the wrist but silicone.
    Two-piece core located by pins inside the window; cup + back plate mold.
    Verified: no overlaps, staples lift straight out of the plate, cores lift
    out of the cup, cavity sealed except vents and pour hole, thicknesses as
    specified. Old frame design kept under hardware/sleeve/old/.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
    [frame_sleeve_v1.scad, sleeve_backplate.stl, sleeve_core.stl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]
2026-09-24 Split the sleeve designs: v2 (staples) in hardware/sleeve_v2, v1 (frame) stays in hardware/sleeve
    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
    [frame_sleeve_v1.scad, sleeve_backplate.stl, sleeve_core.stl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]
2026-09-24 Sleeve v2: one-piece open-top mold, single core, self-locating staples
    The back plate is gone: the sleeve's back is the surface of an open pour,
    scraped flat at the rim. One core comes out through the window. The
    staples carry sloped break-off tabs that sit in notches in the cup rim,
    setting their position and height; the notches are open upward so the
    staples drop in and the cured sleeve lifts straight out. Verified: no
    overlaps, staple and core lift paths clear, tabs seated, thicknesses held.
    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
    [sleeve_backplate.stl, sleeve_core.stl, sleeve_core_a.stl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]
2026-09-24 Sleeve v2: add fused cup+core variant (rim-down print, staples only)
    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
    [sleeve_cup_fused.stl, sleeve_mold.scad]
2026-09-24 Sleeve v2: charging tunnel with slit skin, M3 hold-down screws for the core
    The core floated in the pour (PLA at 20% infill is lighter than the silicone), so
    the pins are replaced by two M3x8 screws up through the cup floor, inside the
    window. A 14x7.5 tunnel block on the core forms a pocket to the USB-C port, closed
    by a 2 mm skin (3.5 mm at the slit ends) that is cut after curing. Port position
    measured from the M5Stack model: 4.1 mm below the face, centred. Checks: no
    core/cup/staple overlap, core lifts straight out, skin 2.0 mm normal in the middle.
    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
    [sleeve_core.stl, sleeve_cup.stl, sleeve_cup_fused.stl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]
2026-09-24 Sleeve v2: staple tabs end level with the bar top so the print has a first layer
    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
    [sleeve_core_and_mold.3mf, sleeve_cup.stl, sleeve_cup_fused.stl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]
2026-09-24 Sleeve v2: clip staple tabs at the bar plane instead of reshaping them (cup unchanged)
    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
    [sleeve_cup.stl, sleeve_cup_fused.stl, sleeve_mold.scad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]
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2026-09-25 Sleeve v2: fix mirrored width mapping (side button pads were on the wrong sides)
    The Stick model's width axis runs opposite to the sleeve's y; sy() now flips the
    sign. Only the side button pads are asymmetric, so only the cup changes; the core
    regenerates geometrically identical (0.000 mm deviation).
    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
    [sleeve_core.stl, sleeve_cup.stl, sleeve_cup_fused.stl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]
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2026-09-26 Sleeve v3: frame chassis (brackets + rails), straight rim with lid fillet ridge for the back round, M4 jack holes
    First cast: the rim undercut plus the rigid plate locked the sleeve in the cup, and
    the plate made the back too stiff to flex the Stick in and out.
    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
    [heat_45C_6hrs.3mf, sleeve_chassis.stl, sleeve_cup.stl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]
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2026-09-26 Band v5: fix comment that broke the buckle module; peg and tongues joined to the frame
    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
    [band_buckle.stl, band_preview_not_for_printing.stl, sleeve_mold.scad]
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2026-09-26 Band v5: headed peg (2.4 neck, 3.3 head) so the 3.0 hole snaps on
    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
    [band_buckle.stl, band_cup.stl, band_preview_not_for_printing.stl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]
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2026-09-26 Band v5: longer peg with a one-sided retaining bump (snaps through the hole, prints on its side cleanly)
    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
    [band_buckle.stl, band_cup.stl, band_preview_not_for_printing.stl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]
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2026-09-27 Band v5: screen-size window (deep lips both ends), flex zones, flush strap roots, rounded tail
    First cast: fit and size good; the 2 mm top lip let the Stick pop out when the
    band was tightened, and the full-width strap root left a crevice at the jacket's
    rounded corners.
    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
    [band_core.stl, band_cup.stl, band_lid.stl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]
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2026-09-27 Band v5: buckle split into a cast-in anchor and a pinned-on frame; salvage frame for the first cast
    The cast-in frame snapped at the rail roots while lifting the band out of the cup.
    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
    [band_anchor.stl, band_buckle.stl, band_core_lid.3mf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]
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2026-09-27 Band v5: looser pocket (0.15 squeeze), 1.2 mm lips, R4 window corners (top lip tore on insertion)
    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
    [band_core.stl, band_cup.stl, band_lid.stl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]
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2026-09-27 Band v5 buckle: fix offset order (frame was breaking up), rounded corners kept
    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
    [band_buckle.stl, band_cup.stl, band_preview_not_for_printing.stl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]
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2026-09-28 v5: printed 22 mm tang buckle that caps the plate (spring-bar pivot, Tropic tongue, keeper); replaces the adapter
    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
    [buckle_adapter.scad, buckle_adapter_tropic.stl, buckle_tang_22mm.stl]
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2026-09-28 v5 tang buckle: 4.5 mm far bar, snap lips behind the plate ends, 2.2 tongue, 1 mm cap rounding
    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
    [buckle_adapter.scad, buckle_tang_22mm.stl, buckle_tongue.stl]
2026-09-28 v5 tang buckle: wider scoop, 0.2 mm tongue rest clearance
    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
    [buckle_adapter.scad, buckle_tang_22mm.stl, buckle_tongue.stl]
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2026-10-01 v6: temporary fixed tongue, pinned through the lug holes with a wire
    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
    [fixed_tongue_temp.stl, sleeve_mold.scad]
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2026-10-01 v7: hole pyramids 0.9 mm deep (shorter straight hole), same 3.2 mm footprint
    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
    [band_lid.stl, band_preview_not_for_printing.stl, sleeve_mold.scad]
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2026-10-02 v8: Tropic diamond pits on the outer faces (holes at the pit centres, self-venting bumps in the cup), fixed hole columns, bigger button breather
    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
    [band_cup.stl, sleeve_mold.scad]
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2026-10-03 v8: lattice continues down the sleeve's walls as evenly spaced vertical ribs; 0.5 mm ridges; preview fix
    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
    [band_cup.stl, sleeve_mold.scad]
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
